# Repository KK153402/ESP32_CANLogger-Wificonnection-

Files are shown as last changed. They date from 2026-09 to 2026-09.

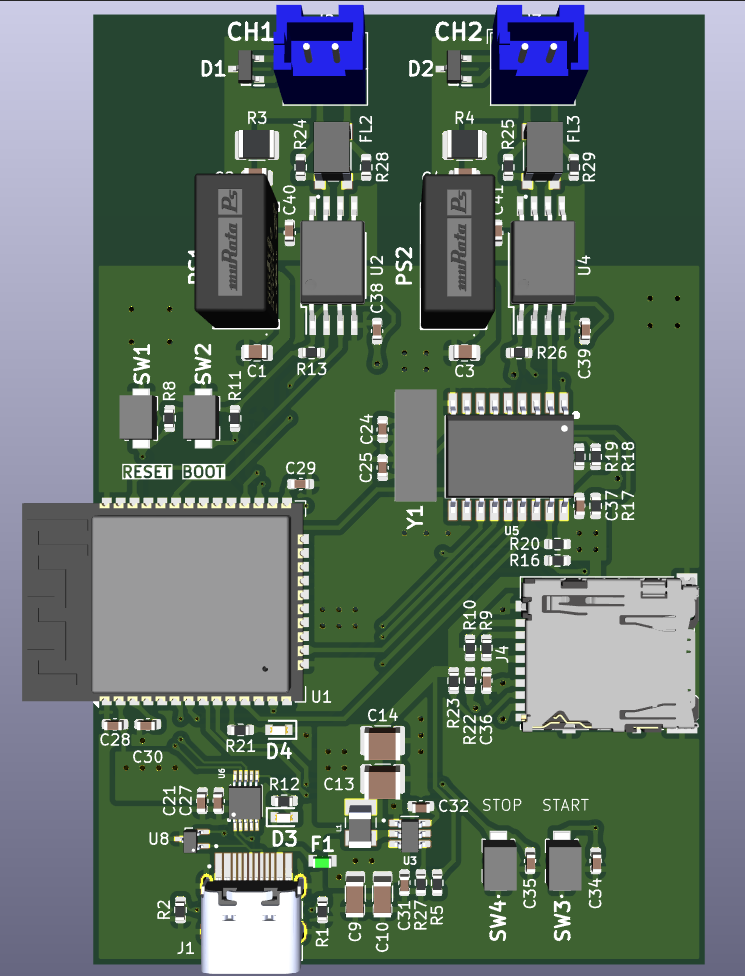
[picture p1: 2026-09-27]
images/3Dmodel_1.png

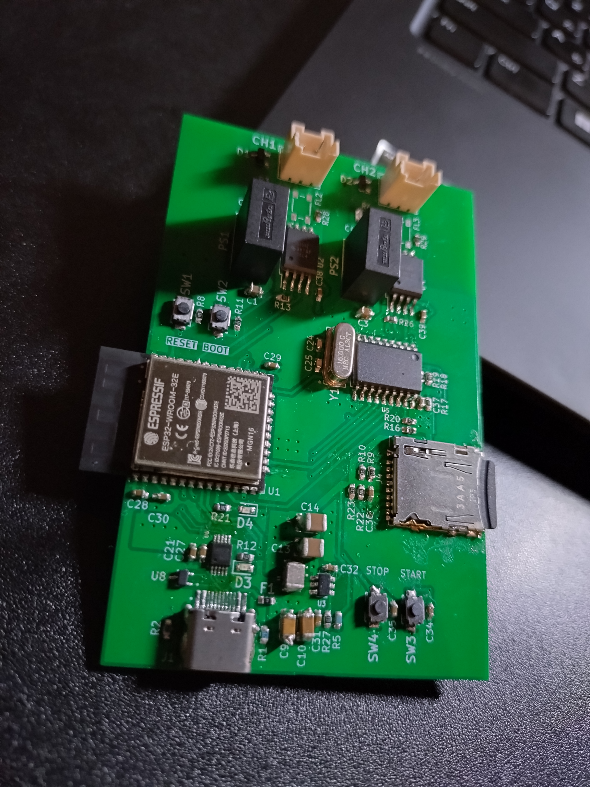
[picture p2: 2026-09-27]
images/現物.JPG

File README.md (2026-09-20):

# CanLogger

PCとCANインタフェースを持ち込めない現場で、単独でCANログを取得するための治具。
**CAN1(500kbps) / CAN2(250kbps) の2バスを同時に**SDカードへ記録し、
PC側でBLF形式へ変換してCANalyzerで解析する。

```
測定対象のCANバス ──▶ 治具（SDカードへ記録）──▶ PCでBLF変換 ──▶ CANalyzerで解析
                            │
                            └─▶ Wi-Fiで自動アップロード（v2.6〜）
```

ファームウェア **v2.7** / ハードウェア **Rev.5**

> **v2.6以降、記録したログをWi-Fi経由でサーバーへ自動送信できる。**
> 待機中にのみ動作し、記録中は完全に停止する。将来的にLTE（SIM7600JC-H）へ置き換える前提で、
> 通信方式に依存しない部分（分割・再送・進捗管理）を先に実装・検証したもの。

---

## ドキュメント

| 目的 | ファイル |
|---|---|
| **使い方**（現場での操作手順） | [`docs/USAGE.md`](docs/USAGE.md) |
| **技術解説**（プログラムの中身、初心者向け） | [`docs/TECHNICAL.md`](docs/TECHNICAL.md) |
| **設計仕様**（試算・ファイル形式・実測結果） | [`docs/DESIGN.md`](docs/DESIGN.md) |
| **ハードウェア仕様**（BOM・ピンアサイン・査読結果） | [`docs/HARDWARE.md`](docs/HARDWARE.md) |

アップロード機能について知りたい場合は、
[`docs/DESIGN.md`](docs/DESIGN.md) §7（仕様）と
[`docs/TECHNICAL.md`](docs/TECHNICAL.md) §15（設計判断の理由）を参照。

---

## 実績

実機での測定結果。

| 項目 | 結果 |
|---|---|
| CH1（500kbps） | 2,747フレーム / **取りこぼし0** |
| CH2（250kbps） | 54,263フレーム / **取りこぼし0** |
| 2ch同時記録 | 57,010フレーム / 59.16秒 |
| BLF変換 → CANalyzer再生 | **動作確認済み** |
| Wi-Fiアップロード | 1,368,272 byte を2パートで送信 / **再送・中断再開とも動作確認済み** |
| 送信速度（1MBチャンク） | 124〜166 kB/s |

---

## ハードウェア構成

```
                    ┌──── 機能絶縁境界（CH1）────┐
CN1 (CAN1 500k) ────┤ RESD1CANY → ISO1042DWV     ├─── ESP32 内蔵TWAI
                    │  NME1S0505SC + 100Ωダミー   │
                    └─────────────────────────────┘

                    ┌──── 機能絶縁境界（CH2）────┐
CN2 (CAN2 250k) ────┤ RESD1CANY → ISO1042DWV     ├─── MCP2515 (HSPI)
                    │  NME1S0505SC + 100Ωダミー   │
                    └─────────────────────────────┘

USB-C ─ TPD2E2U06 ─ MF-FSML100 ─ TPS562201 ─ 3.3V ─ ESP32-WROOM-32E-N16
                                                     ├── microSD (VSPI)
                                                     ├── MCP7940N (I2C) + CR2032
                                                     ├── 開始/停止SW、状態LED
                                                     └── CH340E (USB-UART)
```

| 主要部品 | 型番 |
|---|---|
| MCU | ESP32-WROOM-32E-N16 |
| CANトランシーバ | ISO1042DWV（絶縁）×2 |
| CANコントローラ（CH2） | MCP2515T-I/SO |
| 絶縁DC/DC | NME1S0505SC ×2 |
| RTC | MCP7940N-I/SN |
| 降圧コンバータ | TPS562201DDCR |
| USB-UART | CH340E |

詳細は [`docs/HARDWARE.md`](docs/HARDWARE.md)。

---

## ディレクトリ構成

```
CanLoggerJig/
├── platformio.ini          ビルド設定
├── src/
│   ├── main.cpp            状態機械、受信タスク、書き込みタスク、シリアルコマンド
│   ├── config.h            ピン配置・ビットレート・バッファサイズ
│   ├── ring_buffer.h       24byte固定長レコードとSPSCリングバッファ
│   ├── mcp2515.h           MCP2515ドライバ（Listen-Only、外部ライブラリ不要）
│   ├── mcp7940.h           MCP7940N RTCドライバ
│   ├── asc_format.h        ASC形式の生成（ASCモード時のみ）
│   ├── cfgfile.h           /CONFIG.TXT のパーサ
│   └── uploader.h          Wi-Fiアップロード（分割・再送・進捗管理）
├── tools/
│   ├── bin_to_blf.py       BIN → BLF 変換。ファイル形式の仕様書も兼ねる
│   ├── bin_to_blf.py.txt   同上（拡張子制限がある環境向け）
│   ├── merge_parts.py      分割パートを1つのBINへ連結
│   └── upload_server.py    検証用のHTTP PUT受信サーバ
└── docs/
    ├── USAGE.md            操作手順書
    ├── TECHNICAL.md        技術解説
    ├── DESIGN.md           設計仕様
    └── HARDWARE.md         ハードウェア仕様
```

外部ライブラリへの依存はない（`SD` / `SPI` / `Wire` / `WiFi` / `Preferences` はフレームワーク同梱）。

---

## ビルドと書き込み

### 必要なもの

- [PlatformIO Core](https://docs.platformio.org/en/latest/core/installation/)
  または VSCode + PlatformIO IDE拡張

### 手順

```bash
cd CanLoggerJig

pio run                  # ビルド
pio run -t upload        # 書き込み
pio device monitor       # シリアルモニタ（115200）
```

初回は arduino-esp32 2.0.17 のツールチェーンを自動取得するため数分かかる。

> **書き込みは手動操作が必要。** USB-UARTにCH340E（DTR#なし）を使っているため自動リセットができない。
>
> **BOOTボタンを押しながらENボタンを押して離す → BOOTを離す → `pio run -t upload`**

### ビルド環境（env）

| env | 用途 | コマンド |
|---|---|---|
| `esp32dev` | 通常構成（CH1 + CH2 + RTC）。既定 | `pio run` |
| `ch1_only` | CH1のみ。MCP2515未実装基板の検証用 | `pio run -e ch1_only -t upload` |
| `no_rtc` | RTC無し。MCP7940N未実装基板の検証用 | `pio run -e no_rtc -t upload` |
| `asc_format` | ASCテキスト保存 | `pio run -e asc_format -t upload` |

`config.h` の主要な設定値には `#ifndef` ガードがあるので、
ソースを書き換えずに `build_flags` の `-D` で上書きできる。

```ini
build_flags = -DCH2_ENABLE=0 -DCH1_BITRATE=250000UL
```

アップロード機能を外すビルドもできる。`WiFi.h` ごとリンクされなくなり、ヒープが約40KB戻る。

```ini
build_flags = -DUPLOAD_ENABLE=0
```

### バージョン固定について

`platformio.ini` で `espressif32@6.8.1`（= arduino-esp32 2.0.17）を固定している。
本ファームは `driver/twai.h` を直接使っており、arduino-esp32 3.x では
API・ヘッダ構成が変わるためビルドが通らない。

### Arduino IDE で使う場合

`src/main.cpp` は `.ino` ではないためArduino IDEでは開けない。
使う場合は `main.cpp` を `CanLoggerJig/CanLoggerJig.ino` にリネームし、ヘッダ5つを同じフォルダへ置く。
**全ての関数を呼び出し箇所より前に定義してある**ので、どちらの形式でもビルドできる。
関数を追加する際はこの順序を崩さないこと。

---

## シリアルコマンド

```bash
pio device monitor
```

| コマンド | 内容 |
|---|---|
| `SETTIME YYYY-MM-DD HH:MM:SS` | RTCに現地時刻を設定（記録中は不可） |
| `GETTIME` | 現在のRTC時刻を表示 |
| `TRIM [-127..127]` | 発振周波数の補正値を表示／設定 |
| `STATUS` | 状態・fault・ヒープ残量・RTC診断フラグ・アップロード状態 |
| `UPLOAD <LOGxxxx\|nnnn\|SCAN>` | 指定ファイルを送る／未送信を探し直す |
| `UPSTAT` | アップロードの状態を表示 |
| `WIFI` | Wi-Fiの接続状態 |
| `RELOAD` | `/CONFIG.TXT` を読み直す |
| `HELP` | コマンド一覧 |

製作時に一度 `SETTIME` すれば、CR2032が切れるまで保持される。

```
> STATUS
state=IDLE  rtc=2026-09-01 15:01:50  fault=none  freeheap=164152
rtc flags: OSCRUN=1 PWRFAIL=0 VBATEN=1 (RTCWKDAY=0x2B)  trim=+0 (+0.0 ppm)
upload  : phase=idle  boot#=4  ok=6  fail=0  sent=1715725 byte
          last: LOG0006 uploaded (2 parts)
wifi    : your-ssid  ip=192.168.10.106  rssi=-43 dBm
policy  : A (everything auto)
dest    : http://192.168.10.104:8080/canlog/JIG001/  chunk=1024 KB
```

---

## ログの自動アップロード

待機中にSDカードを走査し、未送信のログをHTTP PUTでサーバーへ送る。
**記録中は完全に停止する**ので、ログの取りこぼしには影響しない。

### 設定

SDカードのルートに `CONFIG.TXT` を置く。

```
WIFI_SSID     = your-ssid
WIFI_PASS     = your-password
UP_ENABLE     = 1
UP_AUTO       = 1          # 1=待機中に自動送信 / 0=UPLOADコマンドのみ
UP_STATS_ONLY = 0          # 1=統計TXTだけ送る
DEVICE_ID     = JIG001
UP_HOST       = 192.168.10.104
UP_PORT       = 8080
UP_PATH       = /canlog
UP_CHUNK_KB   = 1024
UP_RETRY_MAX  = 10
```

ファイルが無い場合は既定値で起動し、アップロードは無効のまま記録だけ動く。

> Wi-Fiのパスワードは平文でSDに載る。検証用の専用SSIDを使うこと。

### 受信側

検証用のサーバーを同梱している。SORACOM Harvest Files と同じ
「PUTしたパスにそのまま置く」挙動を模しているので、将来LTEへ切り替えても治具側は変わらない。

```bash
python3 tools/upload_server.py --dir ./received --port 8080
```

| オプション | 用途 |
|---|---|
| `--fail-rate 0.3` | 30%の確率で500を返す（再送処理の検証） |
| `--drop-rate 0.2` | 20%の確率で応答せず切断する |
| `--slow 50` | 1KBごとに50ms待つ（低速回線の模擬） |

### 届くファイル

```
received/canlog/JIG001/
    20260901_150227_LOG0006.txt        統計ファイル（先に送られる）
    20260901_150227_LOG0006_001.bin    ログ本体（1MBごとに分割）
    20260901_150227_LOG0006_002.bin
```

分割されたBINは連結してから `bin_to_blf.py` にかける。

```bash
python3 tools/merge_parts.py received/canlog/JIG001
```

### 設計上の要点

| 項目 | 内容 |
|---|---|
| **記録優先** | `ST_LOGGING` / `ST_DRAINING` では完全停止。開始ボタンで送信を即中断 |
| **統計ファイルを先に送る** | 数KBで「そのログが信用できるか」を遠隔判定できる |
| **1MBずつ分割** | 中断・切断時の再送単位を小さくする。固定費の実測から1MBが最適 |
| **冪等な再送** | 同一パスへの再送は上書き。何度リトライしても結果が同じ |
| **SDから消さない** | 送信済みでもカードに残す。SDが最後の砦 |
| **通信層は3関数に限定** | LTE化時は `upWifiUp` / `upWifiDown` / `upPutRange` の差し替えのみ |

詳細は [`docs/DESIGN.md`](docs/DESIGN.md) §7。

---

## PC側変換ツール

```bash
cd tools
pip install python-can

python bin_to_blf.py LOG0001.BIN -o LOG0001.blf
```

| オプション | 内容 |
|---|---|
| `-o` | 出力先。省略時は入力名 + `.blf` |
| `--start` | 計測開始の実時刻。省略時は「ヘッダの `unix_time` → それが0なら入力ファイルの更新時刻」の順 |
| `--tz-offset` | CANalyzer表示用の補正量[時間]。省略時はPCのタイムゾーン（日本なら+9） |
| `--utc` | 補正せずUTCのまま出力 |

> **タイムゾーン**: python-canはBLFヘッダへUTCを書くが、CANalyzerはそれを現地時刻として
> 表示するため、補正しないと9時間ずれる。既定で補正している（相対時刻は不変）。

BLF内のチャネル番号は 1 = CAN1 / 2 = CAN2 になり、CANalyzerの設定とそのまま一致する。

ASCモードで取得した場合は python-can 同梱のコンバータでも変換できる。

```bash
python -m can.logconvert LOG0001.ASC LOG0001.blf
```

---

## 設計上の要点

| 項目 | 内容 |
|---|---|
| **Listen-Only** | 両chともACKを返さず、バスに一切影響を与えない |
| **受信と書き込みの分離** | 受信タスクは打刻とリングへの積み込みのみ。SD書き込みは別コア |
| **リングバッファ** | SDカードの数百msの停止を吸収（実測では1024段中12段しか使用せず） |
| **バイナリ保存** | ASCテキストの約1/3のデータ量。SD速度の余裕を確保 |
| **縮退保存** | 異常時もそこまでのログと統計を必ず残す |
| **統計ファイル** | ログの信頼性を現地で判定できるようにする |
| **アップロードは待機中のみ** | 記録中はSDもCPUも奪わない。中断は1KBごとに判定 |
| **大物バッファはヒープ確保** | 通信スタックの静的領域圧迫を回避（v2.7） |

詳細な理由は [`docs/TECHNICAL.md`](docs/TECHNICAL.md)。

---

## 未了項目

**ファームウェア**

- [ ] RTCの校正（1号機は約+30ppm進む。`TRIM` で補正。[`docs/HARDWARE.md`](docs/HARDWARE.md) §11.6）
- [ ] RTC電池での時刻保持確認（電源断→復帰で `PWRFAIL=1` になること）
- [ ] ファイル自動分割（FAT32 4GB上限対策）
- [ ] **実バスでの干渉試験**（アップロード中に `ring dropped` が0のままか）
- [ ] 長時間連続試験（72時間以上。`freeheap` が単調減少しないこと）
- [ ] LTE（SIM7600JC-H）への置き換え
- [ ] 圧縮（gzip）の実装
- [ ] 遠隔コマンド（サーバー上のコマンドファイルをポーリング）
- [ ] 起動バナーと統計ファイルのバージョン文字列を `v2.7` へ更新

**ハードウェア（次版）**

- [ ] RTC水晶を **CL=6〜7pF品** へ変更（MCP7940Nは6〜9pFに最適化）
- [ ] 3.3Vバイパスコンデンサの配置割当確定（SDソケット直近を最優先）

**運用**

- [ ] 筐体設計
- [ ] 治具ラベル（「制御系CAN専用。高電圧バスに接続しないこと」）

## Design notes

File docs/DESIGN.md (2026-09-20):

# CANログ取得治具 設計仕様 v2.7（2ch同時記録 + RTC + Wi-Fiアップロード）

> ビルド手順・ディレクトリ構成はプロジェクトルートの [`../README.md`](../README.md) を参照。

PCとCANインタフェースを持ち込めない現場で、単独でCANログを取得するための治具。
CAN1(500kbps) / CAN2(250kbps) の**2バスを同時に**SDカードへ記録し、PC側スクリプトでBLFへ変換して解析側へ送る。

部品表・ピンアサイン・基板設計指針は [`HARDWARE.md`](HARDWARE.md)、
プログラムの中身の解説は [`TECHNICAL.md`](TECHNICAL.md)、
現地での操作手順は [`USAGE.md`](USAGE.md) を参照。

```
測定対象 CAN1(500k)                    測定対象 CAN2(250k)
   │                                    │
   ├ RESD1CANY → ISO1042DWV             ├ RESD1CANY → ISO1042DWV
   ├ ESP32内蔵TWAI                      ├ MCP2515 (HSPI)
   │  Listen-Only                       │  Listen-Only
   └──────┬─────────────────────────────┘
          │  rxTaskTwai / rxTaskMcp (core1) : 打刻してリングへ
          │  writerTask (core0) : 時刻順マージ → SDへ
          │
   ESP32-WROOM-32E-N16
          ├ microSD (VSPI) → LOG0001.BIN / LOG0001.TXT(統計)
          ├ MCP7940N (I2C) → 記録開始時刻
          ├ 開始/停止ボタン
          ├ 状態LED
          └ Wi-Fi → uploadTask (core0) : 待機中にHTTP PUTで送信
```

**変更履歴**

| 版 | 内容 |
|---|---|
| v1.0 | 1ch（DIPでボーレート切替）、ASCテキスト保存 |
| v2.0 | CH1+CH2同時記録（CH2にMCP2515追加）、24byte固定長バイナリ保存を既定化 |
| v2.1 | コードレビュー反映。異常時の復帰不能バグ修正と縮退保存、MCP2515サンプルポイント是正、PlatformIO化 |
| v2.2 | 基板確定に伴う対応。RTC（MCP7940N）から実時刻を取得、シリアルコマンド追加、MCP2515の/RESETをGPIO駆動 |
| v2.3 | 実機ログの解析でCH2の取りこぼしを修正（ISRのタスク切り替え要求漏れ）。§3.1参照 |
| v2.4 | v2.3で作り込んだCH2受信タスクのビジーループを修正。§3.3参照 |
| v2.5 | 査読反映。STATUSにRTC診断フラグ追加、空BIN削除、drain中fault反映、TRIMコマンド追加 |
| v2.6 | ログの自動アップロード（Wi-Fi）。分割送信・再送・進捗管理・設定ファイル。§7参照 |
| v2.7 | Wi-Fi有効時のDRAM不足を解消（リング等をヒープ確保へ）。実機検証で見つかった3件を修正。§7.9参照 |

---

## 1. 構成の考え方

### 1.1 なぜCH2をMCP2515にするか

ESP32(classic)の内蔵TWAIコントローラは**1chしかない**ため、2バス同時記録には外付けコントローラが必須。
負荷の高い500kbpsを内蔵TWAI、250kbpsをMCP2515に割り当てている。

| | CH1 = 内蔵TWAI | CH2 = MCP2515 |
|---|---|---|
| 受信バッファ | HW FIFO + ドライバキュー128段 | RXB0/RXB1の2段（BUKTロールオーバ有効） |
| ビットレート | 500 kbps | 250 kbps |
| 上限フレームレート | 約4,000 frame/s | 約2,250 frame/s |
| 連続フレームの到着間隔 | 約250 µs | 約444 µs |
| 許容サービス時間（2段） | — | 約888 µs |
| 実測見込みの読み出し時間 | — | 50〜100 µs（INT応答 + SPI 14byte @10MHz） |

CH2は余裕率およそ8倍あり、250kbpsであれば2段バッファでも成立する。
**将来CH2も500kbpsにする場合は許容時間が約500µsまで縮む**ので、その時は再評価が必要。

### 1.2 Listen-Onlyで動かす

両chともACKを返さない完全な受信専用モードで動作するため、バスに一切影響を与えない。
その代わり**ボーレートを間違えてもエラーを出さず「0件で終わる」**。
統計ファイルにCH1/CH2それぞれの受信0件警告を出すようにしている。

---

## 2. スループット試算

### 2.1 「取得したい信号数1000〜2000」の解釈

これはDBC上の**シグナル数**であり、治具の負荷とは直接関係しない。
治具はDBCを持たず生フレームを丸ごと記録するので、シグナルが何本あっても動作は変わらない。
効くのは**フレームレート [frame/s]** だけ。デコードはPC側の CANalyzer + DBC で行う。

### 2.2 物理上限（設計最悪値）

| チャネル | 条件 | 上限フレームレート |
|---|---|---|
| CH1 | 500 kbps / 8byte | 約3,800〜4,500 frame/s |
| CH2 | 250 kbps / 8byte | 約1,900〜2,250 frame/s |
| 合計 | — | **約6,250 frame/s** |

### 2.3 データ量とSD書き込み速度

| 保存形式 | 1フレーム | 6,250 frame/s | 10分 | 1時間 |
|---|---|---|---|---|
| **バイナリ（既定）** | 24 byte | 約150 kB/s | 約90 MB | 約540 MB |
| ASCテキスト | 約64 byte | 約400 kB/s | 約240 MB | 約1.4 GB |

Arduino-ESP32 標準 `SD`（SPI 20MHz）の実効書き込み速度は概ね300 kB/s〜1 MB/s。
2ch同時記録でASCテキストを選ぶと400 kB/sとなり成立しないカードが出てくるため、
**既定を24byte固定長バイナリにしている**。150 kB/s なら十分な余裕がある。

ASCモードは `pio run -e asc_format` で使える。現地でテキストとして中身を確認したいときのデバッグ用。

### 2.4 バッファ設計

| リング | 段数 | サイズ | 吸収できるSD停止時間 |
|---|---|---|---|
| CH1 | 2048 | 約49 KB | 約0.5秒（4,000 frame/s時） |
| CH2 | 1024 | 約25 KB | 約0.45秒（2,250 frame/s時） |

安価なSDカードは内部GCで数百ms書き込みが止まることがあるため、その吸収が目的。
記録終了時に `ring max used` を統計ファイルへ残すので、実機で余裕を確認したうえで
`config.h` の `RING_SIZE_CH1 / RING_SIZE_CH2` を調整できる。

ESP32-WROOM-32E-N16 のフラッシュは16MBだが**SRAMは520KB**（実使用可能なDRAMは約320KB）。
リングを増やす際はヒープ残量（起動時にシリアルへ出力する）を確認すること。

### 2.5 記録時間の上限

FAT32の1ファイル上限は4GB。バイナリ150 kB/s なら約7.4時間まで1ファイルで記録できる。
「10分程度」の要求に対しては十分だが、それ以上を常用するならファイル自動分割（今後の課題）を入れる。

---

## 3. 実機測定の結果（2026-08-10 / LOG0002）

測定対象のCH2（250kbps）に接続して6.16秒間記録した結果。

| 項目 | 値 |
|---|---|
| フレーム数 | 4,426（平均 719 frame/s） |
| ID種類数 | 40（標準ID 25 + 拡張ID 15） |
| 周期構成 | 10ms×6種、20ms×3種、100ms×多数、1000ms×多数 |
| `bus err alerts` | 0 |
| リング最大使用 | 12 / 1024 |
| SD書き込み最大 | 4,831 µs |

**実測フレームレート719 frame/s** は設計最悪値（CH2で2,250 frame/s）に対して3割程度。
リングバッファも1024段中12段しか使っておらず、**SD側・バッファ側は大幅に余裕がある**ことが確認できた。

### 3.1 v2.2で発生していた取りこぼしと修正

周期メッセージの欠落を数えたところ、**全体の1.21%（54フレーム）**が失われていた。
特にID 341（20ms周期）は17.3%が欠落。

原因は `mcpIsr()` で `portYIELD_FROM_ISR()` を行っていなかったこと。
`vTaskNotifyGiveFromISR()` の第2引数に `nullptr` を渡していたため、
ISRから抜けるときにタスク切り替えが要求されず、**CH2受信タスクの起床が
次のティック（最大1ms）まで遅れていた**。

測定データがこれを裏付けている。

| 観測 | 内容 |
|---|---|
| 1回の起床で読んだフレーム数 | 1件…1,672回 / **2件…1,311回** / 3件…44回 |
| 起床間隔の最小値 | **999 µs**（1000µs未満は3,026回中わずか9回） |

250kbpsでは8byteフレームが約444µs間隔で到着するため、1ms待つと
MCP2515のRXB0/RXB1がちょうど埋まり、3フレーム目で溢れる。

**v2.3での修正**

1. `mcpIsr()` で `portYIELD_FROM_ISR()` を実行する（起床遅延を1ms → 数十µsへ）
2. `/INT` がLowの間は通知を待たずに読み出しを継続する
   （MCP2515の `/INT` はレベル出力のため、ドレイン中に届いたフレームでは
   新しい立ち下がりエッジが出ず、エッジ検出を取りこぼす経路があった）

### 3.2 v2.3で作り込んだ不具合（v2.4で修正）

v2.3で `/INT` のレベルチェックを追加した際、**「記録中でない」判定をその後ろに置いてしまった**。

```cpp
if (digitalRead(MCP_INT_GPIO) == HIGH) {   // Lowだとここを通らない
  ulTaskNotifyTake(...);
}
if (g_state != ST_LOGGING || !g_mcpReady) continue;   // 待機中はここで戻る
```

**CH2をバスに接続した待機状態**では `/INT` がLowに張り付くため、
どこでもブロックせずにループが回り続ける。このタスクは優先度19でコア1に固定されており、
優先度1の `loopTask`（`setup()` と `loop()` が動く）を完全に飢餓状態にする。

症状は次のとおりで、CH2を接続していない環境では再現しない。

- `setup()` の最後の2行（`free heap after init` / `type HELP ...`）が出力されない
- シリアルコマンドが一切効かない
- 開始/停止ボタンが効かない
- LEDが更新されない（消灯のまま）

**v2.4での修正**: 状態判定を先頭へ移し、記録中でなければ必ず `vTaskDelay()` で眠るようにした。
あわせて、`/INT` がLowのままフレームが読めない異常時の保険として、
1件も読めなかった場合に `vTaskDelay(1)` を入れている。

### 3.3 タイムスタンプ精度について（解析側への申し送り）

ESP32のTWAIもMCP2515も**ハードウェア受信タイムスタンプを持たない**。
本ファームは受信タスクがフレームを取り出した時刻を打刻している。

| 項目 | CH1（内蔵TWAI） | CH2（MCP2515） | PC接続型インタフェース |
|---|---|---|---|
| タイムスタンプ源 | ソフトウェア（esp_timer, 1µs分解能） | 同左（INT応答分の遅れが加わる） | ハードウェア |
| 通常時の誤差 | ±数十µs | ±100µs程度 | ns〜µs |
| バースト時 | キュー滞留分だけ遅れる（最大数ms） | 同左 | 影響なし |
| ch内のフレーム順序 | 保証される | 保証される | 保証される |
| エラーフレーム | **記録不可**（統計カウントのみ） | **記録不可**（同左） | オブジェクトとして記録 |

**ch間の相対時刻は同じesp_timerで打刻しているので比較可能**だが、上記の誤差が乗る。

RTC（MCP7940N）が与えるのは「計測開始が実世界の何時何分か」というアンカーだけで、
フレーム間隔の精度には関与しない。

本治具のログは**シーケンスと中身の解析**用と位置づけ、バス負荷率・フレーム間ギャップ・
エラーフレーム解析が必要な案件はPC接続型のCANインタフェースで取得する、という線引きを
治具の配布前に関係者間で合意しておきたい。

---

## 4. LED表示と異常時の挙動

| 状態 | LED | 意味 |
|---|---|---|
| 待機 | 消灯 | 電源ON・SD認識済み・MCP2515疎通OK。開始ボタン待ち |
| **アップロード中** | **1秒周期で短点滅2回** | **待機中にログを送信している。SDを抜かないこと** |
| 記録中 | 200ms周期で点滅 | CANログ取得中。SDを抜かないこと |
| 停止 | 点灯（continuous） | ファイルクローズ完了。**SD取り外し可** |
| 異常 | 80ms周期で高速点滅 | 下表参照。開始ボタンで再試行 |

停止処理（残データの書き出しとファイルクローズ）が終わってから点灯に切り替わるので、
**LEDが点灯したことがSD取り外し可の合図**になる。

アップロード中は点滅が `ST_STOPPED` の点灯を上書きする。
結果として「点灯に戻るまで待てばSD抜去が安全」という動作になり、都合がよい。

記録中に異常が起きた場合も、いきなり高速点滅に移るのではなく
**そこまでのログの書き出し・ファイルクローズ・統計ファイル出力を済ませてから**高速点滅になる（縮退保存）。
そのため異常終了でも `LOG0001.BIN` と `LOG0001.TXT` は残り、統計ファイルの `fault` 行に要因が記録される。

| fault | 意味 |
|---|---|
| `SD card not found / mount failed` | SDカード未挿入または認識不良 |
| `cannot create log file on SD` | 書き込み保護／FAT破損／容量不足 |
| `SD write failed (card full or bad contact)` | 記録中の書き込み失敗。容量または接触を確認 |
| `CH1 TWAI driver init failed` | 内蔵TWAIの初期化失敗（通常は起こらない。要報告） |
| `CH2 MCP2515 not responding` | MCP2515のSPI疎通不良（基板不良・はんだ不良） |
| `CH1 bus off` | CH1がBus Off（Listen-Onlyでは通常起こらない。要報告） |

高速点滅からは**開始ボタンで復帰できる**（内部の後始末をやり直してから記録を開始する）。
復帰しない場合は電源を入れ直す。

なお**RTCの異常では停止しない**。時刻が読めない場合は `unix_time = 0` として記録を続行し、
統計ファイルに注記を残す。

---

## 5. 操作手順（概要）

1. 治具の電源を入れる（LED消灯＝待機。高速点滅ならSDカードを確認）
2. CH1コネクタを500kbps側、CH2コネクタを250kbps側の取得ポイントへ接続する
3. **開始ボタン**を押す → LEDが点滅を始める
4. 事象を再現させる
5. **停止ボタン**を押す → LEDが点灯に変わるまで待つ
6. LED点灯後にSDカードを抜く（点滅中に抜くとファイルが壊れる）
7. `LOG0001.TXT` を開き、以下を確認する
   - `exit` が `normal (stop button)` であること
   - `start time` が正しいこと（大きくずれていればRTCの電池切れ）
   - CH1 / CH2 それぞれの `frames logged` が0でないこと
   - `ring dropped` / `ctrl missed` / `ctrl ovf events` がすべて0であること
   - `*** WARNING` の行が無いこと（すべて問題なければ `result : OK` が出る）
8. `LOG0001.BIN` と `LOG0001.TXT` を解析側へ送付する

> **`ctrl ovf events` の読み方**
> この値はMCP2515のオーバフロービットを200ms周期でポーリングして検出した**回数**であり、
> 落ちたフレーム数ではない（1回のカウントに複数フレームの欠落が含まれ得る）。
> **0でなければ取りこぼしあり、数は不定**と判断する。
> CH1側の `ctrl missed` はドライバがフレーム数で数えているのでこちらは実数。

---

## 6. 出力ファイルとBLF変換

### 6.1 LOG0001.BIN（既定）

リトルエンディアン。ヘッダ32byte + 24byte固定長レコード × N。

**ヘッダ 32byte**

| offset | 型 | 内容 |
|---|---|---|
| +0 | char[8] | magic `"CANLOG02"` |
| +8 | uint16 | version = 2 |
| +10 | uint16 | record_size = 24 |
| +12 | uint32 | CH1 ビットレート [bps] |
| +16 | uint32 | CH2 ビットレート [bps]（0ならCH2無効） |
| +20 | uint32 | 計測開始のUNIX時刻（**UTC**）。0ならRTC無効/未設定 |
| +24 | uint64 | t0_us：計測開始時刻（治具のesp_timer基準） |

**レコード 24byte**

| offset | 型 | 内容 |
|---|---|---|
| +0 | uint64 | ts_us：受信時刻（esp_timer基準の絶対値） |
| +8 | uint32 | ID（11bit または 29bit） |
| +12 | uint8 | DLC（0..8） |
| +13 | uint8 | flags：bit0 = 29bit ID / bit1 = リモートフレーム |
| +14 | uint8 | channel：1 = CH1 / 2 = CH2 |
| +15 | uint8 | reserved（0固定） |
| +16 | uint8[8] | データ |

レコードは**チャネル内では時刻順**だが、チャネル間の順序は保証していない
（ファーム側で約5msのマージ窓を持たせているが、保険としてPC側で必ず時刻ソートする）。

### 6.2 BLFへの変換

```bash
pip install python-can
python tools/bin_to_blf.py LOG0001.BIN -o LOG0001.blf
```

RTCが動作していれば `unix_time` が入っているので、**開始時刻の手入力は不要**。
省略時は「ヘッダの `unix_time` → それが0なら入力ファイルの更新時刻」の2段フォールバックになる。
明示指定したい場合のみ `--start "2026-08-09 14:05:00"` を使う。

BLF内のチャネル番号は 1 = CAN1 / 2 = CAN2 になり、CANalyzerの設定とそのまま一致する。

#### タイムゾーンの扱い

治具は `unix_time` に**UTC**を格納する。一方 python-can は BLFヘッダの計測開始時刻
（SYSTEMTIME）へ**UTCをそのまま書き込む**が、**CANalyzer はこのフィールドを
現地時刻として表示する**。そのため補正しないと、CANalyzer 上で9時間前にずれる。

`bin_to_blf.py` は**既定で現地のUTCオフセットを全タイムスタンプに加算**し、
CANalyzer に現地時刻が表示されるようにしている。
全フレームを同じ量だけずらすので、**フレーム間の相対時刻は変わらない**（実データ4,426件で検証済み）。

| オプション | 動作 |
|---|---|
| （既定） | このPCのタイムゾーンで補正。日本なら +9時間 |
| `--tz-offset 9` | 補正量を時間単位で明示指定 |
| `--utc` | 補正せずUTCのまま出力（従来動作） |

治具の記録開始が 15:02:27（JST）の場合の表示。

| モード | CANalyzer の Start |
|---|---|
| 既定 | **2026-09-01 15:02:27** |
| `--utc` | 2026-09-01 06:02:27 |

**動作確認済み**: python-can 4.6.1 にて、C側の構造体（`ring_buffer.h` の `CanRec` / `BinHeader`）で
書き出したバイナリを `bin_to_blf.py` でBLF化し、`can.BLFReader` で読み戻して
標準ID / 29bit ID / リモートフレーム / DLC=0 / 2chの時刻順マージ / RTC時刻の反映
が欠落なく往復することを確認した。ASC経路（`asc_format.h` → `can.logconvert` → BLF）も確認済み。

### 6.3 LOG0001.TXT（統計）

CH1/CH2ごとのフレーム数・取りこぼし数・リング最大使用量、SD書き込み最大所要時間、
記録開始時刻、終了種別（`exit`）と異常要因（`fault`）を記録する。
**ログの信頼性判定はこのファイルで行う。** 読み方は §5 の手順7を参照。

---

## 7. ログの自動アップロード（v2.6 / v2.7）

記録したログをWi-Fi経由でサーバーへ自動送信する。
将来的にLTE（SIM7600JC-H）へ置き換えて遠隔回収する計画で、
**通信方式に依存しない部分を先に作って検証する**のがこの実装の位置づけ。

設計判断の背景は [`TECHNICAL.md`](TECHNICAL.md) §15 を参照。

### 7.1 目的と優先順位

| # | 目的 | 重み |
|---|---|---|
| 1 | 現地へ行かずに「録れたか」「そのログは信用できるか」を確認する | **最優先** |
| 2 | ログ本体を回収する | 二番目 |

統計ファイル（`LOGxxxx.TXT`、1〜2KB）には `exit` / `ring dropped` / `ctrl missed` が入っており、
**数KBの通信だけでログの信頼性を判定できる**。
このため統計ファイルをログ本体より**先に**送る。

### 7.2 大原則

> **LTE/Wi-Fiが動かなくても、記録機能は絶対に止めない。**
> **記録中はアップロードを一切動かさない。**

動作条件は1か所（`upCanRun()`）で判定する。

| 状態 | アップロード |
|---|---|
| `ST_LOGGING` / `ST_DRAINING` | **停止** |
| `FAULT_SD_INIT` / `FAULT_SD_WRITE` | **停止** |
| `ST_IDLE` / `ST_STOPPED` / `ST_ERROR`（SD以外の異常） | 動作 |

`ST_ERROR` でも動かすのは、そこまでのログを回収したいため。

### 7.3 中断のハンドシェイク

開始ボタンが押されたとき、`startLogging()` は次の順で手放させてから記録を始める。

```
uploaderRequestStop()    中断を要求
uploaderWaitIdle(3000)   SDハンドルを閉じるまで待つ
uploaderWifiOff()        Wi-Fiを落とす
  ↓
hardCleanup() / SD.end() / SD.begin()
```

**順序を逆にすると、アップロード側が握っている `File` が無効なまま参照される。**

中断判定は送信ループの1KBごとに入れており、実測で数十msで抜ける。

### 7.4 タスク構成

```
Core 1 : rxTaskTwai(20) / rxTaskMcp(19) / loop(1)
Core 0 : writerTask(5) / uploadTask(3)      ← 追加
```

優先度3は `writerTask` より低い。送信ループには1KBごとに `vTaskDelay(1)` を入れており、
`loop()` を飢餓状態にしない（v2.3のバグ2と同種の事故を避けるため）。

### 7.5 送信の単位とパス

| part | 中身 |
|---|---|
| 0 | 統計ファイル `LOGxxxx.TXT` |
| 1..N | ログ本体を `UP_CHUNK_KB` ごとに分割したもの |

```
<UP_PATH>/<DEVICE_ID>/<stamp>_LOG0006.txt
<UP_PATH>/<DEVICE_ID>/<stamp>_LOG0006_001.bin
<UP_PATH>/<DEVICE_ID>/<stamp>_LOG0006_002.bin
```

`stamp` はBINヘッダの `unix_time` から作った `YYYYMMDD_HHMMSS`。RTC未設定なら `nortc`。
**LOG番号を必ず含めるので、RTCが壊れていてもSDカード内で一意になる。**

PC側では `tools/merge_parts.py` で連結してから `bin_to_blf.py` にかける。

### 7.6 分割サイズの根拠（実測）

| チャンクサイズ | 実効速度 | 1パートあたりの固定費 |
|---|---|---|
| 16 KB | 89〜94 kB/s | **約80 ms** |
| **1024 KB（既定）** | **124〜166 kB/s** | 無視できる |

固定費はTCP接続とHTTP往復に由来する。
**LTEではATコマンドの往復（`AT+HTTPINIT` 〜 `AT+HTTPTERM`）が毎パート発生するため、この固定費はさらに大きくなる。**

| チャンク | 1MBログの送信時間（LTE概算） |
|---|---|
| 16 KB | 64パート × 約12秒 ≈ 13分 |
| 1024 KB | 1パート × 約12秒 ≈ 12秒 |

**既定の1024KBを維持すること。** SORACOM Harvest Files のセルラー経由上限（100 MiB）にも収まる。

### 7.7 壊れたファイルを残さない

HTTP PUTは `Content-Length` を先に宣言するため、途中で切れるとサーバー側が検出できる。

```
[23:48:41] SHORT  .../LOG0006_001.bin  7168/1048576 byte   ← 400で拒否
[23:49:02] PUT OK .../LOG0006_001.bin  1048576 byte        ← 再送で上書き
```

**同一パスへの再送は上書きになるため、リトライは冪等**。
SORACOM Harvest Files も同じ挙動なので、LTE化しても変わらない。

### 7.8 進捗の管理（/UPLOADED.TXT）

追記のみのテキスト。

```
0006,P,000,1024        part 0（統計TXT）完了。末尾はチャンクサイズ[KB]
0006,P,001,1024        part 1 完了
0006,D,002,1368272     全パート完了（総パート数, 総バイト数）
```

起動時に `D` の行を読んで完了ビットマップ（1250バイト）を作る。
再開時は該当LOG番号の最大 `P` を探し、その次のパートから送る。

**チャンクサイズを一緒に記録しているのが要点。**
パート番号はチャンクサイズを前提にした値なので、設定を変えると同じ番号でも指すオフセットが変わる。
照合して不一致なら進捗を無効とし、先頭から送り直す。

**送信できたファイルもSDからは削除しない。** SDカードが最後の砦であるため。

### 7.9 メモリ設計の変更（v2.7）

Wi-Fiスタックが約40KBの静的バッファを持ち込むため、リングバッファを静的確保したままでは
リンクが通らなくなった。

```
region `dram0_0_seg' overflowed by 2488 bytes
```

ESP32の静的データ（`.bss`）は固定サイズ領域に収める必要があり、ヒープはその外側のDRAMも使える。
そこで大物をヒープ確保へ移した。

| バッファ | サイズ | v2.6まで | v2.7 |
|---|---|---|---|
| `g_ring1` | 49,152 B | 静的 | **ヒープ** |
| `g_ring2` | 24,576 B | 静的 | **ヒープ** |
| `g_wbuf` | 4,176 B | 静的 | **ヒープ** |

確保は `setup()` でタスク生成より前に行い、失敗したら `FAULT_NO_MEMORY` で `ST_ERROR` へ落とす。

実測値は次のとおり。

| 時点 | `freeheap` |
|---|---|
| 起動直後 | 297,220 byte |
| **初期化完了後** | **164,152 byte** |

**リングサイズの制約は「静的領域に入るか」から「ヒープに余裕があるか」に変わった。**

### 7.10 設定ファイル（/CONFIG.TXT）

SSIDや送信先をソースに直書きすると、変更のたびに再ビルドと手動書き込み（BOOT+EN）が必要になる。
SDカードのルートに置いたテキストから読む。

```
WIFI_SSID     = your-ssid
WIFI_PASS     = your-password
UP_ENABLE     = 1
UP_AUTO       = 1
UP_STATS_ONLY = 0
DEVICE_ID     = JIG001
UP_HOST       = 192.168.10.104
UP_PORT       = 8080
UP_PATH       = /canlog
UP_CHUNK_KB   = 1024
UP_RETRY_MAX  = 10
```

| 項目 | 仕様 |
|---|---|
| パーサ | 自前実装。**外部ライブラリ非依存・動的メモリ確保なし** |
| 不在時 | 既定値で起動。`WIFI_SSID` が空ならアップロードは無効のまま動く |
| 不正時 | 該当行を無視して警告を出し、**起動は継続する** |
| 再読込 | シリアルコマンド `RELOAD` |

> **Wi-Fiのパスワードは平文でSDに載る。** 検証用の専用SSIDを使うこと。LTE化で解消される。

### 7.11 実機検証の結果

| # | 検証項目 | 結果 |
|---|---|---|
| 1 | 基本のアップロード | OK（6ファイル連続、`fail=0`） |
| 2 | 分割送信 | OK（1,368,272 byte → 2パート） |
| 3 | データ整合性 | OK（`merge_parts.py` で `frames=57010`。統計の CH1 2747 + CH2 54263 と一致） |
| 4 | チャンクサイズ変更時の進捗リセット | OK |
| 5 | **中断時に不完全ファイルを残さない** | OK（400拒否 → 再送で上書き） |
| 6 | **記録中のゲート** | OK（`phase=blocked`） |
| 7 | **中断された指定要求の再開** | OK（`resume from 1` で続きから完走） |
| 8 | 中断を失敗に数えない | OK（2回中断しても `fail=0`） |
| 9 | 記録終了後の自動継続 | OK |

**未検証: 「アップロードがCAN受信を妨げていないか」**は実バスが必要なため持ち越し。
設計上は記録中にアップロードタスクが完全停止するため問題ないはずだが、
`ring dropped = 0` を実測で押さえること。

### 7.12 検証で見つかった不具合（すべて修正済み）

| # | 不具合 | 原因 | 対策 |
|---|---|---|---|
| 1 | `UP_STATS_ONLY=1` のとき手動コマンドでもBINが送られない | 自動／手動を区別せず設定フラグを見ていた | 明示指定時は設定を無視する |
| 2 | チャンクサイズを変えると欠けたファイルができる | 進捗記録がチャンクサイズを持っていなかった | 進捗行に記録し、不一致なら無効化 |
| 3 | 中断された `UPLOAD` 指定が消える | 「指定」と「走査やり直し」を同じ変数に入れていた | 別変数に分離し、指定を優先 |

不具合3は**遠隔コマンドでログを取りに行く運用では致命的**だった。
記録が終わるたびに必ず走査要求が出るため、中断された指定要求は100%失われていた。
詳細は [`TECHNICAL.md`](TECHNICAL.md) §16 バグ6〜8。

### 7.13 LTE化への引き継ぎ

差し替えるのは3関数のみ。

| 関数 | Wi-Fi版 | LTE版 |
|---|---|---|
| `upWifiUp()` | `WiFi.begin()` | ロードスイッチON、`AT` 応答待ち、`AT+CNMP=38`、`AT+CGACT` |
| `upWifiDown()` | `WiFi.mode(WIFI_OFF)` | `AT+CPOF` → 無応答確認 → ロードスイッチOFF |
| `upPutRange()` | `WiFiClient` で直接PUT | `AT+HTTPINIT` → `AT+HTTPDATA` → `AT+HTTPACTION=1` |

**`upPutRange()` の引数と戻り値（remotePath, File&, offset, length → bool）を変えないこと。**

送信先をHarvest Filesにする場合は設定を変えるだけでよい。

```
UP_HOST = harvest-files.soracom.io
UP_PORT = 80
```

---

## 8. RTC（MCP7940N）の時刻設定

RTCには**現地時刻（日本時間）**を設定する。ファームウェアがUTCへ変換して保存するため、
PC側で正しい時刻が表示される。

```
pio device monitor
> SETTIME 2026-08-09 14:05:00
[OK] RTC set to 2026-08-09 14:05:00 (local)
```

| コマンド | 内容 |
|---|---|
| `SETTIME YYYY-MM-DD HH:MM:SS` | RTCに現地時刻を設定（記録中は不可） |
| `GETTIME` | 現在のRTC時刻を表示 |
| `TRIM [-127..127]` | 発振周波数の補正値を表示／設定（`HARDWARE.md` §11.6） |
| `STATUS` | 状態・fault・ヒープ残量・**RTC診断フラグ**・アップロード状態 |
| `UPLOAD <LOGxxxx\|nnnn\|SCAN>` | 指定ファイルを送る／未送信を探し直す |
| `UPSTAT` | アップロードの状態を表示 |
| `WIFI` | Wi-Fiの接続状態 |
| `RELOAD` | `/CONFIG.TXT` を読み直す |
| `HELP` | コマンド一覧 |

`STATUS` はRTCの診断フラグを出す。電源断→復帰テストで失敗したときの切り分けに使う。

```
rtc flags: OSCRUN=1 PWRFAIL=0 VBATEN=1 (RTCWKDAY=0x29)  trim=+0 (+0.0 ppm)
```

| フラグ | 意味 |
|---|---|
| `OSCRUN=0` | 発振していない（`SETTIME` 未実行か水晶の問題） |
| `VBATEN=0` | **バックアップ無効**。電源断で時刻が消える |
| `PWRFAIL=1` | 電源断からの復帰履歴あり（正常な表示） |

タイムゾーンは `config.h` の `RTC_UTC_OFFSET_SEC`（既定 JST = UTC+9）で変更できる。

**製作時に一度設定すれば、CR2032が切れるまで保持される。**
精度は外部水晶次第（温度補償なし）だが、必要なのは秒〜分オーダーなので実用上問題ない。

電池交換後や発振が止まっている場合は `unix_time = 0` として扱われ、記録は続行される。
起動時にシリアルへ警告が出るので、その場合は `SETTIME` で再設定する。

| 起動時メッセージ | 意味 |
|---|---|
| `MCP7940N: 2026-08-09 14:05:00 (local)` | 正常 |
| `oscillator not running. check crystal / load caps.` | **水晶が発振していない**（負荷容量の不整合・実装不良） |
| `time not set. use SETTIME command.` | 時刻未設定 |
| `MCP7940N not responding` | I2C疎通不良 |

---

## 9. ビルド環境

- **PlatformIO** / `espressif32@6.8.1`（= arduino-esp32 2.0.17）
- ボード: `esp32dev` / Flash Size 16MB
- 追加ライブラリ: **なし**（`SD` / `SPI` / `Wire` はフレームワーク同梱、
  MCP2515・MCP7940Nドライバは自作で同梱）

```bash
pio run                 # ビルド
pio run -t upload       # 書き込み（BOOT+ENを押してダウンロードモードにしてから）
pio device monitor      # シリアルモニタ（115200）
```

### バージョン固定の理由

本ファームは `driver/twai.h` を直接使っており、**arduino-esp32 3.x ではAPI・ヘッダ構成が変わるため
ビルドが通らない**。3.x系はEspressifがPlatformIO公式サポートを終了し pioarduino フォークへ
移行しているため、公式プラットフォームを使う限りこの制約は自然に満たされるが、
再現性のため `platformio.ini` で明示的に固定している。

### 書き込みは手動

CH340EはDTR#を持たないため自動リセットができない。
**BOOTボタンを押しながらENボタンを押して離す → BOOTを離す → 書き込み**。

### ファイル構成

| ファイル | 内容 |
|---|---|
| `platformio.ini` | ビルド設定（プラットフォーム/ボード/env） |
| `src/main.cpp` | 状態機械、CH1/CH2受信タスク、書き込みタスク、縮退保存、シリアルコマンド |
| `src/config.h` | ピン配置・ビットレート・バッファサイズ・保存形式・RTC設定 |
| `src/ring_buffer.h` | 24byte固定長レコード定義とSPSCリングバッファ |
| `src/mcp2515.h` | MCP2515 受信専用ドライバ（Listen-Only、外部ライブラリ不要） |
| `src/mcp7940.h` | MCP7940N 用ドライバ（時刻の読み書きのみ） |
| `src/asc_format.h` | ASC 1行の生成（float未使用。ASCモード時のみ使用） |
| `src/cfgfile.h` | `/CONFIG.TXT` のパーサ（外部ライブラリ非依存） |
| `src/uploader.h` | アップロード本体（Wi-Fi接続・HTTP PUT・分割・再送・進捗管理） |
| `tools/bin_to_blf.py` | PC側 BIN → BLF 変換。ファイル形式の仕様書も兼ねる |
| `tools/merge_parts.py` | 分割パートを1つのBINへ連結する |
| `tools/upload_server.py` | 検証用のHTTP PUT受信サーバ（故障注入オプション付き） |

構成違いは `platformio.ini` の env で切り替える。

| env | 用途 |
|---|---|
| `esp32dev` | 通常構成（既定） |
| `ch1_only` | CH1のみ（MCP2515未実装の試作基板） |
| `no_rtc` | RTC無し（MCP7940N未実装の試作基板） |
| `asc_format` | ASCテキスト保存 |

アップロード機能を外すビルドもできる。`WiFi.h` ごとリンクされなくなり、ヒープが約40KB戻る。

```ini
build_flags = -DUPLOAD_ENABLE=0
```

### Arduino IDE で使う場合

`src/main.cpp` は `.ino` ではないためArduino IDEのスケッチとしては開けない。
使う場合は `main.cpp` を `CanLoggerJig/CanLoggerJig.ino` にリネームし、ヘッダを同じフォルダへ置く。
`#include <Arduino.h>` は既に入れてあり、全関数を呼び出し箇所より前に定義してあるので
プロトタイプ宣言の追加も不要。

---

## 10. 未決事項

1. **実バスのフレームレート** — CANalyzerで CH1/CH2 それぞれの `Statistics`
   （バス負荷率・frame/s）を実測してもらえれば、リングサイズとSD速度要求を確定できる。
   現状は物理上限（合計6,250 frame/s）で設計している
2. **コネクタの誤挿入** — 相手側（測定対象側）が両chとも B02B-XASK-A のため、
   治具側で形状を分けられない。ケーブルの色分け／シルク印字に加え、
   **統計ファイルで両chとも `frames logged` が0でないことを確認する手順**で検出する。
   CAN_GND端子が無い点は残課題（`HARDWARE.md` §12.3）
3. **CH2も500kbpsになる可能性** — ある場合、MCP2515の2段バッファの余裕率が
   約8倍から約2倍に下がる。事前に分かれば設計を見直す
4. **USBメモリ対応** — ESP32(classic)はUSBホスト機能を持たないためSDカードのみ。
   USBメモリが要件なら ESP32-S3 + USB OTG への変更が必要

---

## 11. 今後の作業

- [ ] 回路図への R/C 定数入力（`HARDWARE.md` §4 の定数表）
- [ ] 3.3Vバイパスの配置割当を確定（`HARDWARE.md` §4.3。SDソケット用を最優先）
- [ ] PCBレイアウト（絶縁境界、TVS/ESD配置、SPI分離）
- [ ] 実機での取りこぼし検証（`LOG0001.TXT` の dropped / missed が0になるまで）
- [ ] MCP2515ドライバの実機動作確認（ビットタイミング、INT応答、BUKTロールオーバ）
- [ ] サンプルポイント設定の妥当性確認（CH2=87.5% / CH1=80%）
- [ ] 異常系の動作確認（記録中のSD抜去、開始ボタンでの復帰）
- [ ] RTCの時刻保持確認（電源断→復帰）
- [ ] ファイル自動分割（FAT32 4GB上限対策）
- [ ] **実バスでの干渉試験**（アップロード中に `ring dropped` が0のままか）
- [ ] 長時間連続試験（72時間以上。`freeheap` が単調減少しないこと）
- [ ] LTE（SIM7600JC-H）への置き換え
- [ ] 圧縮（gzip）の実装。転送時間と通信料の削減
- [ ] 遠隔コマンド（サーバー上のコマンドファイルをポーリング）
- [ ] 筐体設計

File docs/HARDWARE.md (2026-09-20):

# CANログ取得治具 ハードウェア仕様 Rev.5（基板設計着手版）

対象ファームウェア: `CanLoggerJig` v2.5
動作仕様・スループット試算は [`DESIGN.md`](DESIGN.md)、
プログラムの中身の解説は [`TECHNICAL.md`](TECHNICAL.md) を参照。

Rev.5 で反映した内容
- **RTC を MCP7940N-I/SN へ変更**（外部32.768kHz水晶が必要。§11）

Rev.4 で反映した内容
- ヒューズを **MF-FSML100/8-2** に確定（0603 / 耐圧8VDC）
- USB D+/D- に **TPD2E2U06DCKR**（ESD保護）を追加
- CMC バイパス用の **0Ω ジャンパを部品化**（DNP時の断線を防止）
- 絶縁2次側のネット名を `GND2_CH1` / `GND2_CH2` へ改名
- 未使用ピンにテストポイントを配置
- R / C の定数表（§4）を追加

> **ピン番号について** — ICは**信号名で記載**している。ピン番号は各ICのデータシートで照合すること。
> ESP32側のGPIO番号はファームウェアの `src/config.h` と一対一で対応しており、
> 変更する場合は `config.h` も合わせて修正する必要がある。

---

## 1. 部品確定の経緯

| 部品 | 検討過程 | 確定 |
|---|---|---|
| CANトランシーバ | ISO1050DWRは電源断後の再初期化遅延対策（VCC2ブリード抵抗）が必要。バス障害保護も±27/40Vと低い | **ISO1042DWV** |
| TVS（CAN） | PEC3824C2Aは最小発注3,000個。TSD12Cはスタンドオフ12VでISO1042のコモンモード±30Vに対し低すぎ | **RESD1CANY**（24V双方向・2ライン1パッケージ） |
| 絶縁DC/DC | MAU106は+5V/-5Vデュアルで用途違い。MAU102は絶縁1kVDCだが同じく非安定化 | **NME1S0505SC**（1kVDC機能絶縁・**要ダミー負荷**） |
| 降圧コンバータ | RT8250GSPはVin=5V・デューティ66%の両方が外部ブートストラップダイオード追加条件に該当 | **TPS562201DDCR**（内部補償・ダイオード不要） |
| インダクタ | データシートTable 7-2 より、3.3V出力時はMIN/TYPとも3.3µH（2.2µHは1.8V以下の値） | **DFE322520FD-3R3M=P2**（3.3µH / Isat 4.2A / DCR 65mΩ） |
| ヒューズ | 0.5A品＋直列ショットキーではVINが4.5Vを割る。1A品へ変更しショットキーを廃止 | **MF-FSML100/8-2**（0603 / 1A / 40mΩ / 耐圧8VDC） |
| USB-UART | FT231XSが入手難。CH340Gは12MHz水晶が必要 | **CH340E**（内蔵クロック・水晶不要。**DTR#なし→手動書き込み**） |
| ESD保護（USB） | 現地ではPC非接続だが、書き込み作業時の保護として追加 | **TPD2E2U06DCKR**（1.5pF / ±25kV接触） |
| RTC | DS1302は温度補償なし・独自3線式。DS3231MZは高価。DS1307は**VCC 4.5〜5.5Vの5V専用**で3.3V系では使用不可 | **MCP7940N-I/SN**（1.8〜5.5V・I2C 0x6F・SOIC-8・**外部水晶必要**） |
| CANコントローラ | — | **MCP2515T-I/SO**（SOIC-18） |
| CMC | Listen-Onlyでバスを駆動しないため放射ノイズ源にならない | **DNP**（0Ωジャンパで短絡。ジャンパは部品化済み） |

**絶縁の位置づけ**: 接続先は制御系CANで高電圧系ではないため、安全絶縁ではなく
**グランドループ遮断を目的とした機能絶縁**とする。NME1S0505SCはULから機能絶縁として
認定されており、入出力ともSELV限度（60VDC未満）内で使う前提の部品である。
**安全絶縁システムの要素として使ってはならない**ため、高電圧が乗り得るバスには接続しないことを
作業手順書と治具のラベルに明記する。

---

## 2. ブロック構成

```
                    ┌──── 機能絶縁境界（CH1）──────┐
CN1 (CAN1 500k) ────┤ RESD1CANY → [CMC:DNP / 0Ω]   │
  H / L            │        → ISO1042DWV          ├─── ESP32 内蔵TWAI (GPIO21/22)
                   │  NME1S0505SC + 100Ωダミー     │
                   │  VCC2_CH1 / GND2_CH1          │
                   └───────────────────────────────┘

                    ┌──── 機能絶縁境界（CH2）──────┐
CN2 (CAN2 250k) ────┤ RESD1CANY → [CMC:DNP / 0Ω]   │
  H / L            │        → ISO1042DWV          ├─── MCP2515 ── HSPI (13/14/35/4)
                   │  NME1S0505SC + 100Ωダミー     │    16MHz XTAL  INT(34) RESET(26)
                   │  VCC2_CH2 / GND2_CH2          │
                   └───────────────────────────────┘

USB-C ─ TPD2E2U06 ─ MF-FSML100 ─ 5V ─ TPS562201 ─ 3.3V ─ ESP32-WROOM-32E-N16
        (D+/D-)                                          ├── microSD (VSPI: 18/19/23/5)
                                                         ├── MCP7940N (I2C: 16/17) + 32.768kHz + CR2032
                                                         ├── 開始SW(32) / 停止SW(33)
                                                         ├── 状態LED(25)
                                                         ├── BOOTSW(IO0) / ENSW(EN)
                                                         └── CH340E ── UART0 (1/3)
```

**CH1とCH2の絶縁アイランドは完全に分離する。**
`VCC2_CH1` / `GND2_CH1` / `VCC2_CH2` / `GND2_CH2` の4ネットが独立していること。

> **ネット名について**: ISO1042のピン名では `GND1` がロジック側、`GND2` が絶縁側を指す。
> ネット名を `GND1` / `GND2` にすると「U2のGND2ピンがネットGND1に載る」という
> 取り違えを誘うため、**`GND2_CH1` / `GND2_CH2`** に改名している。

---

## 3. 部品表（BOM）

### 3.1 メイン

| Ref | 部品 | 型番 | 数量 | 備考 |
|---|---|---|---|---|
| U1 | MCUモジュール | ESP32-WROOM-32E-N16 | 1 | 16MB Flash / SRAM 520KB。PSRAMなし |
| U5 | CANコントローラ | MCP2515T-I/SO (SOIC-18) | 1 | CH2用。**3.3V単一電源** |
| Y1 | 水晶 | HUSG-16.000-20 相当（16MHz） | 1 | `mcp2515.h` の定数表が16MHz前提 |
| U7 | RTC | **MCP7940N-I/SN**（SOIC-8） | 1 | 1.8〜5.5V。I2Cアドレス**0x6F** |
| Y2 | RTC用水晶 | **32.768kHz / CL = 6〜7pF** | 1 | **CL指定に注意**（§10.2） |
| C27,C28 | 水晶負荷容量 | **水晶のCLに合わせる（6〜7pF目安）** | 2 | §10.2 |
| H1 | 電池ホルダ | CH28-2032LF | 1 | CR2032。RTCバックアップ |

### 3.2 CANインタフェース（1chあたり／全2ch分＝×2必要）

| Ref | 部品 | 型番 | 数量/ch | 備考 |
|---|---|---|---|---|
| U2,U4 | 絶縁CANトランシーバ | **ISO1042DWV** (SOIC-8) | 1 | VCC1=3.3V / VCC2=5V |
| PS1,PS2 | 絶縁DC/DC | **NME1S0505SC** | 1 | 5V→絶縁5V, 200mA, 1kVDC。**ch毎に個別** |
| R3,R4 | **ダミー負荷抵抗** | **100Ω 1/2W (1206)** | 1 | **必須。§6参照。省略するとISO1042が破損する** |
| D1,D2 | CANバス用TVS | **RESD1CANY** (SOT-23) | 1 | VRWM 24V / PPP 350W / 2ライン |
| FL2,FL3 | コモンモードチョーク | ACT45B-101-2P | 1 | **DNP**（§8参照） |
| RJ1〜RJ4 | **CMCバイパスジャンパ** | **0Ω (0603)** | 2 | **実装**。CMCの各巻線と並列（§8参照） |
| C2,C7 | VCC2バルク | 4.7µF (X7R, 16V) | 1 | VCC2直近 |
| C4,C8 | VCC2バイパス | 100nF (X7R) | 1 | VCC2直近 |
| R7,R13 | TXDプルアップ | 10kΩ | 1 | VCC1（3.3V）へ。§7参照 |
| — | VCC1バイパス | 100nF (X7R) | 1 | VCC1直近 |
| J2,J3 | CANコネクタ | B02B-XASK-A（2ピン） | 1 | 相手側都合により両ch同一。§9参照 |

> **出力容量の上限**: NME1S0505SCの推奨最大出力容量は**10µF**。
> 上記構成で約4.8µFなので範囲内だが、**これ以上増やさないこと**（起動時間が延びる）。

### 3.3 電源・USB

| Ref | 部品 | 型番 / 値 | 備考 |
|---|---|---|---|
| J1 | USBコネクタ | 5077CR-16SMC2-BK-TR（Type-C 16pin） | 電源兼書き込み |
| R1,R2 | CC抵抗 | **5.1kΩ ±5%** | CC1/CC2 → GND。**10kΩは規格外** |
| D5 | **USB ESD保護** | **TPD2E2U06DCKR** | 2ch / 1.5pF / ±25kV接触。**D+/D-、コネクタ直近** |
| F1 | ポリスイッチ | **MF-FSML100/8-2** | **0603** / 1A hold / 2A trip / 40mΩ / **耐圧8VDC** |
| U3 | 降圧コンバータ | **TPS562201DDCR** (SOT-23-6) | 5V→3.3V, 2A, 580kHz, D-CAP2 |
| L1 | インダクタ | **DFE322520FD-3R3M=P2** | 3.3µH / Isat 4.2A / Irms 2.3A / DCR 65mΩ |
| R5 | FB上側抵抗 | **33.2kΩ ±1% (E96)** | 3.3V設定。E24の33kΩで代用しないこと |
| R6 | FB下側抵抗 | **10.0kΩ ±1% (E96)** | |
| C12 | ブートストラップ | 100nF | **VBST–SW間。無いと動かない** |
| C1,C6 | 入力容量 | 10µF ×2（セラミック, 25V, X7R/X5R） | |
| C9 | 入力バイパス | 100nF | **VINピン直近に最優先で配置** |
| C13,C14 | 出力容量 | 22µF ×2（セラミック, **25V**, X7R/X5R） | 実効30µF。データシート指定20〜68µF |
| C10,C11 | 絶縁DC/DC入力容量 | 4.7µF（セラミック） | PS1/PS2の入力直近 |

**電圧降下の検証**（USB規格下限4.75V、負荷450mA時）

| 条件 | 降下 | VIN |
|---|---|---|
| 初期抵抗 40mΩ | 18 mV | 4.73 V |
| トリップ後（150mΩ想定） | 68 mV | 4.68 V |

IC最低入力4.5Vに対し十分な余裕がある。**直列ショットキーは廃止した**
（Vf 0.4Vを入れると4.5Vを割るため）。

> **耐圧8VDCはUSB 5V専用**という前提でのみ成立する。将来ACアダプタ（9V/12V）を
> 入れる変更をすると定格超過になるため、**回路図に「USB 5V専用」とコメントを残すこと**。
> TPS562201自体は17Vまで入るので、ヒューズが先に壊れる。

> **0603のトリップ時発熱**に注意。トリップ状態では約0.5Wを消費するため、
> 周囲に熱に弱い部品（電解・樹脂部品）を置かず、GNDベタで放熱できるレイアウトにする。

> **出力容量にアルミ電解を使わないこと。** リプル電流586mAp-pに対し、
> 一般的なSMDアルミ電解（ESR 1.5Ω）では**約880mVのリプル**が出る。
> セラミック（ESR 2.5mΩ）なら約6mV。容量値ではなくESRで決まる。

**消費電流の概算**（3.3V系）

| 負荷 | 電流 |
|---|---|
| ESP32（WiFi未使用、2コア稼働） | 約80〜120mA |
| MCP2515 + MCP7940N | 約10mA |
| microSD（書き込みピーク） | 約100mA |
| 絶縁DC/DC 2ch分の入力（ダミー負荷込み、効率72%） | 約230mA |
| **合計（ピーク）** | **約450mA** |

**給電方法**: 測定中はPCを接続しない運用のため、**USBモバイルバッテリーからの給電**を推奨。

### 3.4 ストレージ・操作系

| Ref | 部品 | 型番 / 値 | 備考 |
|---|---|---|---|
| J4 | microSDソケット | DM3AT-SF-PEJM5 | カード検出端子付き |
| R9,R10 | SD DAT1/DAT2 プルアップ | 10kΩ | 未使用DATラインをHighに固定 |
| R22 | SD CS プルアップ | 10kΩ | Rev.4で追加 |
| R23 | SD MISO プルアップ | 10kΩ | Rev.4で追加 |
| — | SDデカップリング | **10µF + 100nF** | **ソケット直近**。§5参照 |
| SW3,SW4 | 開始/停止ボタン | TVAF06-A020B-R | **パネル取付**。色/形を分ける |
| SW2 | BOOTボタン | TVAF06-A020B-R | 基板内でよい |
| SW1 | ENボタン | TVAF06-A020B-R | **手動書き込みに必須**（§10参照） |
| D4 | 状態LED | SML-E12P8WT86 | **パネルから視認できること** |
| D3 | 通信表示LED | SML-E12P8WT86 | CH340E TNOWピンで駆動 |
| R16 | MCP2515 /INT プルアップ | 10kΩ | **GPIO34は内部プルアップ無しのため必須** |
| R20 | MCP2515 /RESET プルアップ | 10kΩ | GPIO26からも駆動する |
| R17,R18,R19 | MCP2515 /TXnRTS プルアップ | 10kΩ | 送信は使わないが入力ピンなので固定 |
| R14,R15 | I2Cプルアップ | 4.7kΩ | SDA/SCL を3.3Vへ |

### 3.5 書き込み・デバッグ

| Ref | 部品 | 型番 | 備考 |
|---|---|---|---|
| U6 | USB-UART | **CH340E** (MSOP-10) | 内蔵クロック。**水晶不要** |
| C20 | V3コンデンサ | 100nF | **V3は3.3Vへ接続**（§10参照） |
| TP | テストポイント | — | 3.3V, 5V, GND, **VCC2_CH1/CH2**, 未使用GPIO |

---

## 4. R / C 定数表

回路図の value 欄にそのまま入力できる形にしている。

### 4.1 抵抗

| Ref | 接続 | 値 | 備考 |
|---|---|---|---|
| R1, R2 | USB-C CC2 / CC1 → GND | **5.1kΩ ±5%** | Rd。10kΩ不可 |
| R3, R4 | VCC2_CH1 / VCC2_CH2 ダミー負荷 | **100Ω 1/2W (1206)** | 必須。実測後68Ωへ変更の可能性 |
| R5 | 3.3V → VFB | **33.2kΩ ±1% E96** | |
| R6 | VFB → GND | **10.0kΩ ±1% E96** | |
| R7 | CH2_TXD プルアップ | 10kΩ | ISO1042(CH2) TXD |
| R8 | EN プルアップ | 10kΩ | C16と組でRC |
| R9, R10 | SD DAT2 / DAT1 プルアップ | 10kΩ | |
| R11 | IO0 (BOOT) プルアップ | 10kΩ | |
| R12 | CH340E TNOW → D3 | 1kΩ | 通信表示LED |
| R13 | CH1_TXD プルアップ | 10kΩ | ISO1042(CH1) TXD |
| R14, R15 | SCL / SDA プルアップ | 4.7kΩ | |
| R16 | MCP /INT プルアップ | 10kΩ | GPIO34は内部PU無し |
| R17, R18, R19 | MCP /TX0-2RTS プルアップ | 10kΩ | |
| R20 | MCP /RESET プルアップ | 10kΩ | GPIO26と併用 |
| R21 | IO25 → D4 | 1kΩ | 状態LED |
| R22 | SD_CS プルアップ | 10kΩ | |
| R23 | SD_MISO プルアップ | 10kΩ | |
| RJ1〜RJ4 | CMCバイパス | **0Ω (0603)** | 実装。CMC側はDNP |

### 4.2 コンデンサ

| Ref | 接続 | 値 | 備考 |
|---|---|---|---|
| C1, C6 | +5V 入力 | 10µF 25V X7R/X5R | TPS562201入力 |
| C9 | +5V | 100nF | **VINピン直近に最優先配置** |
| C10, C11 | +5V | 4.7µF | PS1/PS2 入力直近 |
| C2, C7 | VCC2 バルク (CH1/CH2) | 4.7µF X7R 16V | |
| C4, C8 | VCC2 バイパス (CH1/CH2) | 100nF | |
| C12 | VBST–SW | 100nF | **無いと降圧が動かない** |
| C13, C14 | 3.3V 出力 | 22µF 25V X7R/X5R | **アルミ電解不可** |
| C16 | EN | 1µF | R8と組でRC |
| C19 | BOOT | 100nF | |
| C20 | CH340E V3 | 100nF | V3は3.3Vへ接続済み |
| C22, C23 | 開始/停止ボタン | 100nF | |
| C24, C25 | 水晶負荷（MCP2515 16MHz） | 22pF C0G | 水晶のCL指定に合わせ最終調整 |
| C27, C28 | 水晶負荷（RTC 32.768kHz） | **6〜8pF C0G/NP0** | CL=6〜7pF水晶に対する値。**水晶のCLから逆算すること（§11.2）** |

### 4.3 3.3Vバイパスコンデンサの割当

**配置場所を確定させてから値を入れること。** 必要な員数は以下のとおり。

| 場所 | 必要な容量 | 優先度 |
|---|---|---|
| ESP32モジュール直近 | 10µF + 100nF | 高 |
| **microSDソケット直近** | **10µF + 100nF** | **高（§5参照）** |
| MCP2515 VDD | 100nF | 高 |
| MCP7940N VCC | 100nF | 中 |
| ISO1042 VCC1（CH1） | 100nF | 高 |
| ISO1042 VCC1（CH2） | 100nF | 高 |

**合計8個**（10µF×2 + 100nF×6）。
現行ネットリストの3.3Vバイパス群は7個のため、**1個不足の可能性**がある。
不足していれば**SDソケット用を最優先**で追加すること。

---

## 5. SDカードまわりの注意

### プルアップ

| 信号 | Ref | 目的 |
|---|---|---|
| DAT1 (pin8) | R9 | 未使用DATラインをHighに固定 |
| DAT2 (pin1) | R10 | 同上 |
| DAT3 / CS (pin2) | **R22** | GPIO5はストラッピングピン。カード未挿入時のフローティング防止 |
| DAT0 / MISO (pin7) | **R23** | カードがHi-Zの間のフローティング防止 |

### デカップリング

**ソケット直近に10µF + 100nF が必須。** SDカードは書き込み時に大きな電流スパイクを出し、
電圧が落ちるとカードがハングする。基板上で最も優先度の高いデカップリングのひとつ。

---

## 6. 絶縁電源とダミー負荷（最重要）

### 6.1 なぜダミー負荷が必要か

NME1S0505SCは**非安定化（unregulated）**タイプで、データシートに次の記載がある。

> データシート仕様を満たす最小負荷は定格負荷の10%。10%を下回ると出力電圧が上昇し、
> 負荷が5%未満に落ちると**典型的に規定出力電圧の2倍まで上昇し得る**。

この治具はListen-Onlyで**一切送信しない**ため、ISO1042のバス側電流は受信状態の
**約5〜10mA**しか流れない。200mA定格に対して**2.5〜5%負荷**であり、
出力が最も跳ね上がる領域に常時居続けることになる。

出力が10V付近まで上昇するとISO1042のVCC2絶対最大定格を超え、**トランシーバが破損する**。

### 6.2 抵抗値の選定

| 抵抗値 | 電流 | 負荷率 | 想定出力電圧 | ch当たり消費 | 判定 |
|---|---|---|---|---|---|
| なし | — | 2.5〜5% | 最大約10V | — | **破損** |
| 220Ω | 22.7mA | 約11% | 約5.5V | 0.12W | 上限ぎりぎり |
| **100Ω** | **50mA** | **約25%** | **約5.2V** | **0.27W** | **推奨** |
| 68Ω | 73.5mA | 約37% | 約5.1V | 0.40W | 上振れした場合の代替 |

**100Ω / 1/2W（1206）を各chのVCC2 - GND2間に実装する。**
トランシーバの約8mAと合わせて約29%負荷になり、ISO1042の推奨VCC2範囲（4.5〜5.5V）に収まる。

> **試作機で必ず実測すること。** 電源投入後、無通信状態で
> **VCC2_CH1 / VCC2_CH2 の電圧を測定**し、**4.5〜5.5Vに入っていることを確認**する。
> 上振れしていれば68Ωへ下げる。テストポイントを2ヶ所に出しておくこと。

### 6.3 絶縁境界の扱い

- NME1S0505SCの絶縁は**1kVDC（1秒）の機能絶縁**。安全絶縁ではない
- 入出力とも**SELV限度（60VDC未満）内**で使用する前提
- **`VCC2_CH1`/`GND2_CH1` と `VCC2_CH2`/`GND2_CH2` は絶対に接続しない**

---

## 7. ISO1042DWV の接続（各chに1個）

データシート照合済み（DWV: 1=VCC1, 2=TXD, 3=RXD, 4=GND1, 5=GND2, 6=CANL, 7=CANH, 8=VCC2）。

| ISO1042 信号 | 接続先 | 備考 |
|---|---|---|
| VCC1 | 3.3V（ロジック側） | 100nFを直近に |
| GND1 | ロジック側GND（ネット名 `GND`） | |
| TXD | CH1: ESP32 GPIO21 / CH2: MCP2515 TXCAN | **10kΩでVCC1へプルアップ** |
| RXD | CH1: ESP32 GPIO22 / CH2: MCP2515 RXCAN | |
| VCC2 | NME1S0505SC 出力（`VCC2_CH1` / `VCC2_CH2`） | 4.7µF + 100nF。**ダミー負荷100Ω併設** |
| GND2 | 絶縁側GND（`GND2_CH1` / `GND2_CH2`） | |
| CANH | CN 1番ピン | 経路上にTVS → CMC/ジャンパ |
| CANL | CN 2番ピン | 同上 |

**TXDプルアップが必要な理由**: ISO1042のTXDは内部で非常に弱くVCC1へプルアップされている
だけである。制御側がフロートするとバスに問題を起こす可能性があるため、外部プルアップで
レセッシブに固定する。**CH1はESP32起動前、CH2はMCP2515リセット中**にこの状態になる。

### 終端抵抗は実装しない

測定対象側で終端されているため、**治具側に120Ωを実装してはいけない**。

---

## 8. TVS と コモンモードチョーク

### 配置順

```
コネクタ → RESD1CANY → [CMC(DNP) ∥ 0Ωジャンパ] → ISO1042
```

**TVSは必ずコネクタ直後**に置く。TVSからGNDへの経路は最短・低インダクタンスにする。
TVSのGND端子は**そのchの絶縁側GND**（`GND2_CH1` / `GND2_CH2`）へ落とすこと。

### RESD1CANY

- VRWM 24V / PPP 350W / SOT-23 / 2ライン1パッケージ
- **1パッケージ2ラインなので個別TVS2個のときの容量ミスマッチが起きない**
- **発注前確認**: クランプ電圧VCが**ISO1042のバス障害保護±70V以内**に収まっていること

### CMC は DNP、0Ωジャンパで通す

Listen-Onlyでバスを駆動しないため放射ノイズ源にならず、通常は不要。
ただし**CMCを単に未実装にするとCANラインが断線する**ため、
各chに**0Ω抵抗2本（RJ1〜RJ4, 0603）をCMCの各巻線と並列に配置し、これを実装する**。
CMC（FL2/FL3）側はDNP指定。

将来CMCが必要になった場合は、0Ωジャンパを外してCMCを実装する。

> **ACT45Bの巻線ペアを必ず照合すること。** ネットリストは 4↔1 / 3↔2 が
> ストレートに導通する前提で配線している。KiCadシンボルの内部結線が 1↔2 / 3↔4 だと
> **CANH/CANLがクロスまたは短絡する**。0Ωジャンパも同じペアで置くこと。

---

## 9. CANコネクタと誤挿入対策

**相手側（測定対象側）のコネクタが両chとも B02B-XASK-A のため、治具側だけ変更できない。**
以下の運用対策で誤挿入を検出する。

| 対策 | 内容 |
|---|---|
| ケーブル識別 | ケーブルに色分け＋タグ（「CH1 500k」「CH2 250k」）を付ける |
| 基板シルク | CN1/CN2 の脇に `CH1 500kbps` / `CH2 250kbps` を印字 |
| **検出手順** | 統計ファイルで**両chとも `frames logged` が0でないこと**を確認する |

Listen-Onlyのためビットレートを間違えても**エラーが出ず0件で終わる**。
片方だけ0件なら挿し間違いか未接続と判断できるので、**この確認手順を省略しないこと**。

**CAN_GND端子が無い点**は残課題。GND2が完全に浮くためコモンモード電位の基準が
定まらないが、絶縁トランシーバなので差動としては動作する。
実機で通信が不安定な場合は、GND2に高抵抗（1MΩ程度）で基準を与えることを検討する。

**ハーネス製作時の照合**: J2/J3 の **1番ピン=CANH / 2番ピン=CANL** を前提に
TVS・CMC・トランシーバが配線されている。測定対象側ハーネスのピン割当と一致するか確認すること。

---

## 10. USB-UART（CH340E）と書き込み方法

### 手動書き込みになる

CH340Eは6番ピンがTNOWで、**DTR#を持たない**。ESP32の自動リセットにはDTR#とRTS#の
両方が必要なため、**手動書き込みとなる**。

この治具はファーム書き込み頻度が極めて低いため、自動リセット回路を省く判断は妥当。

**手順**: BOOTボタンを押しながらENボタンを押して離す → BOOTを離す → 書き込み

**基板シルクに手順を印字しておくこと。**

### 電源接続

| ピン | 接続 |
|---|---|
| VCC | **3.3V** |
| **V3** | **3.3V（VCCと同じネット）** ＋ 100nF |

CH340は3.3V駆動時にV3をVCCへ接続する。5V駆動にするとTXDが5Vで出てESP32が壊れる。
内蔵クロック生成器を持つため**外部水晶は不要**。

### ESD保護（TPD2E2U06DCKR）

D+/D- に2チャネルのESD保護を入れる。ライン容量1.5pFはUSB 2.0 Full Speed（12Mbps）に対し
十分に低く、信号品質への影響はない。

**配置が重要**: **USBコネクタのピンから5mm以内**、D+/D-上の他の部品より手前に置く。
離れた位置に置くと、サージがESD素子に到達する前に他の回路へ回り込むため効果が落ちる。

---

## 11. RTC（MCP7940N-I/SN）

### 11.1 役割

**記録開始時の実時刻を、BINヘッダの `unix_time` フィールド（+20、UTC）に書き込む。**

| できること | できないこと |
|---|---|
| 測定対象のイベントログとの時刻照合 | CANalyzerでの再生（相対タイムスタンプで動作するため無関係） |
| 目撃報告（「14時ごろ止まった」）との突合 | フレーム個々のタイムスタンプ精度の改善 |
| 複数ログ（LOG0001/0002…）の順序と間隔の把握 | フレーム間隔の測定精度（esp_timerが担当） |

必要精度は秒〜分オーダー。RTCは「t=0が実世界の何時何分か」というアンカーを与えるだけなので、
温度補償なし（外部水晶）のMCP7940Nで十分。

### 11.2 水晶と負荷容量（最も外しやすい点）

MCP7940Nのデータシート冒頭に、オシレータの仕様として次の記載がある。

> Oscillator for 32.768 kHz Crystals: **Optimized for 6-9 pF crystals**

**CL = 6〜9pF の水晶を使うこと。** MCP7940系のオシレータは低消費設計でドライブ能力が
小さく、高CL品では発振余裕が減る。推奨水晶リストには10pF/12pF品も載っているが、
上記のヘッドライン仕様を優先する。

負荷容量はデータシートの式から逆算する。

```
CL = (CX1 × CX2)/(CX1 + CX2) + Cstray
     ※ CX1 = 外付け容量 + COSC(3pF)、CX1 = CX2 とする
     CX1 = CX2 なら CL = CX/2 + Cstray
```

**外付け容量から実効CLを逆引きした表**（COSC = 3pF）

| 外付け | Cstray=2pF | Cstray=3pF | Cstray=5pF |
|---|---|---|---|
| **6pF** | 6.5 | **7.5** | 9.5 |
| **7pF** | 7.0 | **8.0** | 10.0 |
| **8pF** | 7.5 | **8.5** | 10.5 |
| 15pF | 11.0 | 12.0 | 14.0 |
| 18pF | 12.5 | 13.5 | 15.5 |

**CL = 6〜7pF の水晶に対して外付け 6〜8pF** が正しい組み合わせ。
C0G/NP0を使うこと（X7Rでは温度で容量が変わり周波数がずれる）。

#### 試作1号機（FC-135 / CL=12.5pF + 外付け7pF）の評価

**発振は正常にしている**（`SETTIME` → `OSCRUN=1` を実機で確認済み）。
実効CLは約8pFで、これはMCP7940Nの最適範囲6〜9pFに収まっているため、
発振余裕の面では問題ない。

問題は**周波数精度**。水晶の仕様CL(12.5pF)より実効CL(8pF)が小さいため、
発振周波数が高くなり**時計が進む**。

| C1 | C0 | 誤差 | 秒/日 | 分/年 |
|---|---|---|---|---|
| 1.6 fF | 1.35 pF | +27.8 ppm | +2.4 s | +14.6 分 |
| 1.8 fF | 1.35 pF | +31.3 ppm | +2.7 s | +16.4 分 |
| 2.2 fF | 1.35 pF | +38.2 ppm | +3.3 s | +20.1 分 |

**負荷容量を15〜18pFへ増やしてはいけない。** 実効CLを12.5pFに合わせられるが、
発振余裕を削る方向であり、MCP7940Nの最適範囲(6〜9pF)からも外れる。

**対処は2つ。**

| 方法 | 内容 |
|---|---|
| **A. デジタルトリミングで補正**（1号機向け） | ハード改修不要。§11.6参照。±129ppmの補正範囲があり、+30ppm程度は余裕で吸収できる |
| **B. 次版でCL=6〜7pF品へ変更**（推奨） | 外付けは6〜8pFのまま。精度と発振余裕の両方が正しくなる |

#### 発振しない場合の切り分け順序

MCP7940Nは**工場出荷時 ST=0 で発振していない**のが正常。
`SETTIME` を打つまでは `OSCRUN=0` のままなので、これを故障と誤認しないこと。

1. `SETTIME` を実行する
2. `[OK]` が返れば発振している（完了）
3. `oscillator did not start within 5 s.` が出た場合のみ、以下を疑う
   - 水晶のCL指定と負荷容量の不整合
   - **水晶周辺のフラックス残渣**（32kHz水晶は残渣だけで発振が止まる）
   - 水晶の実装不良

データシートにレイアウト推奨図（Figure 5-3）があるので、それに従うこと。

- 水晶は**IC直近**、配線最短
- 周囲をガードGNDで囲む
- TPS562201のインダクタやCANラインから離す

発振が立ち上がらない場合、ファームウェアが起動時に
`[WARN] MCP7940N: oscillator not running. check crystal / load caps.` を出す。

### 11.3 接続

| MCP7940N 信号 | 接続先 | 備考 |
|---|---|---|
| VCC | 3.3V | 100nFを直近に |
| VSS | GND | |
| SDA / SCL | ESP32 GPIO16 / GPIO17 | 4.7kΩでプルアップ（R14/R15） |
| X1 / X2 | 32.768kHz水晶 + 負荷容量×2 | §11.2 |
| VBAT | CR2032（+） | 直列ダイオード・抵抗を入れないこと |
| MFP | 未接続 | 使う場合はオープンドレインなので10kΩプルアップが必要 |

I2Cアドレスは **0x6F**（DS3231の0x68とは別）。

### 11.4 ファームウェア側で必須の初期化

MCP7940Nは**電源を入れただけでは時計が動かない**。以下は `src/mcp7940.h` で実装済み。

| 項目 | レジスタ | 内容 |
|---|---|---|
| 発振器の起動 | RTCSEC bit7 = **ST** | 1を書かないと発振しない |
| バックアップ有効化 | RTCWKDAY bit3 = **VBATEN** | **デフォルト無効**。忘れると電源断で時刻が消える |
| 発振確認 | RTCWKDAY bit5 = OSCRUN | 実際に回っているかの確認に使う |
| 電源断履歴 | RTCWKDAY bit4 = PWRFAIL | 起動時ログに表示する |

### 11.5 時刻の設定

RTCには**現地時刻（日本時間）**を設定する。ファームウェアがUTCへ変換して
`unix_time` に格納するため、PC側で正しい時刻が表示される。

```
pio device monitor
> SETTIME 2026-08-09 14:05:00
[OK] RTC set to 2026-08-09 14:05:00 (local)
```

**製作時に一度設定すれば、CR2032が切れるまで保持される。**
RTCが無い／時刻未設定の場合は `unix_time = 0` となり、記録自体は続行される。

### 11.6 デジタルトリミング（周波数誤差の補正）

MCP7940Nは水晶の周波数誤差をソフトで補正できる。

| 項目 | 値 |
|---|---|
| 補正範囲 | **±129 ppm** |
| 分解能 | **1.017 ppm / step**（TRIMVAL 1あたり） |
| 動作 | CRSTRIM=0 のとき1分ごとに 2×TRIMVAL クロックを加減算 |
| バックアップ動作中 | **補正が効く** |

レジスタは OSCTRIM（0x08）。bit7 = SIGN、bit6:0 = TRIMVAL。

#### 校正手順

1. `SETTIME` で正確な時刻に合わせる（電波時計やPCの時刻を基準にする）
2. **1日以上放置**する（長いほど精度が上がる）
3. `GETTIME` で基準時刻とのずれを測る
4. ppm を計算する： `ppm = 進んだ秒数 ÷ 経過秒数 × 1e6`
5. `TRIM` コマンドで補正値を書く： `step = -ppm ÷ 1.017`
   **時計が進んでいるなら負の値**

```
> TRIM -34          ← 1日3秒進む場合（34.7ppm）
[OK] trim = -34 (-34.6 ppm)
> STATUS
rtc flags: OSCRUN=1 PWRFAIL=0 VBATEN=1 (RTCWKDAY=0x29)  trim=-34 (-34.6 ppm)
```

引数なしで `TRIM` を打つと現在値と使い方が表示される。

> **符号の向きは実測で必ず確認すること。** 補正後にもう一度1日放置して、
> ずれが減っているかを確認する。逆方向に増えていたら符号を反転させる。

補正値はVBAT保持されるので、製作時に一度校正すれば以後は不要。
**個体ごとに水晶の誤差が異なるため、量産時は1台ずつ校正する必要がある。**

---

## 12. MCP2515 の接続

データシート照合済み（SOIC-18: TXCAN=1, RXCAN=2, OSC2=7, OSC1=8, VSS=9, /INT=12,
SCK=13, SI=14, SO=15, /CS=16, /RESET=17, VDD=18）。

| MCP2515 信号 | 接続先 | 備考 |
|---|---|---|
| VDD | **3.3V** | 100nFを直近。5Vではない |
| OSC1 / OSC2 | 16MHz水晶 + 22pF×2 | **IC直近**。配線最短 |
| SCK / SI / SO | ESP32 GPIO14 / 13 / **35** | SOをGPIO12にしてはいけない |
| /CS | ESP32 GPIO4 | |
| /INT | ESP32 GPIO34 | 10kΩで3.3Vへ |
| /RESET | ESP32 GPIO26 ＋ 10kΩで3.3Vへ | FWからハードウェアリセットを行う |
| TXCAN / RXCAN | CH2 ISO1042 TXD / RXD | |
| /TX0RTS, /TX1RTS, /TX2RTS | 10kΩで3.3Vへ | 送信は使わないが入力ピンなので固定 |
| /RX0BF, /RX1BF, CLKOUT/SOF | 未接続 | |

### ビットタイミング（サンプルポイント）

3レート共通で **16TQ・サンプルポイント87.5%**（CiA推奨）に揃えている。

| ビットレート | CNF1 | CNF2 | CNF3 | 構成 | SP |
|---|---|---|---|---|---|
| 500 kbps | 0x00 | 0xB5 | 0x81 | Sync1 + Prop6 + PS1 7 + PS2 2 = 16TQ | 87.5% |
| 250 kbps | 0x01 | 0xB5 | 0x81 | 同上（TQ=250ns） | 87.5% |
| 125 kbps | 0x03 | 0xB5 | 0x81 | 同上（TQ=500ns） | 87.5% |

autowp系ライブラリの一般的な定数表（500k = 0x00/0xF0/0x86 など）は
サンプルポイントが 9/16 = **56.25%** と低く、バスの立ち上がりリンギングに弱い。

250kbpsは SJW を 2TQ ではなく **1TQ**（CNF1 = 0x01）にしている。
PS2 = 2TQ に対して SJW = 2TQ だと `PhaseSeg2 > SJW` を満たさないため。

---

## 13. ESP32 ピンアサイン

`src/config.h` と一対一で対応（Fable査読で全ピン一致を確認済み）。

### 12.1 使用ピン

| GPIO | 方向 | 接続先 | config.h のマクロ |
|---|---|---|---|
| 21 | 出力 | CH1 ISO1042 TXD | `CAN1_TX_GPIO` |
| 22 | 入力 | CH1 ISO1042 RXD | `CAN1_RX_GPIO` |
| 14 | 出力 | MCP2515 SCK | `MCP_SCK_GPIO` |
| 13 | 出力 | MCP2515 SI | `MCP_MOSI_GPIO` |
| 35 | 入力 | MCP2515 SO | `MCP_MISO_GPIO` |
| 4 | 出力 | MCP2515 /CS | `MCP_CS_GPIO` |
| 34 | 入力 | MCP2515 /INT | `MCP_INT_GPIO` |
| 26 | 出力 | MCP2515 /RESET | `MCP_RESET_GPIO` |
| 18 | 出力 | microSD CLK | `SD_SCK_GPIO` |
| 19 | 入力 | microSD DAT0 | `SD_MISO_GPIO` |
| 23 | 出力 | microSD CMD | `SD_MOSI_GPIO` |
| 5 | 出力 | microSD DAT3 (CS) | `SD_CS_GPIO` |
| 16 | 双方向 | MCP7940N SDA | `RTC_SDA_GPIO` |
| 17 | 出力 | MCP7940N SCL | `RTC_SCL_GPIO` |
| 32 | 入力 | 開始ボタン → GND | `BTN_START_GPIO` |
| 33 | 入力 | 停止ボタン → GND | `BTN_STOP_GPIO` |
| 25 | 出力 | 状態LED（+1kΩ） | `LED_GPIO` |
| 1 / 3 | — | CH340E RXI / TXO | — |
| 0 | 入力 | BOOTボタン → GND | — |
| EN | 入力 | ENボタン + 10kΩ + 1µF | — |

### 12.2 未使用ピン（テストポイントのみ配置）

ESP32モジュールは端子に直付けできるため、モジュール側にはテストポイントを設けない。
基板上の他ICの未使用ピンには、ジャンパ線で引き出せるようテストポイントを置く。

| ピン | 状態 | 将来の用途 |
|---|---|---|
| ESP32 IO27 | 未接続 | MCP7940N MFP（アラーム/クロック出力） |
| ESP32 IO39 | 未接続 | microSD カード検出 |
| ESP32 IO2 / 12 / 15 | **未接続のまま** | 起動ストラップピン。使用しない |
| MCP7940N MFP | 未接続 | 使う場合はオープンドレインなので10kΩプルアップが必要 |
| MCP2515 /RX0BF, /RX1BF, CLKOUT | 未接続 | |
| CH340E RTS#, CTS# | 未接続 | |

**GPIO6〜11は内蔵フラッシュ接続。絶対に使用不可。**
**GPIO12は起動時にHighだと1.8Vフラッシュと誤認して起動しない**ため、
MCP2515のSOはGPIO35に割り当てている。

---

## 14. 査読履歴

### 13.1 第1回（2026-08-09 / Opus 5）

| # | 指摘 | 状況 |
|---|---|---|
| 重大1 | CH1/CH2の絶縁2次側が短絡 | **対応済**（`+5V_CH2` を追加） |
| 重大2 | CH340E の V3 が未接続 | **対応済**（3.3Vへ接続） |
| 重要3 | J2/J3 が同一コネクタ | **対応せず**（相手側都合により変更不可。§9の運用対策で補う） |
| 重要4 | ヒューズ品番の不一致 | **対応済**（MF-FSML100/8-2 で確定） |
| 重要5 | SD の CS/MISO プルアップ | **対応済**（R22/R23 追加） |
| 注意6 | R/C の定数未設定 | **対応済**（§4に定数表を追加） |

### 13.2 第2回（2026-08-09 / Fable）

| # | 指摘 | 状況 |
|---|---|---|
| 2.1 | ヒューズが文書とネットリストで不一致 | **対応済**（MF-FSML100/8-2 に統一。0603・耐圧8Vへ文書修正） |
| 2.2 | CMC DNP時にCANラインが断線 | **対応済**（0Ωジャンパ RJ1〜RJ4 を部品化） |
| 2.3 | ACT45B の巻線ペア要照合 | **確認済**（発注前チェックリストに残置） |
| 2.4 | NME1S0505SC のパッド番号要照合 | **確認済**（同上） |
| 2.5 | ネット名 GND1/GND2 の改名推奨 | **対応済**（`GND2_CH1` / `GND2_CH2`） |
| 2.6 | 3.3Vバイパスの員数不足の可能性 | **要確認**（§4.3の割当表で確定させる） |
| 2.7-1 | C10/C11 がBOM未記載 | **対応済**（絶縁DC/DC入力 4.7µF として記載） |
| 2.7-2 | フィードフォワード用フットプリント不在 | **方針変更**（設けない。BOMから削除） |
| 2.7-3 | J2/J3 の1番ピン=CANH の照合 | ハーネス製作時に確認（§9） |
| 2.7-4 | USB D+/D- のESD保護 | **対応済**（TPD2E2U06DCKR 追加） |
| 2.7-5 | RTC 割込みピンの予備配線 | **テストポイントで対応** |

**ピン配置はデータシート照合済み**: ISO1042DWV / MCP2515T-I/SO /
CH340E / TPS562201DDCR / ESP32-WROOM-32E（`config.h` と全ピン一致）/ RESD1CANY。
RTCはRev.5でMCP7940N-I/SNへ変更したため、フットプリントの再照合が必要（§11）。

---

## 15. 発注前チェックリスト

**致命的（これを外すと動かない／壊れる）**

- [ ] 絶縁2次側4ネット（`VCC2_CH1`/`GND2_CH1`/`VCC2_CH2`/`GND2_CH2`）が完全に独立
- [ ] 各chのVCC2 - GND2間に**100Ωダミー負荷**がある（無いとISO1042が破損）
- [ ] CH340E の V3 が 3.3V に接続されている
- [ ] **CMCバイパスの0Ωジャンパ（RJ1〜RJ4）が実装指定になっている**（DNPだと断線）
- [ ] 120Ω終端抵抗が実装されていない
- [ ] MCP2515のVDDが3.3V、SOがGPIO35（GPIO12ではない）
- [ ] GPIO34の/INTに外部10kΩプルアップがある
- [ ] GPIO2 / 12 / 15 に何も接続されていない
- [ ] **MCP7940N-I/SN（SOIC-8）のフットプリント**。DS3231MZとはピン配置が異なる
- [ ] **RTC用水晶のCL指定と負荷容量が整合**している（§10.2）
- [ ] C12（ブートストラップ 100nF）が VBST–SW 間にある

**シンボル照合（誤ると信号クロス／電源極性反転）**

- [ ] **ACT45B の巻線ペア**をデータシート図と照合済み（0Ωジャンパも同じペア）
- [ ] **NME1S0505SC のパッド番号**をデータシート実装図と照合済み

**重要**

- [ ] 絶縁境界の下を銅箔が横断していない（全層確認）
- [ ] NME1S0505SCがch毎に2個ある。VCC2の出力容量が10µF以下
- [ ] ISO1042のTXDにVCC1へのプルアップがある
- [ ] RESD1CANYがコネクタとトランシーバの間にあり、GNDが各chの絶縁側GNDに落ちている
- [ ] RESD1CANYのクランプ電圧が±70V以内であることをデータシートで確認済み
- [ ] **TPD2E2U06がUSBコネクタのピンから5mm以内**にある
- [ ] ヒューズが MF-FSML100/8-2（0603）で、回路図に「USB 5V専用（耐圧8VDC）」のコメントがある
- [ ] ヒューズ周囲に熱に弱い部品が無い（トリップ時 約0.5W）
- [ ] 直列ショットキーを入れていない
- [ ] USB-C の CC抵抗が 5.1kΩ
- [ ] FB分圧が 33.2kΩ / 10.0kΩ（E96 1%）
- [ ] 出力コンデンサがセラミック 22µF×2 / 25V（アルミ電解ではない）
- [ ] **3.3Vバイパスの割当表（§4.3）を作り、SDソケット直近の10µF+100nFが確保されている**
- [ ] 水晶が16MHz。I2Cに4.7kΩプルアップ
- [ ] SD の CS / MISO に10kΩプルアップがある
- [ ] ENボタンがある（手動書き込みに必須）

**シルク・文書**

- [ ] CN1/CN2 の脇に `CH1 500kbps` / `CH2 250kbps`
- [ ] 書き込み手順（BOOT押しながらEN）
- [ ] 「制御系CAN専用。高電圧バスに接続しないこと」
- [ ] ハーネス製作図で J2/J3 の 1番=CANH / 2番=CANL が測定対象側と一致

---

## 16. 基板レイアウトの注意

### 15.1 絶縁境界

- ISO1042とNME1S0505SCの下を**銅箔・ベタGNDが横断しないこと**。内層を含め全層で切る
- **CH1とCH2の絶縁側は独立した2つの島**にする
- 機能絶縁なので安全規格上の沿面距離要求は無いが、
  **パッケージのピン間距離より狭いパターンは引かない**

### 15.2 その他

- **TVSはコネクタ直後**。GNDへの経路を最短に
- **TPD2E2U06はUSBコネクタから5mm以内**。D+/D-上の他の部品より手前
- **水晶はMCP2515の直近**。ガードパターンで囲み、TPS562201のインダクタから離す
- **RTC用32.768kHz水晶もMCP7940Nの直近**。同様にガードGNDで囲む（§11.2）
- **SDソケット直近に10µF + 100nF**
- **MCP2515のHSPIとSDのVSPIは物理的に分離**した配線にする
- **VCC2のバイパスコンデンサはトップ層**に置き、ビアを使わずVCC2/GND2ピンへ接続する
- TPS562201のスイッチングノード（SW）は面積を最小に
- **ヒューズ（0603）周囲は放熱を考慮**。トリップ時に約0.5W消費する
- ESP32-WROOM-32Eのアンテナ部は基板端に出しベタを抜く
- **状態LEDと2つの操作ボタンは筐体外から操作/視認できる位置**に配置

---

## 17. 試作機での確認項目

| # | 項目 | 判定基準 |
|---|---|---|
| 1 | **VCC2_CH1 / VCC2_CH2 の実測**（無通信時） | **4.5〜5.5V**。外れていればダミー負荷を68Ωへ |
| 2 | **VINの実測**（SD書き込み時の落ち込み含む） | **4.5V以上** |
| 3 | 3.3V電圧とリプル | 3.2〜3.4V / リプル33mV以下 |
| 4 | **絶縁確認** | `GND2_CH1` と `GND2_CH2` が導通していない |
| 5 | ESP32が起動する | シリアルに起動メッセージが出る |
| 6 | 手動書き込みができる | BOOT+ENでダウンロードモードに入る |
| 7 | MCP2515疎通 | 起動時に `MCP2515 (CH2): detected` |
| 8 | SD認識 | 起動時に容量が表示される |
| 9 | **RTC発振** | 起動時に `oscillator not running` の警告が出ない |
| 10 | RTC時刻保持 | `SETTIME` → 電源断 → `GETTIME` で時刻が続いている |
| 11 | CANラインの導通 | コネクタ〜トランシーバ間（0Ωジャンパ経由）が導通 |
| 12 | 実バスでの受信 | CH1/CH2とも `frames logged` が0でない |
| 13 | 取りこぼし | `ring dropped` / `ctrl missed` / `ctrl ovf events` が0 |
| 14 | サンプルポイントの妥当性 | エラーカウンタが増えない（CH2=87.5% / CH1=80%） |
| 15 | 異常系 | 記録中のSD抜去→統計ファイルが残る。開始ボタンで復帰できる |

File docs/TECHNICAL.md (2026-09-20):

# CANログ取得治具 技術解説

このファームウェアが「なぜこう作られているか」を、前提知識なしで読めるように解説する。
コードを読む前に一度目を通しておくと、各ファイルの役割と設計判断の理由が分かる。

**目次**

1. [そもそも何をする装置か](#1-そもそも何をする装置か)
2. [CANバスの基礎](#2-canバスの基礎)
3. [全体アーキテクチャ](#3-全体アーキテクチャ)
4. [ESP32の2つのCPUコアとタスク](#4-esp32の2つのcpuコアとタスク)
5. [リングバッファ](#5-リングバッファ)
6. [レコード形式とファイル形式](#6-レコード形式とファイル形式)
7. [タイムスタンプ](#7-タイムスタンプ)
8. [2チャネルのマージ](#8-2チャネルのマージ)
9. [状態機械](#9-状態機械)
10. [割込みとISR](#10-割込みとisr)
11. [MCP2515ドライバ](#11-mcp2515ドライバ)
12. [RTCドライバ](#12-rtcドライバ)
13. [SDカードへの書き込み](#13-sdカードへの書き込み)
14. [PC側の変換ツール](#14-pc側の変換ツール)
15. [ログの自動アップロード](#15-ログの自動アップロード)
16. [開発中に踏んだバグと教訓](#16-開発中に踏んだバグと教訓)
17. [用語集](#17-用語集)

---

## 1. そもそも何をする装置か

### 解決したい問題

CANログを取るには通常、PCとCANインタフェース（Vector社のVNシリーズなど）が要る。
だが現場では、PCを持ち込めない・機材の台数やライセンスが足りない・
測定対象のそばにPCを置けない、といった制約がある。

そこで**PCなしで単独動作し、SDカードへ記録するだけの装置**を作る。

### この治具がやること

```
測定対象のCANバス  →  治具がSDカードへ記録  →  PCでBLF形式に変換  →  CANalyzerで解析
```

治具は**通信内容をそのまま丸ごと記録するだけ**で、中身の意味は解釈しない。
意味の解釈（「このビットは何のフラグか」など）はCANalyzerとDBCファイルが行う。

だから治具はDBCを持たないし、信号が何本あろうと動作は変わらない。

### なぜ「BLF」に変換するのか

BLF（Binary Logging Format）はVector社のログ形式で、CANalyzerがそのまま読み込んで
**再生（リプレイ）**できる。既存の解析環境をそのまま使えるようにするための選択。

---

## 2. CANバスの基礎

### CANとは

自動車や産業機器で使われる通信規格。**2本の線（CAN-H / CAN-L）**の電圧差で
0と1を表現する（差動信号）。ノイズに強いのが特徴。

### フレーム（1回の通信の単位）

CANでは1回の通信を**フレーム**と呼ぶ。中身はこうなっている。

| 要素 | 内容 | この治具での扱い |
|---|---|---|
| **ID** | 送信内容の識別番号。11bitか29bit | `CanRec.id` に保存 |
| **DLC** | データの長さ（0〜8バイト） | `CanRec.dlc` に保存 |
| **データ** | 最大8バイトの中身 | `CanRec.data[8]` に保存 |
| RTR | リモートフレーム（データ要求）かどうか | `CanRec.flags` のbit1 |
| CRC | 誤り検出符号 | コントローラが検証。記録しない |
| ACK | 受信確認 | **この治具は返さない**（後述） |

**IDには宛先の概念がない。** 全ノードが全フレームを受信し、IDを見て
「自分に関係あるか」を判断する。だから治具のような傍受装置が成立する。

### ビットレート

1秒間に何ビット送れるか。この治具では2種類を扱う。

| チャネル | ビットレート | 1フレームの所要時間（8バイト時） |
|---|---|---|
| CH1 | 500 kbps | 約 222〜260 µs |
| CH2 | 250 kbps | 約 444〜520 µs |

**ビットレートが合っていないと、1フレームも読めない。** 波形の切り出し位置がずれるため、
全部が「壊れたフレーム」として捨てられる。開発中、CH2（250k）に500k設定で繋いで
0件になった事例がこれ。

### Listen-Only（傍受専用）モード

通常のCANノードは、フレームを正しく受信すると**ACKビットを返す**（電気的にバスを引っ張る）。
つまり「聞くだけ」のつもりでも、実はバスに手を出している。

**Listen-OnlyモードではこのACKも返さない。** バスに対して完全に受動的になる。

| | 通常モード | Listen-Only |
|---|---|---|
| 受信 | できる | できる |
| ACK送信 | **する** | **しない** |
| バスへの影響 | あり | **なし** |
| ビットレート誤設定時 | エラーフレームを出して**バスを妨害する** | 静かに0件で終わる |

稼働中の機器に繋ぐ治具なので、**バスに一切影響を与えない**ことが絶対条件。
CH1（ESP32内蔵TWAI）は `TWAI_MODE_LISTEN_ONLY`、CH2（MCP2515）は
`CANCTRL` レジスタに `0x60` を書いてListen-Onlyにしている。

その代償として、**設定を間違えても警告が出ない**。だから統計ファイルで
「受信0件」を検出する仕組みを入れている。

### 終端抵抗

CANバスは両端に120Ωの抵抗を付けるのが決まり。信号の反射を防ぐため。
**既に終端されているバスに3個目を足すと波形が崩れる**ので、この治具には実装しない。

---

## 3. 全体アーキテクチャ

### ハードウェアの流れ

```
測定対象 CAN1(500k) ─ TVS ─ 絶縁トランシーバ ─ ESP32内蔵TWAI ┐
                                                          ├→ ESP32 ─ SDカード
測定対象 CAN2(250k) ─ TVS ─ 絶縁トランシーバ ─ MCP2515(SPI) ─┘
```

**なぜCH2だけ外付けICなのか。** ESP32(classic)の内蔵CANコントローラ（TWAI）は
**1チャネルしかない**。2バス同時記録には外付けが必須で、MCP2515を追加した。

負荷の高い500kbpsを内蔵TWAI、250kbpsをMCP2515に割り当てている。
MCP2515は受信バッファが2段しかなく、高速なバスでは取りこぼしやすいため。

### ソフトウェアの流れ

```
[CAN CH1] → rxTaskTwai ─┐
                        ├→ リングバッファ ─→ writerTask ─→ SDカード
[CAN CH2] → rxTaskMcp  ─┘   (RAM上)          (別コア)
```

**3つの独立した処理**が並行して動く。これが設計の中核。

| タスク | 動作コア | 優先度 | 仕事 |
|---|---|---|---|
| `rxTaskTwai` | Core 1 | 20 | CH1の受信と打刻だけ |
| `rxTaskMcp` | Core 1 | 19 | CH2の受信と打刻だけ |
| `writerTask` | Core 0 | 5 | ファイル形式への変換とSD書き込み |
| `loop()` | Core 1 | 1 | ボタン、LED、シリアルコマンド |

### なぜ受信と書き込みを分けるのか

**SDカードは、書き込みが突然数百ミリ秒止まることがある。**
内部でウェアレベリング（書き込み位置の平準化）やガベージコレクションが走るため。

もし「受信したら即SDへ書く」という作りにすると、その数百ミリ秒の間に届いた
フレームが全部失われる。CH1が最大4,000フレーム/秒なので、300ms止まれば1,200件の欠落。

そこで、

1. 受信タスクは**RAM上のリングバッファに置くだけ**（数マイクロ秒で終わる）
2. 書き込みタスクが**別のコアで**バッファから取り出してSDへ書く

という分業にしている。SDが止まっている間もバッファに溜まり続けるので、
**バッファが溢れない限り1件も落ちない**。

実測では、リングバッファ1024段のうち最大12段しか使っていない（余裕率85倍）。

---

## 4. ESP32の2つのCPUコアとタスク

### マルチタスクとは

普通のArduinoプログラムは `setup()` と `loop()` しかなく、処理は1つずつ順番に実行される。
これだと「SDに書いている間はCANを受信できない」という問題が起きる。

ESP32は**FreeRTOS**というリアルタイムOSが動いていて、
**複数の処理を並行して走らせられる**。この単位を**タスク**と呼ぶ。

### タスクの作り方

```cpp
xTaskCreatePinnedToCore(
    rxTaskTwai,        // 実行する関数
    "rxTwai",          // 名前（デバッグ用）
    4096,              // スタックサイズ（バイト）
    nullptr,           // 引数
    20,                // 優先度（大きいほど優先）
    nullptr,           // タスクハンドル
    1                  // 動かすCPUコア番号
);
```

### 優先度とコアの割り当ての意味

ESP32には**Core 0** と **Core 1** の2つのCPUがある。

```
Core 1（受信担当）              Core 0（書き込み担当）
├ rxTaskTwai  優先度20          └ writerTask  優先度5
├ rxTaskMcp   優先度19
└ loop()      優先度1
```

**受信と書き込みを別コアに分けている**ので、SD書き込みが重くても受信は止まらない。

同じコア内では**優先度が高いタスクが優先される**。CH1（500kbps、より高速）を
CH2より高い優先度にしているのは、取りこぼしにくくするため。

### 「必ず眠る」ことの重要性

優先度の高いタスクがCPUを離さないと、**低い優先度のタスクが一切動けなくなる**。
これを**飢餓（starvation）**と呼ぶ。

タスクは以下のいずれかで「眠って」CPUを他に譲る必要がある。

| 関数 | 意味 |
|---|---|
| `vTaskDelay(n)` | n ティック（1ティック=1ms）眠る |
| `twai_receive(&msg, timeout)` | フレームが来るか、タイムアウトするまで眠る |
| `ulTaskNotifyTake(clear, timeout)` | 通知が来るか、タイムアウトするまで眠る |

**開発中、この「必ず眠る」を1箇所外してしまい、装置全体が無反応になるバグを出した**
（§16参照）。ループの中に必ずブロックする呼び出しがあるかは、毎回確認すべき点。

---

## 5. リングバッファ

### 何のためにあるか

受信タスクと書き込みタスクの間でデータを受け渡す**待ち行列**。
「受信の速さ」と「書き込みの速さ」の差を吸収する。

### 仕組み

固定長の配列を輪っかのように使う。

```
配列: [ ][ ][A][B][C][ ][ ][ ]
             ↑        ↑
            tail     head
          (読む位置)  (書く位置)
```

- **head**（書き込み位置）を進める＝データを入れる
- **tail**（読み出し位置）を進める＝データを取り出す
- 末尾まで行ったら先頭に戻る（＝リング）
- `head == tail` なら空、`head+1 == tail` なら満杯

配列サイズを2のべき乗にしておくと、位置の更新が
`(h + 1) & (N - 1)` という高速な演算だけで済む（割り算が不要）。

### SPSC（単一生産者・単一消費者）

このリングバッファには重要な制約がある。

- **head を書き換えるのは生産者（受信タスク）だけ**
- **tail を書き換えるのは消費者（書き込みタスク）だけ**

この約束を守ると、**ロック（排他制御）が不要**になる。
お互いが別の変数しか触らないので、衝突しようがないため。

ロックを使うと、ロック待ちで受信タスクが止まる可能性が出る。それを避けている。

だからCH1とCH2で**別々のリングバッファ**を持っている（生産者が1つずつになるように）。

### メモリバリア

ESP32は2つのコアがあるため、片方のコアで書いた内容がもう片方から
**すぐには見えない**ことがある（CPUが最適化のために書き込み順序を入れ替える）。

```cpp
buf_[h] = rec;          // ①データを書く
__sync_synchronize();   // ②メモリバリア
head_ = next;           // ③headを進める
```

もし①と③の順序が逆になると、消費者が「データが入った」と判断したのに
中身がまだ古い、という事故が起きる。`__sync_synchronize()` は
**「ここより前の書き込みを、ここより後の書き込みより先に完了させろ」**という指示。

### 満杯になったら

```cpp
if (next == tail_) {
    dropped_++;      // 捨てた数を数える
    return false;
}
```

**古いデータを上書きせず、新しいデータを捨てる。** そして捨てた件数を数えておき、
統計ファイルに出す。これで「ログが信用できるか」が後から判定できる。

### サイズの決め方

| リング | 段数 | サイズ | 何秒分か |
|---|---|---|---|
| CH1 | 2048段 | 約49 KB | 4,000 frame/s で約0.5秒 |
| CH2 | 1024段 | 約25 KB | 2,250 frame/s で約0.45秒 |

安価なSDカードの一時停止（数百ms）を吸収できる長さにしている。

v2.7から、このリングは**静的確保ではなくヒープ確保**になっている。
Wi-Fi/LTEの通信スタックが静的領域を圧迫してビルドが通らなくなったためで、
経緯は §15 の「リングバッファをヒープへ移した話」を参照。

記録終了時に `ring max used` を統計ファイルへ残すので、実機で余裕を確認したうえで
`config.h` の `RING_SIZE_CH1` / `RING_SIZE_CH2` を調整できる
（`#ifndef` ガードがあるので `build_flags` からも上書きできる）。

---

## 6. レコード形式とファイル形式

### 24バイト固定長レコード

1フレームを24バイトで表現する。

```cpp
struct CanRec {
  uint64_t ts_us;    // +0  受信時刻(µs)   8バイト
  uint32_t id;       // +8  CAN ID         4バイト
  uint8_t  dlc;      // +12 データ長       1バイト
  uint8_t  flags;    // +13 拡張ID/RTR     1バイト
  uint8_t  channel;  // +14 1 or 2         1バイト
  uint8_t  reserved; // +15 予備           1バイト
  uint8_t  data[8];  // +16 データ         8バイト
};                   //     合計          24バイト
```

**固定長にする理由**は、n番目のレコードが「32 + 24×n」バイト目にあると
計算だけで分かるから。可変長だと先頭から順に読む必要がある。

`static_assert(sizeof(CanRec) == 24)` を書いてあるのは、コンパイラが
勝手に隙間（パディング）を入れていないかをビルド時に検査するため。
ここがずれるとPC側の変換ツールが全く読めなくなる。

### なぜテキストではなくバイナリなのか

当初はASCテキスト形式で保存する予定だった。比較するとこうなる。

| 形式 | 1フレーム | 6,250 frame/s | 10分 |
|---|---|---|---|
| ASCテキスト | 約64バイト | 約400 kB/s | 約240 MB |
| **バイナリ** | **24バイト** | **約150 kB/s** | **約90 MB** |

標準の `SD` ライブラリの実効速度は300 kB/s〜1 MB/s程度なので、
**ASCだと安価なカードでは間に合わない**。

加えて、テキスト化には数値を文字列に変換する処理（`snprintf`）が必要で、
これが1件あたり数十マイクロ秒かかる。6,250件/秒だとCPU時間の無視できない割合を食う。

**「PC側でどうせ変換するのだから、MCUは生データを吐くだけにする」**という判断。

### ファイル全体の構造

```
┌──────────────────────────┐
│ ヘッダ 32バイト            │  magic, version, ビットレート, 開始時刻
├──────────────────────────┤
│ レコード 24バイト × N      │  フレームの本体
└──────────────────────────┘
```

ヘッダに `"CANLOG02"` という**マジックナンバー**を入れてある。
PC側は最初にこれを確認して、正しいファイルかを判定する。

---

## 7. タイムスタンプ

### 2種類の「時刻」

この治具は**性質の違う2つの時刻**を扱う。混同しやすいので分けて理解する。

| | 相対時刻 | 絶対時刻 |
|---|---|---|
| 何を表すか | 記録開始からの経過時間 | 実世界の何時何分 |
| 供給源 | `esp_timer_get_time()` | RTC（MCP7940N） |
| 分解能 | **1マイクロ秒** | 1秒 |
| 用途 | **フレーム間隔の解析、再生** | 他の記録との突合 |
| 無いとどうなるか | 解析不能 | 「いつのログか」が不明になるだけ |

### 相対時刻：esp_timer_get_time()

ESP32起動からの経過マイクロ秒を返す。64bitなので約58万年オーバーフローしない。

```cpp
rec.ts_us = esp_timer_get_time();   // 受信した瞬間に打刻
```

**この打刻を受信タスクの先頭で行う**のが重要。
SDに書くときに打刻すると、書き込み待ちの時間が誤差として乗ってしまう。

### 精度の限界（正直な話）

ESP32のTWAIもMCP2515も**ハードウェアで受信時刻を記録する機能がない**。
だから「ソフトがフレームを取り出した時刻」で代用している。

| | この治具 | PC接続型インタフェース |
|---|---|---|
| 打刻方法 | ソフトウェア | ハードウェア |
| 通常時の誤差 | ±数十µs〜±100µs | ns〜µs |
| バースト時 | 数ms遅れることがある | 影響なし |
| フレームの順序 | 保証される | 保証される |

つまりこの治具は**「何が起きたか」の解析には十分だが、「何マイクロ秒後に起きたか」の
精密測定には向かない**。バス負荷率の測定やエラーフレームの解析が必要なら
従来どおりPC接続型インタフェースを使う、という線引きにしている。

### 絶対時刻：RTCとUTC

RTCには**現地時刻（日本時間）**を設定する。現地作業者が見て分かるようにするため。
ファームウェアが内部でUTCに変換して `unix_time` に格納する。

```
RTCの値（JST）  ─ 9時間 →  unix_time（UTC）  ─ PC側で+9時間 →  表示（JST）
```

**なぜわざわざUTCで保存するのか。** 世界中どこで記録しても一意に定まる基準だから。
タイムゾーンをまたぐと現地時刻は曖昧になる。

---

## 8. 2チャネルのマージ

### 問題

CH1とCH2で別々のリングバッファを持っているので、
そのまま書き出すとファイル内で時刻がバラバラになる。

### マージの考え方

両方のバッファの**先頭を覗いて、時刻が古い方を取り出す**。

```cpp
if (両方にデータがある) {
    return (t1 <= t2) ? CH1から取り出す : CH2から取り出す;
}
```

### 片方が空のときの難しさ

CH1にだけデータがあるとき、すぐ書き出してよいだろうか。
**まだCH2に、もっと古いフレームが後から積まれるかもしれない。**

そこで**5ミリ秒の猶予**を設けている。

```cpp
if (now - t1 < MERGE_LAG_US) return false;   // まだ待つ
```

「5ms前より古いフレームなら、もう他方に追い抜かれる心配はない」という判断。

### それでも完璧ではない

この方式は「ほぼ順番どおり」にはなるが、保証はしない。
そこで**PC側の変換ツールで必ず時刻ソートする**という二段構えにしている。

```python
records.sort(key=lambda r: r[0])   # 保険
```

MCUで完璧を目指すより、**PC側で確実に直す方が安全で簡単**という判断。
59,010件のソートはPCなら一瞬で終わる。

---

## 9. 状態機械

### 5つの状態

```
        [電源ON]
           ↓
      ┌─ ST_IDLE ─────┐  LED消灯
      │      ↓開始ボタン │
      │  ST_LOGGING    │  LED点滅
      │      ↓停止ボタン │
      │  ST_DRAINING   │  LED点滅（残りを書き出し中）
      │      ↓         │
      │  ST_STOPPED ───┘  LED点灯
      │
      └─ ST_ERROR         LED高速点滅
```

| 状態 | 意味 |
|---|---|
| `ST_IDLE` | 待機中。開始ボタン待ち |
| `ST_LOGGING` | 記録中 |
| `ST_DRAINING` | 停止処理中。受信は止めたが、バッファに残ったデータを書き出している |
| `ST_STOPPED` | 完全に停止。**SDカードを抜いてよい** |
| `ST_ERROR` | 異常 |

**アップロード機能を足しても状態は増やしていない。**
「記録していないとき」の裏で動く処理として実装し、状態機械そのものは触っていない。

既存の縮退保存や異常復帰のロジックは、この状態機械を前提に組んである。
状態を1つ増やすと、遷移表の全マス目を見直すことになる。
機能を足すときは、**まず「既存の状態の内側で表現できないか」を考えたほうが安全**。

### ST_DRAINING がある理由

停止ボタンを押した瞬間、リングバッファにはまだ数百件のフレームが残っている。
すぐにファイルを閉じると、それが失われる。

そこで「受信は止めるが書き出しは続ける」という中間状態を置いている。

### 停止処理の順序

順序を間違えると資源が漏れたりクラッシュしたりする。

```
1. ST_DRAINING にする         ← 受信タスクが積むのをやめる
2. 50ms待つ                   ← 受信タスクが受信待ちから抜けるのを待つ
3. CANドライバを停止・解放     ← ここより前に抜けていないとクラッシュする
4. リングが空になるまで待つ
5. 書き込みバッファを吐き出す
6. ファイルを閉じる
7. 統計ファイルを書く
8. ST_STOPPED にする（LED点灯） ← 全部終わってから点灯させる
```

**8を最後にしている**のが肝。LED点灯＝「SDを抜いてよい」の合図なので、
ファイルを閉じる前に点灯させてはいけない。

### 縮退保存（異常時もログを残す）

記録中にSDの書き込みが失敗したとき、単にエラー状態にすると
**それまでのログも統計も残らない**。現地で「何が起きたか」が全く分からなくなる。

そこで、異常時も**正常停止と同じ手順を通す**設計にした。

```cpp
finalizeLogging(true);   // 引数は「異常終了かどうか」だけ
```

異常でも、そこまでのデータを書き出し、ファイルを閉じ、統計ファイルに
`exit: ABNORMAL` と `fault: SD write failed` を残してから高速点滅に入る。

### なぜエラー処理を loop() に集約するか

異常を検出するのは書き込みタスクや監視処理だが、
**後始末は必ず `loop()` から行う**というルールにしている。

理由は、書き込みタスクの中から「書き込みタスクの完了を待つ」処理を
呼ぶことができないから（自分自身を待つことになり固まる）。

```cpp
// 異常を検出した側は、要因を記録するだけ
g_fault = FAULT_SD_WRITE;

// loop() が拾って後始末する
if (g_state == ST_LOGGING && g_fault != FAULT_NONE) {
    finalizeLogging(true);
}
```

---

## 10. 割込みとISR

### 割込みとは

「何かが起きたら、今やっている処理を中断して、専用の関数を実行する」仕組み。
ポーリング（定期的に確認しに行く）より応答が速く、CPUも無駄にしない。

MCP2515は、フレームを受信すると `/INT` ピンをLowにする。
これをESP32が検出して、受信タスクを起こす。

### ISR（割込みハンドラ）の書き方

```cpp
static void IRAM_ATTR mcpIsr() {
  BaseType_t higherPriorityTaskWoken = pdFALSE;
  vTaskNotifyGiveFromISR(g_mcpTaskHandle, &higherPriorityTaskWoken);
  if (higherPriorityTaskWoken == pdTRUE) portYIELD_FROM_ISR();
}
```

**ISRには厳しい制約がある。**

| ルール | 理由 |
|---|---|
| `IRAM_ATTR` を付ける | 割込み中はフラッシュメモリを読めないことがある。RAM上に置く指定 |
| **可能な限り短くする** | ISR実行中は他の処理が全部止まる |
| `Serial.print` や `delay` を使わない | 長すぎる、内部でロックを取るため |
| SPI通信をしない | 同上。**通知だけしてタスクにやらせる** |

だからこのISRは「タスクを起こす」だけで、SPIでの読み出しは
`rxTaskMcp` に任せている。

### portYIELD_FROM_ISR() の意味（重要）

これを忘れると**性能が桁違いに落ちる**。実際に踏んだ。

`vTaskNotifyGiveFromISR()` は「このタスクを起こす」とFreeRTOSに伝えるだけ。
**すぐにそのタスクへ切り替わるとは限らない。**

```
portYIELD_FROM_ISR() なし:
  割込み発生 → ISR → 元の処理に戻る → …… → 次のティック(最大1ms後) → やっとタスクが動く

portYIELD_FROM_ISR() あり:
  割込み発生 → ISR → すぐにタスクへ切り替わる（数十µs）
```

250kbpsでは約444µsごとにフレームが来る。MCP2515の受信バッファは2段しかないので、
**1ms待つとちょうど埋まって3件目から溢れる**。

これが実際に起きて、周期メッセージの1.21%を取りこぼしていた（§16）。

### レベル割込みとエッジ割込み

MCP2515の `/INT` は**レベル出力**（未読フレームがある間ずっとLow）。
一方ESP32側は**立ち下がりエッジ**（HighからLowに変わった瞬間）で検出している。

ここに穴がある。

```
フレームA到着 → INT Low → エッジ検出 → タスク起床
タスクがAを読む間にフレームB到着 → INTはLowのまま（エッジが発生しない！）
タスクが「もう無い」と判断して眠る → Bが読まれないまま残る
```

対策として、**眠る前にピンの状態を直接確認**している。

```cpp
if (digitalRead(MCP_INT_GPIO) == HIGH) {   // Highなら未読なし
    ulTaskNotifyTake(pdTRUE, pdMS_TO_TICKS(5));   // 通知を待つ
}
// Lowならそのまま読みに行く
```

さらに保険として5msのタイムアウトも入れてある。

---

## 11. MCP2515ドライバ

外部ライブラリを使わず自作している（`src/mcp2515.h`）。
Listen-Only設定やビットタイミングを完全に制御したかったため。

### SPI通信の基本

MCP2515とは**SPI**という4本線のインタフェースで話す。

| 線 | 向き | 役割 |
|---|---|---|
| SCK | ESP32→MCP | クロック |
| SI (MOSI) | ESP32→MCP | データ送信 |
| SO (MISO) | MCP→ESP32 | データ受信 |
| /CS | ESP32→MCP | この石と話す間だけLowにする |

```cpp
spi_->beginTransaction(SPISettings(spiHz_, MSBFIRST, SPI_MODE0));
digitalWrite(cs_, LOW);     // 通信開始
spi_->transfer(CMD_READ);   // コマンド送信
spi_->transfer(addr);       // アドレス送信
v = spi_->transfer(0x00);   // 読み出し（ダミーを送ると返ってくる）
digitalWrite(cs_, HIGH);    // 通信終了
spi_->endTransaction();
```

SPIは**送信と受信が同時に起きる**。読むときも何か送る必要があるので `0x00` を送っている。

### SDカードと別のSPIバスにしている理由

ESP32にはSPIコントローラが2つある（VSPIとHSPI）。

- **SDカード → VSPI**
- **MCP2515 → HSPI**

同じバスを共有すると、SDの書き込み中はMCP2515を読めない。
SDは数百ms止まることがあるので、その間にCH2が溢れる。**物理的に分けるのが確実。**

### 初期化の手順

```cpp
1. ハードウェアリセット（/RESETピンをLow→High）
2. ソフトウェアリセット（SPI命令 0xC0）
3. コンフィグモードになっているか確認
4. ビットタイミング設定（CNF1/CNF2/CNF3）
5. 全フレーム受信に設定（フィルタ無効）+ ロールオーバ有効
6. 受信割込みを有効化
7. Listen-Onlyモードへ移行
8. 本当にListen-Onlyになったか確認
```

**設定した後に必ず読み返して確認している**のがポイント。
SPIの配線不良やはんだ不良は、書き込みだけでは検出できない。

### ビットタイミング（サンプルポイント）

CANは1ビットの中の**どこで電圧を読むか**を設定できる。これをサンプルポイントと呼ぶ。

```
1ビットの時間を16分割（TQ = Time Quantum）

|Sync|  PropSeg  | PhaseSeg1 |PS2|
| 1  |     6     |     7     | 2 |
                              ↑
                         ここで読む = 14/16 = 87.5%
```

**遅めに読むほうがノイズに強い。** 信号の立ち上がりが落ち着いてから読めるため。
CiA（CAN in Automation）は87.5%を推奨している。

ネット上によくあるMCP2515のサンプルコードは、この値が**56.25%**になっている
定数表を使っていることが多い。動作はするが、バスの立ち上がりリンギングに弱い。
本ドライバでは3レート共通で87.5%になるよう独自に算出している。

| ビットレート | CNF1 | CNF2 | CNF3 |
|---|---|---|---|
| 500 kbps | 0x00 | 0xB5 | 0x81 |
| 250 kbps | 0x01 | 0xB5 | 0x81 |
| 125 kbps | 0x03 | 0xB5 | 0x81 |

### 受信バッファとロールオーバ

MCP2515には受信バッファが**RXB0とRXB1の2つだけ**しかない。

`BUKT` ビットを立てると、RXB0が埋まったとき自動的にRXB1へ回してくれる
（ロールオーバ）。これで実質2段のバッファとして使える。

3件目が来る前に読み出せないと**溢れて失われる**。
だから割込みの応答速度が決定的に重要だった（§10）。

### IDの組み立て

MCP2515は受信したIDを4つのレジスタに分けて持っている。
これを元の数値に組み立て直す必要がある。

```cpp
if (拡張ID) {
  id = (b[0] << 21)              // SIDH: ID[28:21]
     | ((b[1] >> 5) << 18)       // SIDL上位3bit: ID[20:18]
     | ((b[1] & 0x03) << 16)     // SIDL下位2bit: ID[17:16]
     | (b[2] << 8)               // EID8: ID[15:8]
     | b[3];                     // EID0: ID[7:0]
} else {
  id = (b[0] << 3) | (b[1] >> 5);  // 標準IDは11bit
}
```

このビット割りはデータシートで定義されている。1箇所間違えるとIDが化ける。

---

## 12. RTCドライバ

`src/mcp7940.h`。I2C通信で時刻を読み書きする。

### I2Cの基本

SPIより線が少ない（2本）。**SDA**（データ）と**SCL**（クロック）だけ。
複数のICを同じ2本にぶら下げられ、**アドレス**で区別する。

MCP7940Nのアドレスは `0x6F`。

両方の線を抵抗（4.7kΩ）で電源に引き上げておく必要がある（プルアップ）。
ICは線を「Lowに引っ張る」ことしかできない仕組みのため。

### BCD形式

RTCは時刻を**BCD（Binary Coded Decimal）**で持っている。
これは「10進数の各桁を4ビットずつで表す」形式。

```
10進の 45  →  BCDでは 0x45（上位4bit=4, 下位4bit=5）
```

人間が読みやすい代わりに、計算には使えないので変換が必要。

```cpp
static uint8_t bcd2bin(uint8_t v) { return (v >> 4) * 10 + (v & 0x0F); }
static uint8_t bin2bcd(uint8_t v) { return ((v / 10) << 4) | (v % 10); }
```

### MCP7940Nで忘れると動かない3つのこと

| 項目 | レジスタ | 内容 |
|---|---|---|
| **発振器の起動** | RTCSEC bit7 = ST | **1を書かないと時計が動かない**（工場出荷時は0） |
| **バックアップ有効化** | RTCWKDAY bit3 = VBATEN | **デフォルト無効**。忘れると電源断で時刻が消える |
| 発振の確認 | RTCWKDAY bit5 = OSCRUN | 実際に回っているかの確認 |

**「電源を入れれば時計が動く」わけではない**のがポイント。
起動時に `oscillator stopped` と出るのは、`SETTIME` していなければ正常な状態。

### 32.768kHz水晶の起動は遅い

音叉型の32.768kHz水晶は**発振開始まで数百ms〜数秒**かかる。
16MHzの水晶が数msで起動するのとは桁が違う。

開発中、発振待ちを200msで打ち切る実装にしていたため
「水晶が壊れている」と誤判定していた。5秒に延ばして解決した（§16）。

### 日付の計算

「1970年1月1日から何秒経ったか」（UNIX時刻）への変換に、
**Howard Hinnantのdays_from_civilアルゴリズム**を使っている。

うるう年の判定（4で割れる年はうるう年、ただし100で割れる年は除く、
ただし400で割れる年はうるう年）を含めて、分岐なしで計算できる有名な実装。

標準ライブラリの `mktime()` を使わないのは、タイムゾーン設定に依存せず
確実に動かすため。実装は標準ライブラリと照合して検証済み（2099年まで、うるう年含む）。

### デジタルトリミング

水晶の誤差をソフトで補正できる。

| 項目 | 値 |
|---|---|
| 補正範囲 | ±129 ppm |
| 分解能 | 1.017 ppm / step |
| 動作 | 1分ごとにクロックパルスを加減算 |

ppm（parts per million）は100万分の1。30 ppmずれていると
1日あたり `30 ÷ 1,000,000 × 86,400秒 = 2.6秒` ずれる計算。

---

## 13. SDカードへの書き込み

### まとめて書く

1フレームごとに書くのではなく、**4KB溜めてから一気に書く**。

```cpp
while (g_wlen < WRITE_CHUNK_BYTES && popMerged(rec, draining)) {
    memcpy(&g_wbuf[g_wlen], &rec, sizeof(CanRec));
    g_wlen += sizeof(CanRec);
}
if (g_wlen >= WRITE_CHUNK_BYTES) flushWriteBuffer();
```

SDカードは内部的に512バイト単位（セクタ）で管理されているので、
細かく書くと**同じセクタを何度も読み書きする**ことになり極端に遅くなる。

### flush（フラッシュ）の意味

`write()` しただけでは、データはまだメモリ上のバッファにいることがある。
`flush()` を呼ぶと確実にカードへ書き込まれ、ファイルシステムの管理情報も更新される。

2秒ごとにflushしている。**記録中に電源が切れても、直前2秒分しか失われない。**

毎回flushすると遅くなり、全くしないと電源断で全部失う。その折衷。

### ファイル名の採番

```cpp
for (uint16_t i = 1; i <= 9999; i++) {
    snprintf(g_logPath, ..., "/LOG%04u.BIN", i);
    snprintf(g_txtPath, ..., "/LOG%04u.TXT", i);
    if (!SD.exists(g_logPath) && !SD.exists(g_txtPath)) return true;
}
```

`.BIN` と `.TXT` の**両方**を確認している。
片方だけ残っているケース（前回の記録を途中で消したなど）で上書きしないため。

SDカードのルートには `CONFIG.TXT`（設定）と `UPLOADED.TXT`（アップロード進捗）も置かれるが、
採番は `LOG%04u` 形式しか見ないので**衝突しない**。

### 統計ファイル

ログ本体とは別に `LOG0001.TXT` を出す。これが**ログの信頼性の証明書**になる。

```
exit            : normal (stop button)
frames logged   : 2747
ring dropped    : 0
ctrl missed     : 0
result          : OK
```

現地の作業者はCANの中身は分からなくても、
**このファイルを見れば「ちゃんと録れたか」が判断できる**。

---

## 14. PC側の変換ツール

`tools/bin_to_blf.py`。Pythonで書かれた変換スクリプト。

### やっていること

```python
1. ヘッダ32バイトを読んで magic を確認
2. 24バイトずつレコードを読む
3. 時刻順にソート（2chマージの保険）
4. python-can の BLFWriter でBLFへ書き出す
```

### 構造体の読み方

C言語の構造体と同じレイアウトで読む必要がある。

```python
REC = struct.Struct("<QIBBBB8s")
#                    │└─ 8s: data[8]
#                    │  BBBB: dlc, flags, channel, reserved
#                    │ I: id (uint32)
#                    └ Q: ts_us (uint64)
#                   < = リトルエンディアン（下位バイトが先）
```

**`<`（リトルエンディアン）の指定を忘れると全部化ける。**
ESP32もPCも通常リトルエンディアンだが、明示しておくのが安全。

### タイムゾーンの落とし穴

治具はUTCで保存する。python-canはBLFヘッダに**UTCをそのまま書く**。
ところが**CANalyzerはそのフィールドを現地時刻として表示する**。

つまり何もしないと**9時間ずれる**。

対策として、全タイムスタンプに現地のUTCオフセットを加算している。

```python
msg.timestamp = start_epoch + rel + tz_shift
```

**全フレームを同じ量だけずらすので、フレーム間の相対時刻は変わらない。**
BLF内の各フレームは「開始時刻からの差分」で記録されるため。

---

## 15. ログの自動アップロード

v2.6から、記録したログをWi-Fi経由でサーバーへ自動送信する機能が入った。
ここでは「なぜこう作ったか」を中心に説明する。

将来的にはWi-FiをLTE（SIM7600）へ置き換えて、現地へ行かずにログを回収できるようにする計画で、
**通信方式に依存しない部分を先に作って検証する**のがこの実装の目的でもある。

### 何のために要るか

治具を設置したあと、現地へ行かないと次のことが分からない。

- ちゃんと録れているのか
- 録れたログは信用できるのか（取りこぼしは無いか）
- SDカードの残りはあるか

**「行ってみたら録れていなかった」を無くす**のが第一の目的で、ログ本体の回収は二番目。
そのため統計ファイル（`LOGxxxx.TXT`、数KB）を**ログ本体より先に**送る作りにしている。

### 大原則：記録中は絶対に動かさない

この治具は「取りこぼしゼロ」を売りにしている。
アップロードがCPUやSDカードを奪えば、その前提が崩れる。

そこで、動いてよい状態を1か所で判定する。

```cpp
static bool upCanRun() {
  if (g_state == ST_LOGGING || g_state == ST_DRAINING) return false;
  if (g_fault == FAULT_SD_INIT || g_fault == FAULT_SD_WRITE) return false;
  return true;
}
```

記録中と停止処理中は問答無用で止まる。SDが壊れているときも触らない。
逆に `ST_ERROR` でも（SD以外の異常なら）動かすのは、**そこまでのログを回収したいから**。

### 中断のハンドシェイク（順序が命）

開始ボタンが押されたとき、アップロード側はSDのファイルハンドルを握っている可能性がある。
`startLogging()` は次の順番で手放させてから記録を始める。

```cpp
uploaderRequestStop();      // 1. 中断を要求する
uploaderWaitIdle(3000);     // 2. ファイルを閉じるまで待つ
uploaderWifiOff();          // 3. Wi-Fiを落とす
  ↓
hardCleanup();              // 4. ここで初めて SD.end() / SD.begin()
```

**この順序を逆にすると壊れる。** 先に `SD.end()` を呼ぶと、アップロード側が持っている
`File` オブジェクトが無効になり、次のアクセスで未定義動作になる。

中断の判定は送信ループの**1KBごと**に入れている。応答待ちで長く止まらないので、
実測では数十msで抜ける。

```cpp
while (remain > 0) {
  if (upShouldAbort()) { cli.stop(); return false; }   // ここ
  ...
  vTaskDelay(1);   // loop()を飢餓にしないため（§4参照）
}
```

### HTTP PUT で送る

送信は**HTTPのPUTメソッド**を使う。
「このURLに、このファイルを置け」という意味の、いちばん素直な方法。

```
PUT /canlog/JIG001/20260901_150227_LOG0006_001.bin HTTP/1.1
Host: 192.168.10.104:8080
Content-Type: application/octet-stream
Content-Length: 1048576
Connection: close

（ここから1,048,576バイトのデータ）
```

外部ライブラリを使わず `WiFiClient` で直接この文字列を組み立てている。
HTTPライブラリを入れるとメモリを食うし、中断制御が自分でできなくなるため。

`Content-Length` を先に宣言するので、**途中で切れたらサーバー側が気づける**。
これが後述の「壊れたファイルを残さない」仕組みになる。

### なぜ分割して送るのか

1MBずつに区切って送る。理由は3つ。

| 理由 | 内容 |
|---|---|
| 中断されても損失が小さい | 記録開始で中断されたとき、失うのは送りかけの1パートだけ |
| 回線が切れても再開できる | 圏外・瞬断の復帰後、失敗したパートから続けられる |
| サーバー側の上限 | SORACOM Harvest Files はセルラー経由で1ファイル100MiBまで |

パートは別々のファイルとして置かれ、PC側で `merge_parts.py` を使って連結する。

```
20260901_150227_LOG0006_001.bin   1,048,576 byte
20260901_150227_LOG0006_002.bin     319,696 byte
        ↓ 連結
20260901_150227_LOG0006.bin       1,368,272 byte
```

### 分割サイズは大きいほうがよい

実測すると、1パートあたり**約80msの固定費**（TCP接続とHTTPの往復）がかかっていた。

| チャンクサイズ | 実効速度 |
|---|---|
| 16 KB | 89〜94 kB/s |
| 1024 KB | 124〜166 kB/s |

16KBだと1パート約180msのうち、100msがデータ転送で**80msが待ち時間**になる。
LTEに置き換えるとATコマンドの往復が毎パート発生するので、この固定費はさらに大きくなる。
**既定の1024KBを維持すること。**

### 壊れたファイルを残さない

送信の途中で中断すると、サーバー側には「宣言したサイズより少ないデータ」が届く。

```
[23:48:41] SHORT  .../LOG0006_001.bin  7168/1048576 byte
```

サーバーはこれを検出してファイルを書かず、400を返す。
治具側は失敗として扱い、待機に戻ってから**同じパスへ送り直す**。

**同じパスに送れば上書きされる**ので、何度リトライしても結果は同じになる。
この性質を「冪等（べきとう）」といい、通信が不安定な環境では設計の要になる。

### 進捗をどう覚えるか

`/UPLOADED.TXT` に追記していくだけの単純なテキスト。

```
0006,P,000,1024        part 0（統計TXT）完了。末尾はチャンクサイズ[KB]
0006,P,001,1024        part 1 完了
0006,D,002,1368272     全パート完了（総パート数, 総バイト数）
```

起動時に `D` の行だけを読んで、完了済みのLOG番号を**ビットマップ**（1250バイト）に展開する。
9999ファイル分を1250バイトで持てるので、ファイル一覧を持つより圧倒的に軽い。

```cpp
static uint8_t g_upDone[(9999 / 8) + 1];   // 1250 byte

static inline bool upDoneGet(uint16_t idx) {
  return (g_upDone[idx >> 3] >> (idx & 7)) & 1;
}
```

`idx >> 3` がバイト位置、`idx & 7` がそのバイトの中のビット位置。
8で割った商と余りを求める計算を、ビット演算で書いたもの。

### チャンクサイズを一緒に記録する理由

**パート番号は、チャンクサイズを前提にした値**である。

part 1 が指すのは「先頭から1チャンク分」だが、その「1チャンク」が1024KBなのか16KBなのかで
実際のオフセットがまったく変わる。設定を変えたあとに古い進捗を信じると、

```
記録上の進捗 = part 1 完了  →  part 2 から再開
実際のオフセット = (2-1) × 16KB = 16KB
                   ↑ 本来はここまでに1024KB送っているはずだった
```

となり、**先頭の大部分を飛ばした欠けたファイルができる**。

そこで進捗行にチャンクサイズを書いておき、読むときに照合する。
一致しない記録は無視するので、設定を変えれば自動的に先頭から送り直しになる。

```
[UP] LOG0006 : progress reset (chunk size changed). resend from part 0
```

### Wi-Fiは必要なときだけONにする

待機中ずっとWi-Fiを繋いでおくと、消費電流が増えるうえ、
**記録開始時にOFFにする処理が余計に必要**になる。

そこで「送るものが見つかったら接続、無くなったら切断」という動きにしている。

```
待機 → SDを走査 → 未送信あり → Wi-Fi ON → 送信 → 全部終わった → Wi-Fi OFF
```

### リングバッファをヒープへ移した話

Wi-Fiを有効にしたら、**ビルドが通らなくなった**。

```
region `dram0_0_seg' overflowed by 2488 bytes
```

ESP32のDRAMは「静的データ（`.bss`）を置ける領域」に**固定の上限**があり、
ヒープはその外側のDRAMも使える、という構造になっている。

Wi-Fiスタックが約40KBの静的バッファを持ち込んだ結果、
リングバッファ（約74KB）を静的確保したままでは入りきらなくなった。

対策は、**大きいものをヒープへ移す**こと。

```cpp
// v2.6まで
static SpscRing<RING_SIZE_CH1> g_ring1;        // .bss に 49KB

// v2.7
static SpscRing<RING_SIZE_CH1>* g_ring1 = nullptr;
// setup() で
g_ring1 = new (std::nothrow) SpscRing<RING_SIZE_CH1>();
```

`std::nothrow` を付けているのは、確保に失敗したときに例外ではなく `nullptr` を返させるため。
失敗したらタスクを起動せず `ST_ERROR` に落とす。

**この変更で、リングサイズの制約は「静的領域に入るか」から「ヒープに余裕があるか」に変わった。**
実測で初期化後のヒープ残量は約164KBあり、まだ増やす余地がある。

### 設定ファイル（CONFIG.TXT）

SSIDや送信先をソースに直書きすると、変えるたびに再ビルドと
CH340E特有の手動書き込み操作（BOOT+EN）が必要になる。

そこでSDカードの `/CONFIG.TXT` から読むようにした。

```
WIFI_SSID   = your-ssid
WIFI_PASS   = your-password
UP_HOST     = 192.168.10.104
UP_CHUNK_KB = 1024
```

パーサは60行程度の自前実装で、**外部ライブラリを使わず、動的メモリも確保しない**。
不正な行は読み飛ばして既定値で動き、**起動は絶対に止めない**（既存の設計方針と同じ）。

### LTE化への備え

通信方式に依存するのは**3つの関数だけ**にしてある。

| 関数 | Wi-Fi版 | LTE版でやること |
|---|---|---|
| `upWifiUp()` | `WiFi.begin()` | ロードスイッチON、`AT` 応答待ち、`AT+CNMP=38`、`AT+CGACT` |
| `upWifiDown()` | `WiFi.mode(WIFI_OFF)` | `AT+CPOF` → 無応答確認 → ロードスイッチOFF |
| `upPutRange()` | `WiFiClient` で直接PUT | `AT+HTTPINIT` → `AT+HTTPDATA` → `AT+HTTPACTION=1` |

分割・再送・進捗管理・中断処理はそのまま使える。
**`upPutRange()` の引数と戻り値（remotePath, File&, offset, length → bool）を変えないこと**が、
差し替えを楽にするための約束になっている。

---

## 16. 開発中に踏んだバグと教訓

実際に発生した不具合と、その原因・対策。同種の設計をするときの参考に。

### バグ1: ISRでタスク切り替えを要求していなかった

| 項目 | 内容 |
|---|---|
| **症状** | CH2で周期メッセージの1.21%が欠落（ID 341は17.3%） |
| **原因** | `vTaskNotifyGiveFromISR()` の第2引数に `nullptr` を渡していた |
| **結果** | 受信タスクの起床が**次のティック（最大1ms）まで遅延** |
| **なぜ問題か** | 250kbpsではフレーム間隔が444µs。1ms待つと2段のバッファが埋まる |
| **対策** | `portYIELD_FROM_ISR()` を追加。起床遅延が1ms→数十µsに |

**どう気づいたか。** 実機ログを解析したところ、

- 1回の起床で読んだフレーム数が「1件…1,672回 / **2件…1,311回**」
- **起床間隔の最小値が999µs**（1000µs未満は3,026回中9回だけ）

という分布が出た。1msに量子化されているのはティック境界で起きている証拠だった。

**教訓**: 統計を残しておくと、後から定量的に原因を特定できる。
「なんとなく遅い」ではなく「1msに量子化されている」まで分かると原因が絞れる。

### バグ2: 修正した際に飢餓バグを作り込んだ

| 項目 | 内容 |
|---|---|
| **症状** | シリアルもボタンもLEDも全部無反応。起動ログも途中で止まる |
| **原因** | `/INT` のレベルチェックを追加した際、「記録中でない」判定を**その後ろ**に置いた |
| **結果** | CH2をバスに接続した待機状態で、**どこでもブロックせずに回り続けた** |
| **なぜ問題か** | 優先度19・コア1固定のため、優先度1の `loop()` が飢餓状態に |
| **対策** | 状態判定を先頭へ移動。記録中でなければ必ず `vTaskDelay()` |

**どう気づいたか。** 起動ログの最後の2行（`free heap after init` と
`type HELP for serial commands.`）**だけが出ていなかった**。
これは `setup()` が完走していない＝タスク生成の直後で止まっている、という意味だった。

**教訓**: 起動ログを段階的に出しておくと、どこで止まったかが一目で分かる。
また、**CH2を接続していない環境では絶対に再現しなかった**。
条件付きでしか出ないバグがあることを前提に、実環境に近い条件で試験する必要がある。

### バグ3: 異常時に復帰できなくなる

| 項目 | 内容 |
|---|---|
| **症状** | 一度エラーになると、開始ボタンを押しても復帰しない |
| **原因** | エラー時にCANドライバとファイルを解放していなかった |
| **結果** | 再開始しようとしても「既に初期化済み」で失敗し続ける |
| **対策** | `hardCleanup()` を追加し、記録開始の冒頭で必ず全解放 |

**教訓**: 「失敗したときに元の状態に戻す」処理は、正常系より書き忘れやすい。
**すべての失敗経路で資源が解放されるか**を意識的に確認する必要がある。

### バグ4: 水晶の起動待ちが短すぎた

| 項目 | 内容 |
|---|---|
| **症状** | `RTC write failed` が出て時刻設定できない |
| **原因** | 発振の立ち上がりを200msしか待っていなかった |
| **実際** | 32.768kHz水晶の起動には数百ms〜数秒かかる |
| **対策** | 5秒に延長。さらに「書き込みの成否」と「発振待ち」を分離 |

**教訓**: エラーメッセージが原因を誤って示すと、切り分けが大きく遠回りになる。
`RTC write failed`（I2Cの問題に見える）と表示していたため、
実際は発振待ちの問題なのに、はんだ不良を疑ってしまった。

**1つの戻り値に複数の意味を持たせない**。

### バグ5: コールド起動時にSD初期化が失敗する

| 項目 | 内容 |
|---|---|
| **症状** | 電源投入時は必ずLEDが高速点滅。リセットすると直る |
| **原因** | ESP32は約300msで初期化に入るが、SDカードは規格上最大1秒応答しなくてよい |
| **対策** | 起動時に300ms待機 + SD初期化を5回リトライ |

**教訓**: 「リセットすれば直る」で済ませない。現地作業者にとっては故障に見える。

### バグ6: 「統計のみ」設定が手動コマンドにも効いてしまった

`UP_STATS_ONLY = 1` は「自動では統計ファイルだけ送る」という設定のつもりだったが、
判定を送信関数の中に置いたため、**`UPLOAD LOG0007` と明示的に指定してもBINが送られなかった**。

| | |
|---|---|
| **症状** | 統計のみモードで、手動コマンドを打ってもログ本体が回収できない |
| **原因** | `upSendOneFile()` が自動／手動を区別せずに設定フラグを見ていた |
| **対策** | `forced` 引数を追加し、明示指定時は設定を無視する |

**教訓**: 「既定の振る舞い」と「明示的な指示」は別物として扱う。
設定は前者にだけ効かせる。

### バグ7: チャンクサイズを変えると欠けたファイルができた

分割サイズを1024KBから16KBに変えて再送したところ、先頭部分が抜けたファイルができた。

| | |
|---|---|
| **症状** | 設定変更後の再送で、先頭のパートが飛ばされる |
| **原因** | 進捗記録が「part 1 完了」としか持っておらず、**その1パートが何バイトだったかを記録していなかった** |
| **対策** | 進捗行にチャンクサイズを書き、読むときに照合する。不一致なら進捗を無効化する |

**教訓**: 番号やインデックスを保存するときは、**それを解釈するための前提も一緒に保存する**。
「part 1」は単体では意味を持たない。

### バグ8: 中断された指示が黙って消えていた

`UPLOAD 6` を実行中に記録を開始し、記録終了後に再開するはずが、
**まったく別のファイル（新しく録れたログ）が送られていた**。

原因は2段階あった。

| 段階 | 内容 |
|---|---|
| 1 | 中断されたとき、指定要求を積み直していなかった |
| 2 | 積み直すようにしたら、今度は `finalizeLogging()` が出す「走査やり直し要求」が**同じ変数を上書き**していた |

```cpp
// 修正前：同じ変数に2種類の要求を入れていた
static volatile uint16_t g_upReq = 0;   // 0=なし / 1..9999=指定 / 0xFFFF=走査

uploaderRequestScan() { g_upReq = UP_REQ_SCAN; }   // ← 積み直した「6」を潰す
```

**記録が終わるたびに必ず走査要求が出る**ので、中断された指定要求は100%失われていた。

```cpp
// 修正後：別々に持ち、指定を優先する
static volatile uint16_t g_upReq     = 0;      // 指定ファイル
static volatile bool     g_upScanReq = false;  // 走査のやり直し
```

**教訓**: 意味の違うものを1つの変数に詰め込むと、片方が片方を壊す。
「値が0以外なら指定、特別な値なら別の意味」という設計は、後から必ず破綻する。

この不具合は、**遠隔からコマンドでログを取りに行く運用では致命的**だった。
「LOG0007を送れ」という指示が、記録が1回入っただけで消えてしまう。

### 設計判断として効いたこと

| 判断 | 効果 |
|---|---|
| 統計ファイルを出す | 実機ログから定量的に原因を特定できた |
| 起動ログを段階的に出す | どこで止まったかが一目で分かった |
| リングバッファに `max used` を記録 | 「バッファは余裕」と分かり、原因を別の場所に絞れた |
| PC側でも時刻ソート | MCU側のマージが不完全でも実害が出ない |
| `static_assert` でサイズ検査 | 構造体レイアウトのずれをビルド時に検出 |
| 通信層を3関数に閉じ込めた | Wi-Fiで全機能を検証してからLTEへ差し替えられる |
| 中断を「失敗」と区別した | `fail=` が回線品質の指標として使える |

---

## 17. 用語集

| 用語 | 意味 |
|---|---|
| **CAN** | Controller Area Network。2本の線で通信する車載向け規格 |
| **フレーム** | CANの通信単位。ID・データ長・データを含む |
| **ID** | フレームの識別番号。宛先ではなく「内容の種類」を表す |
| **DLC** | Data Length Code。データの長さ（0〜8バイト） |
| **ビットレート** | 1秒に送れるビット数。500kbps = 毎秒50万ビット |
| **Listen-Only** | ACKも返さない完全な傍受モード |
| **終端抵抗** | バス両端に付ける120Ω。信号の反射を防ぐ |
| **TWAI** | ESP32内蔵のCANコントローラの名称 |
| **MCP2515** | Microchip社の外付けCANコントローラIC |
| **SPI** | 4本線の高速通信。SDカードやMCP2515で使用 |
| **I2C** | 2本線の通信。RTCで使用 |
| **FreeRTOS** | ESP32上で動くリアルタイムOS |
| **タスク** | FreeRTOSで並行実行される処理の単位 |
| **優先度** | どのタスクを優先するかの数値。大きいほど優先 |
| **飢餓（starvation）** | 優先度の低いタスクが動けなくなる状態 |
| **ISR** | Interrupt Service Routine。割込み発生時に呼ばれる関数 |
| **ティック** | FreeRTOSの時間の刻み。ESP32では1ms |
| **リングバッファ** | 配列を輪状に使う待ち行列 |
| **SPSC** | Single Producer Single Consumer。生産者・消費者が1つずつ |
| **メモリバリア** | CPUの書き込み順序入れ替えを抑制する指示 |
| **RTC** | Real Time Clock。電池で時刻を保持するIC |
| **BCD** | 10進の各桁を4ビットで表す形式 |
| **ppm** | parts per million。100万分の1 |
| **UTC** | 協定世界時。日本時間はUTC+9 |
| **BLF** | Vector社のログ形式。CANalyzerで再生可能 |
| **DBC** | CANの信号定義ファイル。IDとビット位置から意味を復元する |
| **エンディアン** | 多バイト数値のバイト並び順。リトル＝下位が先 |
| **フラッシュ** | バッファの内容を確実に書き出すこと |
| **HTTP PUT** | 指定したURLへファイルを置くHTTPのメソッド |
| **冪等（べきとう）** | 何度実行しても結果が同じになる性質。再送の設計で重要 |
| **チャンク** | 分割送信の1単位。本機では既定1MB |
| **ビットマップ** | 1ビットを1要素の真偽値として使う配列。省メモリ |
| **.bss** | 初期値0の静的変数が置かれる領域。ESP32では容量上限がある |
| **ヒープ** | 実行時に動的確保されるメモリ領域 |

---

## 参考：ソースファイルの読む順番

初めて読むなら、この順がおすすめ。

| # | ファイル | 何が分かるか |
|---|---|---|
| 1 | `src/config.h` | ピン配置と設定値。全体像の入口 |
| 2 | `src/ring_buffer.h` | データの持ち方。一番小さくて読みやすい |
| 3 | `src/main.cpp` の `setup()` | 起動時に何を初期化するか |
| 4 | `src/main.cpp` の各タスク | 実際の処理の流れ |
| 5 | `src/main.cpp` の `startLogging()` / `finalizeLogging()` | 状態遷移 |
| 6 | `src/mcp2515.h` | SPIでICを制御する例 |
| 7 | `src/mcp7940.h` | I2CでICを制御する例 |
| 8 | `src/cfgfile.h` | 設定ファイルのパーサ。短くて読みやすい |
| 9 | `src/uploader.h` | 分割・再送・進捗管理。通信を伴う処理の組み立て方 |
| 10 | `tools/bin_to_blf.py` | ファイル形式の仕様そのもの |

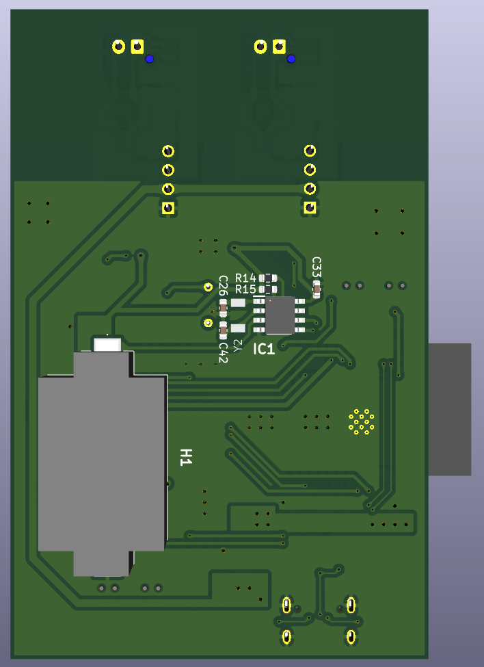
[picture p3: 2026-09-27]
images/3Dmodel_2.png

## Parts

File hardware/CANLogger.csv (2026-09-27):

Reference | Qty | Value | DNP | Exclude from BOM | Exclude from Board | Exclude from Simulation | Exclude from Position Files | Footprint | Datasheet
C1,C2,C3,C4 | 4 | GRM21BB31H475KE51 |  |  |  |  | ${EXCLUDE_FROM_POS_FILES} | Capacitor_SMD:C_0805_2012Metric
C9,C10 | 2 | GRM31CB31H106KA12 |  |  |  |  | ${EXCLUDE_FROM_POS_FILES} | Capacitor_SMD:C_1206_3216Metric
C13,C14 | 2 | GRM32EB31E226KE15 |  |  |  |  | ${EXCLUDE_FROM_POS_FILES} | Capacitor_SMD:C_1210_3225Metric
C21,C27,C28,C29,C30,C31,C32,C33,C34,C35,C36,C37,C38,C39,C40,C41 | 16 | GRM188F11H104ZA01 |  |  |  |  | ${EXCLUDE_FROM_POS_FILES} | Capacitor_SMD:C_0603_1608Metric
C24,C25 | 2 | GRM1882C1H220JA01 |  |  |  |  | ${EXCLUDE_FROM_POS_FILES} | Capacitor_SMD:C_0603_1608Metric
C26,C42 | 2 | CL10C070CB8NNNC |  |  |  |  | ${EXCLUDE_FROM_POS_FILES} | Capacitor_SMD:C_0603_1608Metric
D1,D2 | 2 | RESD1CANYT116 |  |  |  |  | ${EXCLUDE_FROM_POS_FILES} | 0_Library:RESD1CANYT116 | https://fscdn.rohm.com/en/products/databook/datasheet/discrete/diode/zener/resd1canyt116-e.pdf
D3,D4 | 2 | SML-E12P8WT86 |  |  |  |  | ${EXCLUDE_FROM_POS_FILES} | 0_Library:SML-E12P8WT86
F1 | 1 | MF-FSML100_8-2_2 |  |  |  |  | ${EXCLUDE_FROM_POS_FILES} | 0_Library:MF-FSML100_8-2
FL2,FL3 | 2 | ACT45B-101-2P-TL003_2 |  |  |  |  | ${EXCLUDE_FROM_POS_FILES} | 0_Library:ACT45B-101-2P-TL003
H1 | 1 | CH28-2032LF |  |  |  |  | ${EXCLUDE_FROM_POS_FILES} | 0_Library:CH28-2032LF | https://www.tme.eu/Document/5d60107298668397910bba4fb19fe6d5/CoinCell.pdf
IC1 | 1 | MCP7940N-I_SN |  |  |  |  | ${EXCLUDE_FROM_POS_FILES} | 0_Library:MCP7940N-ISN | https://datasheet.datasheetarchive.com/originals/distributors/Datasheets-DGA3/278324.pdf
J1 | 1 | 5077CR-16SMC2-BK-TR |  |  |  |  | ${EXCLUDE_FROM_POS_FILES} | 0_Library:5077CR-16SMC2-BK-TR
J2,J3 | 2 | B02B-XASK-A |  |  |  |  | ${EXCLUDE_FROM_POS_FILES} | 0_Library:B02B-XASK-1-A
J4 | 1 | DM3AT-SF-PEJM5 |  |  |  |  | ${EXCLUDE_FROM_POS_FILES} | 0_Library:microSD_HC_Hirose_DM3AT-SF-PEJM5 | https://www.we-online.com/components/products/datasheet/693072010801.pdf
L1 | 1 | DFE322520FD-3R3M=P2 |  |  |  |  | ${EXCLUDE_FROM_POS_FILES} | 0_Library:DFE322520FD-3R3M_P2
PS1,PS2 | 2 | NME1S0505SC |  |  |  |  | ${EXCLUDE_FROM_POS_FILES} | 0_Library:NME1S0505SC | https://www.murata.com/products/productdata/8822286319646/KDC-NME1.pdf?1689910216000
R1,R2 | 2 | RK73H1JTTD5101F |  |  |  |  | ${EXCLUDE_FROM_POS_FILES} | Resistor_SMD:R_0603_1608Metric
R3,R4 | 2 | RK73B2ETTD101J |  |  |  |  | ${EXCLUDE_FROM_POS_FILES} | Resistor_SMD:R_1210_3225Metric
R5 | 1 | RK73H1JTTD3322F |  |  |  |  | ${EXCLUDE_FROM_POS_FILES} | Resistor_SMD:R_0603_1608Metric
R8,R9,R10,R11,R13,R16,R17,R18,R19,R20,R22,R23,R26,R27 | 14 | RK73B1JTTD103J |  |  |  |  | ${EXCLUDE_FROM_POS_FILES} | Resistor_SMD:R_0603_1608Metric
R12,R21 | 2 | RK73B1JTTD102J |  |  |  |  | ${EXCLUDE_FROM_POS_FILES} | Resistor_SMD:R_0603_1608Metric
R14,R15 | 2 | RK73B1JTTD472J |  |  |  |  | ${EXCLUDE_FROM_POS_FILES} | Resistor_SMD:R_0603_1608Metric
R24,R25,R28,R29 | 4 | RK73Z1JTTD |  |  |  |  | ${EXCLUDE_FROM_POS_FILES} | Resistor_SMD:R_0603_1608Metric
SW1,SW2,SW3,SW4 | 4 | TVAF06-A020B-R |  |  |  |  | ${EXCLUDE_FROM_POS_FILES} | 0_Library:TVAF06A020BR
U1 | 1 | ESP32-WROOM-32E |  |  |  |  | ${EXCLUDE_FROM_POS_FILES} | RF_Module:ESP32-WROOM-32E
U2,U4 | 2 | ISO1042DWV |  |  |  |  | ${EXCLUDE_FROM_POS_FILES} | 0_Library:ISO1042DWV
U3 | 1 | TPS562201DDCR |  |  |  |  | ${EXCLUDE_FROM_POS_FILES} | 0_Library:TPS562201DDCR
U5 | 1 | MCP2515T-I/SO |  |  |  |  | ${EXCLUDE_FROM_POS_FILES} | 0_Library:MCP2515T-ISO
U6 | 1 | CH340E |  |  |  |  | ${EXCLUDE_FROM_POS_FILES} | 0_Library:CH340E
U8 | 1 | TPD2E2U06DCKR |  |  |  |  | ${EXCLUDE_FROM_POS_FILES} | 0_Library:TPD2E2U06DCKR
Y1 | 1 | HUSG-16.000-20_2 |  |  |  |  | ${EXCLUDE_FROM_POS_FILES} | 0_Library:HUSG-16.000-20
Y2 | 1 | 32.768K12.5PI/4115E |  |  |  |  | ${EXCLUDE_FROM_POS_FILES} | 0_Library:32.768K12.5PI4115E

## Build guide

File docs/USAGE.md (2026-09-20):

# CANログ取得治具 操作手順書

現場でCANログを取得し、解析側へ送るまでの手順。

---

## 1. 治具の構成

```
┌─────────────────────────────────┐
│  [LED]        [開始]  [停止]     │
│                                 │
│  [CH1]  [CH2]        [USB-C]    │
│  500k   250k          [SD]      │
└─────────────────────────────────┘
```

| 部位 | 用途 |
|---|---|
| CH1コネクタ | 測定対象の**500kbps**バスへ接続 |
| CH2コネクタ | 測定対象の**250kbps**バスへ接続 |
| 開始ボタン | 記録開始 |
| 停止ボタン | 記録停止 |
| LED | 状態表示（§3） |
| USB-C | 電源。**モバイルバッテリー**から給電 |
| microSD | ログの保存先 |

> **Wi-Fiアップロード機能**が使える構成もあります。§10を参照してください。
> 設定していない場合は、従来どおりSDカードを持ち帰る運用のままで問題ありません。

> **CH1とCH2のコネクタは同じ形状です。** ケーブルのタグと基板の刻印を必ず確認してください。
> 挿し間違えてもエラーは出ず、**そのチャネルだけ0件で終わります**（§6で確認できます）。

---

## 2. 準備

### 事前に用意するもの

- microSDカード（FAT32でフォーマット済み、8GB程度で十分）
- USBモバイルバッテリー
- CAN接続ケーブル（CH1用・CH2用）

### 接続

1. microSDカードを挿す
2. USBモバイルバッテリーを繋ぐ
3. LEDが**消灯**していることを確認する（＝準備完了）

> **LEDが高速点滅する場合**は異常です。§5を確認してください。

---

## 3. LEDの見方

| LED | 状態 | 意味 |
|---|---|---|
| **消灯** | 待機 | 準備完了。開始ボタンを押せる |
| **ゆっくり点滅**（1秒に2〜3回） | 記録中 | **SDカードを抜かないこと** |
| **短く2回ずつ点滅**（1秒周期） | 送信中 | ログをアップロード中。**SDカードを抜かないこと** |
| **点灯したまま** | 停止完了 | **SDカードを抜いてよい** |
| **高速点滅**（1秒に6回） | 異常 | §5を参照 |

**覚えることは1つだけです。**

> **点滅している間はSDカードを抜かない。点灯に変わってから抜く。**

送信中の点滅も同じルールで扱ってください。送信が終われば点灯に戻ります。

---

## 4. 記録の手順

### 手順

| # | 操作 | 確認すること |
|---|---|---|
| 1 | 電源を入れる | LEDが**消灯** |
| 2 | CH1・CH2のケーブルを接続する | タグと刻印が合っているか |
| 3 | **開始ボタン**を押す | LEDが**点滅を始める** |
| 4 | 事象を再現させる | — |
| 5 | **停止ボタン**を押す | LEDが**点灯に変わるまで待つ** |
| 6 | SDカードを抜く | LEDが点灯していること |

### 注意

- **停止ボタンを押してから、LEDが点灯に変わるまで数秒かかります。** 焦らず待ってください
- 点滅中にSDカードを抜くと**ファイルが壊れます**
- 記録中に電源が切れた場合も、そこまでのデータは残っていることが多いです。SDカードを抜いて解析側へ送ってください
- 記録は自動では止まりません。**必ず停止ボタンを押してください**
- 停止後にLEDが**短く2回ずつ点滅**し始めたら、アップロード中です。点灯に変わるまで待ってください

### 記録時間の目安

| 記録時間 | ファイルサイズの目安 |
|---|---|
| 1分 | 約2 MB |
| 10分 | 約20 MB |
| 1時間 | 約120 MB |

8GBのSDカードなら数十時間分記録できます。**長めに録っても問題ありません。**

---

## 5. 異常時の対応

LEDが**高速点滅**したときの対処です。

| 状況 | 確認すること |
|---|---|
| 電源投入直後から高速点滅 | SDカードが挿さっているか。別のカードで試す |
| 開始ボタンを押したら高速点滅 | SDカードの空き容量。書き込み禁止になっていないか |
| 記録中に高速点滅に変わった | SDカードの接触不良か容量不足。**そこまでのログは保存されています** |

### 復帰のしかた

1. **開始ボタンを押す**と再試行します
2. 直らない場合は電源を入れ直す
3. それでも直らない場合は、SDカードを抜いて管理者へ連絡してください

**高速点滅になっても、それまでに記録したログとエラー内容はSDカードに残っています。**
カードを抜いて解析側へ送れば、原因が分かります。

---

## 6. 記録後の確認（重要）

SDカードには2つのファイルができます。

| ファイル | 内容 |
|---|---|
| `LOG0001.BIN` | CANログ本体 |
| `LOG0001.TXT` | **記録結果のレポート** |

**`LOG0001.TXT` をメモ帳で開いて、以下を確認してください。**

```
exit            : normal (stop button)      ← ここが normal であること

-- CH1 (internal TWAI) --
frames logged   : 2747                      ← 0 でないこと
ring dropped    : 0   (frames)              ← 0 であること
ctrl missed     : 0   (frames)              ← 0 であること

-- CH2 (MCP2515) --
frames logged   : 54263                     ← 0 でないこと
ring dropped    : 0   (frames)              ← 0 であること
ctrl ovf events : 0   (events, not frames)  ← 0 であること

result          : OK                        ← これが出れば全部問題なし
```

### 判定

| 表示 | 意味 | 対応 |
|---|---|---|
| `result : OK` | **問題なし** | そのまま送付 |
| `CH1 received nothing` | CH1が0件 | **ケーブルの挿し間違い**の可能性。接続を確認して録り直す |
| `CH2 received nothing` | CH2が0件 | 同上 |
| `frame loss detected` | 取りこぼしあり | 送付してよいが、解析側へ一報 |
| `exit : ABNORMAL` | 異常終了 | `fault` 行の内容とあわせて管理者へ連絡 |

> **片方だけ0件の場合は、ほぼ挿し間違いです。** CH1とCH2のケーブルを入れ替えて録り直してください。

---

## 7. 解析側への送付

以下をセットで送ってください。

- `LOG0001.BIN`（ログ本体）
- `LOG0001.TXT`（レポート）
- **記録した日時**（治具のRTCが未設定の場合に必要）
- 現地の状況（何をしたときに、どんな事象が起きたか）

ファイルは記録するたびに `LOG0002`, `LOG0003`... と番号が増えます。
**複数回記録した場合は、どれがどの事象か分かるようにメモを添えてください。**

---

## 8. やってはいけないこと

| 禁止事項 | 理由 |
|---|---|
| **点滅中にSDカードを抜く** | ファイルが壊れる |
| **測定中にPCを接続する** | グランドループができて治具や測定対象を壊す恐れがある |
| **高電圧のバスに接続する** | この治具は**制御系CAN専用**です |
| コネクタを無理に挿す | CH1とCH2は形状が同じです。タグを確認してください |

---

## 9. 困ったときは

| 症状 | 対応 |
|---|---|
| LEDが全く点かない | モバイルバッテリーの残量。USBケーブルを替えてみる |
| 開始ボタンを押しても点滅しない | LEDが高速点滅していないか確認（§5） |
| SDカードが認識されない | FAT32でフォーマットし直す |
| ファイルが作られない | SDカードの空き容量と書き込み禁止スイッチ |

上記で解決しない場合は、**SDカードを抜いて管理者へ連絡**してください。

---

## 10. Wi-Fiアップロード（設定してある場合のみ）

SDカードを持ち帰らずに、ログをサーバーへ自動送信する機能です。
**設定していない治具では何も起きません。** 従来どおりの操作で使えます。

### 10.1 何が起きるか

```
記録を停止する
  ↓
LEDが「短く2回ずつ点滅」に変わる   ← 送信中
  ↓
サーバーにログが届く
  ↓
LEDが点灯に戻る                     ← SDカードを抜いてよい
```

**送信中もSDカードからログは消えません。** 送信が失敗しても、カードを持ち帰れば回収できます。

### 10.2 記録中は送信されません

**記録中（ゆっくり点滅）はアップロードが完全に停止します。**
送信中に開始ボタンを押した場合も、送信が中断されて記録が優先されます。

中断された送信は、記録が終わってから自動的に続きから再開されます。

### 10.3 事前設定

SDカードのルートに `CONFIG.TXT` を置きます。

```
WIFI_SSID = 接続先のSSID
WIFI_PASS = パスワード
UP_HOST   = 送信先のIPアドレス
UP_PORT   = 8080
DEVICE_ID = JIG001
```

| 項目 | 内容 |
|---|---|
| `DEVICE_ID` | 治具の識別名。**治具ごとに変えてください**。送信先のフォルダ名になります |
| `UP_ENABLE` | `0` にするとアップロードを止められます |

> **ファイルが無くても起動します。** その場合はアップロードしないだけで、記録は通常どおり動きます。

### 10.4 動いているか確認したいとき

治具のUSB-CをPCに繋ぎ、シリアルモニタ（115200bps）で `UPSTAT` と打ちます。

```
> UPSTAT
upload  : phase=idle  boot#=4  ok=6  fail=0  sent=1715725 byte
          last: LOG0006 uploaded (2 parts)
wifi    : your-ssid  ip=192.168.10.106  rssi=-43 dBm
policy  : A (everything auto)
dest    : http://192.168.10.104:8080/canlog/JIG001/  chunk=1024 KB
```

| 表示 | 意味 |
|---|---|
| `phase=idle` | 送るものが無い（=全部送信済み） |
| `phase=sending` | 送信中 |
| `phase=blocked` | 記録中なので停止している |
| `phase=retry` | 失敗して再試行待ち |
| `fail=0` | 通信エラーなし。**0でなければ電波かサーバーを疑う** |

> **測定中にPCを接続しないでください。** グランドループができて治具や測定対象を壊す恐れがあります（§8）。
> `UPSTAT` の確認は、測定対象から切り離した状態で行ってください。

### 10.5 うまくいかないとき

| 症状 | 確認すること |
|---|---|
| LEDが点滅に変わらない | `CONFIG.TXT` の `WIFI_SSID` / `UP_HOST` が空でないか |
| `connect failed` が出る | サーバーが起動しているか。PCのファイアウォールで通信が止められていないか |
| `wifi connect timeout` | SSIDとパスワード。治具が電波の届く場所にあるか |
| 急に繋がらなくなった | サーバーPCのIPアドレスが変わっていないか |

**どの場合でも、SDカードにログは残っています。** カードを持ち帰れば回収できます。

### 10.6 送信されたファイル

サーバー側にはこのように置かれます。

```
canlog/JIG001/
    20260901_150227_LOG0006.txt        レポート
    20260901_150227_LOG0006_001.bin    ログ本体（分割）
    20260901_150227_LOG0006_002.bin
```

**ログ本体は1MBごとに分割されています。** 解析側で連結してから使います。

```bash
python tools/merge_parts.py canlog/JIG001
```

---

## 付録：現場チェックリスト（印刷用）

```
□ microSDカードを挿した
□ 電源を入れた（LED消灯を確認）
□ CH1ケーブル … 500kbps側へ接続
□ CH2ケーブル … 250kbps側へ接続
□ 開始ボタンを押した（LED点滅を確認）
□ 事象を再現させた
□ 停止ボタンを押した
□ LEDが点灯に変わるのを待った（送信中の点滅が終わるまで待つ）
□ SDカードを抜いた
□ LOG____.TXT を開いて result : OK を確認した
□ 記録日時をメモした（         年   月   日   時   分）
□ 事象の内容をメモした
```

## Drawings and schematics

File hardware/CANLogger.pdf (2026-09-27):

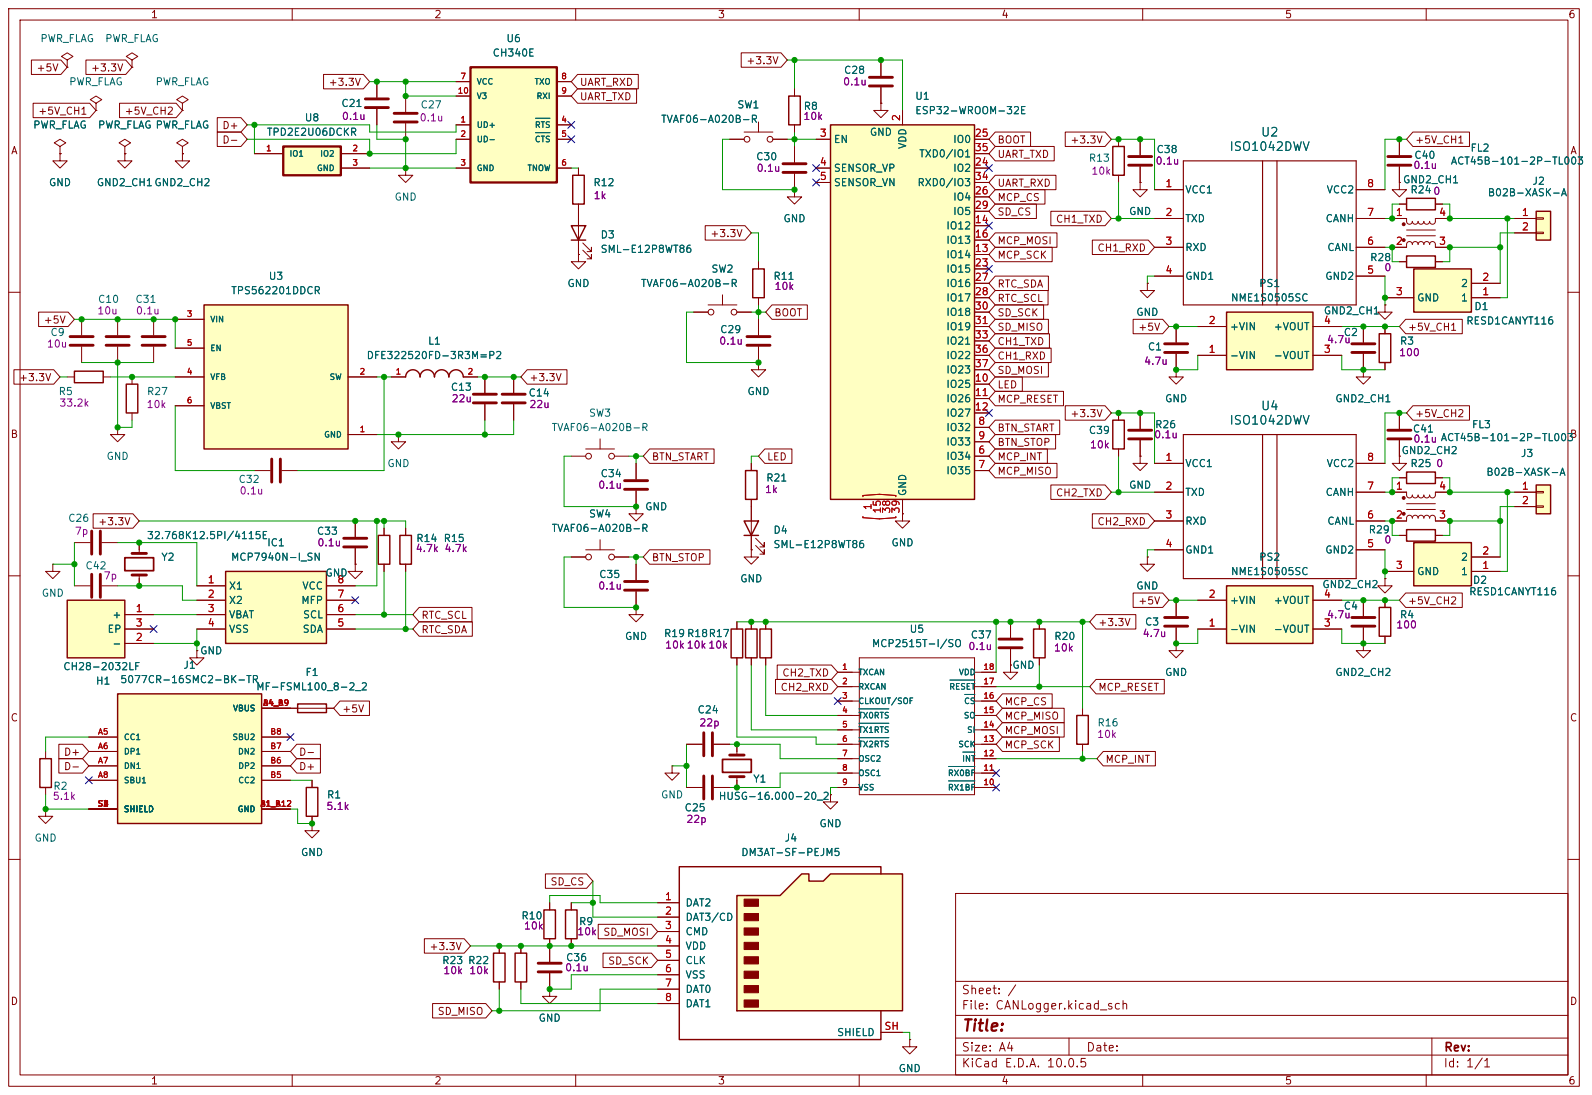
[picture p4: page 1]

TXCAN 1 RXCAN 2 CLKOUT/SOF 3

Size: A4 | Rev:
KiCad E.D.A. 10.0.5 | Id: 1/1

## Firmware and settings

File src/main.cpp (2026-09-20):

/*
 * main.cpp — CANログ取得治具 ファームウェア v2.5（2ch同時記録 + RTC）
 *
 * ビルド : PlatformIO / espressif32@6.8.1 (arduino-esp32 2.0.17)
 *            pio run            … ビルド
 *            pio run -t upload  … 書き込み
 *            pio device monitor … シリアルモニタ (115200)
 *
 * 用途 : 現場で単独でCANログを取得するための治具。
 *        PCを接続せずにSDカードへ保存し、PC側でBLFへ変換する。
 *
 * 構成 : ESP32-WROOM-32E-N16
 *          CH1 = 内蔵TWAI (Listen-Only) + ISO1042DWV     … 500 kbps
 *          CH2 = MCP2515-I/SO (HSPI, Listen-Only) + ISO1042DWV … 250 kbps
 *          SD  = VSPI / RTC = MCP7940N (I2C)
 *
 * 設計方針
 *   - 受信タスクは「タイムスタンプ付与とリングへの積み込み」だけを行う
 *   - 保存形式の生成とSD書き込みは書き込みタスク（別コア）に分離する
 *   - CH1/CH2で独立したリングを持ち、書き込み時にタイムスタンプ順にマージする
 *   - 両chともListen-Only（ACKも返さない）でバスに一切影響を与えない
 *   - 異常が起きても「そこまでのログと統計ファイルを必ず残す」（縮退保存）
 *
 * 版歴
 *   v2.0  CH1+CH2同時記録、24byte固定長バイナリ保存を既定化
 *   v2.1  コードレビュー反映
 *           - 異常時にドライバとファイルが開放されず開始ボタンで復帰できない問題を修正
 *           - 異常時も残データ書き出し・クローズ・統計出力を行う縮退保存を追加
 *           - 停止シーケンスの待ち時間を RX_TIMEOUT_MS と連動（config.h）
 *           - PlatformIO化（can_logger_jig.ino → src/main.cpp）
 *   v2.2  基板確定に伴う対応
 *           - RTC(MCP7940N) から実時刻を読み BinHeader.unix_time へ格納
 *           - シリアルコマンド（SETTIME / GETTIME / STATUS）を追加
 *           - MCP2515 の /RESET をGPIOから駆動（ハードウェアリセット）
 *           - ASCヘッダの日時をRTCの実時刻から生成
 *   v2.3  実機ログ（LOG0002）の解析で判明した取りこぼしを修正
 *           - mcpIsr() で portYIELD_FROM_ISR() を行っておらず、CH2受信タスクの
 *             起床が次のティック（最大1ms）まで遅れていた。250kbpsでは
 *             RXB0/RXB1が埋まりきる時間で、周期メッセージの1.2%が欠落していた
 *           - /INT がLowの間は通知を待たずに読み出しを継続するようにした
 *             （MCP2515の/INTはレベル出力のためエッジを取りこぼす経路があった）
 *           - RTCの発振待ちを 200ms → 5s に延長し、時刻書き込みの成否と分離した
 *             （32.768kHz水晶は起動に数百ms〜数秒かかるため誤判定していた）
 *           - 電源投入直後にSD初期化が失敗しST_ERRORになる問題を修正
 *             （周辺デバイスの立ち上がり待ち300ms + SD 5回 / MCP2515 3回のリトライ）
 *   v2.4  v2.3で作り込んだ致命的なバグを修正
 *           - rxTaskMcp() で「記録中でない」判定が /INT のチェックより後ろにあり、
 *             CH2をバスに接続した待機状態では /INT がLowに張り付いて
 *             どこでもブロックせずに回り続けていた。優先度19・コア1固定のため
 *             優先度1の loopTask が飢餓状態になり、setup()の完走・シリアル受信・
 *             ボタン・LEDがすべて停止していた
 *           - フレームを1件も読めなかった場合の保険として vTaskDelay(1) を追加
 *   v2.7  DRAM不足(dram0_0_seg overflow)の対策
 *           - リングバッファと書き込みバッファを静的確保からヒープ確保へ変更した
 *             Wi-Fi/LTEスタックの静的バッファ(約40KB)が加わると、リング(約74KB)を
 *             .bssに置いたままではリンクが通らないため
 *           - 確保失敗時は FAULT_NO_MEMORY で ST_ERROR へ落とす
 *   v2.6  ログの自動アップロード（改良仕様書 v3.3 §17.2 の P6）
 *           - Wi-Fi経由でHTTP PUTする uploader.h を追加。待機中のみ動作する
 *           - SDカードの /CONFIG.TXT から設定を読む cfgfile.h を追加
 *           - 記録開始時にアップロードを中断させ、SDとWi-Fiを手放してから始める
 *           - 起動回数カウンタ（NVS）を追加
 *           - シリアルコマンド UPLOAD / UPSTAT / WIFI / RELOAD を追加
 *         ※ 通信層以外は本番と同じ構造にしてある。P7でWi-Fi部分を
 *            SIM7600のATコマンドへ差し替える。
 *   v2.5  査読（Fable）指摘の反映
 *           - STATUS に RTC の診断フラグ（OSCRUN/PWRFAIL/VBATEN/trim）を追加
 *           - VBATEN の書き込み結果を読み戻して検証するようにした
 *           - 記録開始に失敗したときヘッダだけの空BINが残らないようにした
 *           - ドレイン中にSD書き込みが失敗した場合も統計の exit を ABNORMAL にする
 *           - TRIM コマンドを追加（水晶の周波数誤差をデジタルトリミングで補正）
 *
 * 注) 本ファイルは .ino ではないため、Arduino IDEのプロトタイプ自動生成は働かない。
 *     全ての関数は呼び出し箇所より前に定義してあるので前方宣言は不要だが、
 *     関数を追加する際は定義順に注意すること。
 *
 * 詳細は docs/DESIGN.md および docs/HARDWARE.md を参照。
 */

#include <Arduino.h>
#include <new>
#include <SPI.h>
#include <SD.h>
#include <Wire.h>
#include "driver/twai.h"
#include "esp_timer.h"

#include "config.h"
#include "ring_buffer.h"
#include "asc_format.h"
#if CH2_ENABLE
#include "mcp2515.h"
#endif
#if RTC_ENABLE
#include "mcp7940.h"
#endif
#if UPLOAD_ENABLE
#include "cfgfile.h"
#include "uploader.h"
#endif

// ============================================================
// バイナリファイルヘッダ（32byte・リトルエンディアン）
// ============================================================
struct BinHeader {
  char     magic[8];     // +0  "CANLOG02"
  uint16_t version;      // +8  2
  uint16_t record_size;  // +10 24
  uint32_t ch1_bitrate;  // +12
  uint32_t ch2_bitrate;  // +16 0 = CH2無効
  uint32_t unix_time;    // +20 計測開始のUNIX時刻(UTC)。0 = RTC無効/未設定
  uint64_t t0_us;        // +24 計測開始時刻(esp_timer基準)
};
static_assert(sizeof(BinHeader) == 32, "BinHeader must be 32 bytes");

// ============================================================
// 状態
// ============================================================
enum LoggerState : uint8_t {
  ST_IDLE,      // 待機（LED消灯）
  ST_LOGGING,   // 記録中（LED点滅）
  ST_DRAINING,  // 停止処理中（受信停止・残りを書き出し中）
  ST_STOPPED,   // 正常停止・SD取り外し可（LED点灯）
  ST_ERROR,     // 異常（LED高速点滅）
};
static volatile LoggerState g_state = ST_IDLE;

// ============================================================
// 異常要因
// ============================================================
// 記録中に異常を検出したタスクは g_fault を立てるだけにして、
// 後始末（縮退保存）は必ず loop() 側で行う。
enum FaultCode : uint8_t {
  FAULT_NONE = 0,
  FAULT_SD_INIT,
  FAULT_SD_OPEN,
  FAULT_SD_WRITE,
  FAULT_TWAI_INIT,
  FAULT_MCP_INIT,
  FAULT_BUS_OFF,
  FAULT_NO_FILENAME,
  FAULT_NO_MEMORY,
};
static volatile uint8_t g_fault = FAULT_NONE;

static const char* faultText(uint8_t f) {
  switch (f) {
    case FAULT_NONE:        return "none";
    case FAULT_SD_INIT:     return "SD card not found / mount failed";
    case FAULT_SD_OPEN:     return "cannot create log file on SD";
    case FAULT_SD_WRITE:    return "SD write failed (card full or bad contact)";
    case FAULT_TWAI_INIT:   return "CH1 TWAI driver init failed";
    case FAULT_MCP_INIT:    return "CH2 MCP2515 not responding";
    case FAULT_BUS_OFF:     return "CH1 bus off";
    case FAULT_NO_FILENAME: return "no free file name (LOG0001..LOG9999 all used)";
    case FAULT_NO_MEMORY:   return "cannot allocate ring buffers (reduce RING_SIZE_*)";
    default:                return "unknown";
  }
}

// ============================================================
// グローバル
// ============================================================
/*
 * リングバッファと書き込みバッファはヒープに置く。
 *
 * ESP32の静的データ(.bss)は dram0_0_seg という固定サイズの領域に収める必要があり、
 * ヒープとは別枠の上限がある。Wi-Fi/LTEを有効にすると通信スタックの静的バッファが
 * 約40KB積まれるため、リング(約74KB)を静的確保したままではリンクが通らない
 *   → "region `dram0_0_seg' overflowed"
 * ヒープは dram0_0_seg の外のDRAMも使えるので、大物をヒープへ移すと制約を回避できる。
 *
 * setup() でタスク生成より前に確保する。確保に失敗したらタスクを起動しない。
 */
static SpscRing<RING_SIZE_CH1>* g_ring1 = nullptr;  // CH1 (TWAI)    約49KB
#if CH2_ENABLE
static SpscRing<RING_SIZE_CH2>* g_ring2 = nullptr;  // CH2 (MCP2515)  約25KB
static SPIClass      g_hspi(HSPI);
static Mcp2515       g_mcp;
static TaskHandle_t  g_mcpTaskHandle = nullptr;
static volatile bool g_mcpReady = false;
static volatile bool g_mcpIsrOn = false;
#endif

#if RTC_ENABLE
static Mcp7940 g_rtc;
static bool   g_rtcOk = false;
#endif

#if UPLOAD_ENABLE
static AppCfg g_cfg;
#endif

static File              g_file;
static SemaphoreHandle_t g_fileMtx  = nullptr;
static volatile bool     g_flushReq = false;
static volatile bool     g_twaiOn   = false;

static volatile uint64_t g_t0_us     = 0;
static uint32_t          g_startUnix = 0;  // 記録開始時のUNIX時刻(UTC)。0 = 不明
static char g_logPath[16];
static char g_txtPath[16];

struct ChStats {
  uint32_t frames;   // リングに積めたフレーム数
  uint32_t dropped;  // リング満杯で捨てた数
  uint32_t missed;   // コントローラ段の溢れ（CH1=フレーム数 / CH2=検出イベント回数）
};
struct Stats {
  ChStats  ch1;
  ChStats  ch2;
  uint32_t bus_error_alerts;
  uint32_t sd_write_max_us;
  uint32_t sd_write_count;
  uint64_t bytes_written;
  uint32_t duration_ms;
};
static Stats g_stats;

// ============================================================
// 時刻ユーティリティ
// ============================================================
// UNIX時刻(UTC) → 現地時刻の文字列 "YYYY-MM-DD HH:MM:SS"
static void formatLocalTime(uint32_t utc, char* out, size_t len) {
  if (utc == 0) {
    snprintf(out, len, "unknown (RTC not set)");
    return;
  }
  int64_t t = static_cast<int64_t>(utc) + RTC_UTC_OFFSET_SEC;
  const int64_t days = t / 86400;
  int64_t secs = t % 86400;
  // 民用日付へ戻す（days_from_civil の逆変換）
  int64_t z = days + 719468;
  const int64_t era = (z >= 0 ? z : z - 146096) / 146097;
  const unsigned doe = static_cast<unsigned>(z - era * 146097);
  const unsigned yoe = (doe - doe / 1460 + doe / 36524 - doe / 146096) / 365;
  const int64_t  y   = static_cast<int64_t>(yoe) + era * 400;
  const unsigned doy = doe - (365 * yoe + yoe / 4 - yoe / 100);
  const unsigned mp  = (5 * doy + 2) / 153;
  const unsigned d   = doy - (153 * mp + 2) / 5 + 1;
  const unsigned m   = mp + (mp < 10 ? 3 : -9);
  snprintf(out, len, "%04lld-%02u-%02u %02lld:%02lld:%02lld",
           static_cast<long long>(y + (m <= 2)), m, d,
           static_cast<long long>(secs / 3600),
           static_cast<long long>((secs % 3600) / 60),
           static_cast<long long>(secs % 60));
}

#if LOG_FORMAT == LOG_FORMAT_ASC
// ASCヘッダ用 "Thu Aug 9 14:05:00.000 2026" 形式
static void formatAscDate(uint32_t utc, char* out, size_t len) {
  static const char* kWday[] = {"Sun", "Mon", "Tue", "Wed", "Thu", "Fri", "Sat"};
  static const char* kMon[]  = {"Jan", "Feb", "Mar", "Apr", "May", "Jun",
                                "Jul", "Aug", "Sep", "Oct", "Nov", "Dec"};
  if (utc == 0) {
    snprintf(out, len, "Thu Jan 1 00:00:00.000 1970");
    return;
  }
  char tmp[32];
  formatLocalTime(utc, tmp, sizeof(tmp));
  int Y, M, D, h, mi, s;
  if (sscanf(tmp, "%d-%d-%d %d:%d:%d", &Y, &M, &D, &h, &mi, &s) != 6) {
    snprintf(out, len, "Thu Jan 1 00:00:00.000 1970");
    return;
  }
#if RTC_ENABLE
  const uint8_t w = Mcp7940::weekdayFromCivil(static_cast<uint16_t>(Y),
                                              static_cast<uint8_t>(M),
                                              static_cast<uint8_t>(D));
#else
  const uint8_t w = 4;
#endif
  snprintf(out, len, "%s %s %d %02d:%02d:%02d.000 %d",
           kWday[w % 7], kMon[(M - 1) % 12], D, h, mi, s, Y);
}
#endif

// ============================================================
// LED
// ============================================================
static void updateLed() {
  const uint32_t now = millis();

#if UPLOAD_ENABLE
  // 待機中にアップロードしている間は「1秒周期で2回の短点滅」で区別する。
  // 消灯（何もしていない）と見分けがつかないと、現場で
  // 「治具が生きているのか」が判断できないため。
  if (uploaderActive() && (g_state == ST_IDLE || g_state == ST_STOPPED)) {
    const uint32_t t = now % LED_UPLOAD_PERIOD_MS;
    const bool on = (t < LED_UPLOAD_PULSE_MS) ||
                    (t >= LED_UPLOAD_PULSE_MS * 2 && t < LED_UPLOAD_PULSE_MS * 3);
    digitalWrite(LED_GPIO, on ? HIGH : LOW);
    return;
  }
#endif

  switch (g_state) {
    case ST_IDLE:      digitalWrite(LED_GPIO, LOW); break;
    case ST_LOGGING:
    case ST_DRAINING:  digitalWrite(LED_GPIO, ((now / LED_BLINK_LOGGING_MS) & 1) ? HIGH : LOW); break;
    case ST_STOPPED:   digitalWrite(LED_GPIO, HIGH); break;
    case ST_ERROR:     digitalWrite(LED_GPIO, ((now / LED_BLINK_ERROR_MS) & 1) ? HIGH : LOW); break;
  }
}

// ============================================================
// ボタン（GND短絡・内部プルアップ・押下エッジ検出）
// ============================================================
struct Button {
  uint8_t  pin;
  bool     stable;
  bool     last;
  uint32_t lastChange;
};
static Button g_btnStart{BTN_START_GPIO, true, true, 0};
static Button g_btnStop{BTN_STOP_GPIO, true, true, 0};

static bool buttonPressed(Button& b) {
  const bool raw = (digitalRead(b.pin) != LOW);  // HIGH = 離されている
  const uint32_t now = millis();
  if (raw != b.last) {
    b.last = raw;
    b.lastChange = now;
    return false;
  }
  if (now - b.lastChange < BTN_DEBOUNCE_MS) return false;
  if (raw == b.stable) return false;
  b.stable = raw;
  return (raw == false);  // 押された瞬間のみtrue
}

// ============================================================
// CH1 受信タスク（内蔵TWAI / core1）
// ============================================================
static void rxTaskTwai(void*) {
  for (;;) {
    if (g_state != ST_LOGGING || !g_twaiOn) {
      vTaskDelay(pdMS_TO_TICKS(10));
      continue;
    }
    twai_message_t msg;
    if (twai_receive(&msg, pdMS_TO_TICKS(RX_TIMEOUT_MS)) != ESP_OK) continue;

    CanRec rec;
    rec.ts_us    = static_cast<uint64_t>(esp_timer_get_time());
    rec.id       = msg.identifier;
    rec.dlc      = (msg.data_length_code > 8) ? 8 : msg.data_length_code;
    rec.flags    = 0;
    rec.channel  = 1;
    rec.reserved = 0;
    if (msg.extd) rec.flags |= CANREC_FLAG_EXTENDED;
    if (msg.rtr)  rec.flags |= CANREC_FLAG_RTR;
    memcpy(rec.data, msg.data, 8);

    if (g_ring1->push(rec)) g_stats.ch1.frames++;
  }
}

// ============================================================
// CH2 受信タスク（MCP2515 / core1・INT駆動）
// ============================================================
#if CH2_ENABLE
/*
 * MCP2515 の /INT ハンドラ。
 *
 * 重要: vTaskNotifyGiveFromISR() の第2引数に nullptr を渡してはいけない。
 *       渡さないとISRから抜けるときにタスク切り替えが要求されず、
 *       通知したタスクが次のティック（1ms）まで走らない。
 *       250kbpsでは8byteフレームが約444us間隔で来るため、1ms待つと
 *       RXB0/RXB1の2段がちょうど埋まり、3フレーム目で取りこぼす。
 *       （v2.2実測: 2件まとめ読み1311回・3件44回、周期メッセージの1.2%が欠落）
 */
static void IRAM_ATTR mcpIsr() {
  BaseType_t higherPriorityTaskWoken = pdFALSE;
  if (g_mcpTaskHandle) {
    vTaskNotifyGiveFromISR(g_mcpTaskHandle, &higherPriorityTaskWoken);
  }
  if (higherPriorityTaskWoken == pdTRUE) portYIELD_FROM_ISR();
}

static void rxTaskMcp(void*) {
  for (;;) {
    // 記録中でなければ必ず眠る。
    // このタスクは優先度19でコア1に固定されており、ここでブロックしないと
    // 優先度1の loopTask（setup/loop）を飢餓状態にしてしまう。
    // v2.3初版はこの判定が /INT のチェックより後ろにあったため、
    // 「CH2をバスに接続した状態で待機中」だと /INT がLowに張り付き、
    // どこでもブロックせずに回り続けてシリアルもボタンもLEDも止まった。
    if (g_state != ST_LOGGING || !g_mcpReady) {
      vTaskDelay(pdMS_TO_TICKS(10));
      continue;
    }

    // /INT がLowの間は受信バッファに未読フレームが残っている。
    // MCP2515の/INTはレベル出力なので、ドレイン中に届いたフレームでは
    // 新しい立ち下がりエッジが出ない。眠る前にピンの状態を直接見て、
    // まだLowなら通知を待たずにそのまま読み出しを続ける。
    if (digitalRead(MCP_INT_GPIO) == HIGH) {
      // 取りこぼし保険として5msでタイムアウトして必ず1回覗く
      ulTaskNotifyTake(pdTRUE, pdMS_TO_TICKS(5));
    }

    // 受信バッファが空になるまで読み切る
    uint32_t got = 0;
    for (;;) {
      CanRec rec;
      rec.ts_us    = static_cast<uint64_t>(esp_timer_get_time());
      rec.channel  = 2;
      rec.reserved = 0;
      const Mcp2515::Result r = g_mcp.readFrame(rec.id, rec.dlc, rec.flags, rec.data);
      if (r != Mcp2515::OK) break;
      if (g_ring2->push(rec)) g_stats.ch2.frames++;
      got++;
    }

    // /INT がLowのままなのにフレームが読めない異常時に
    // ビジーループへ落ちないようにする保険
    if (got == 0) vTaskDelay(1);
  }
}
#endif

// ============================================================
// SD書き込みタスク（core0）
// ============================================================
static char*    g_wbuf = nullptr;  // WRITE_CHUNK_BYTES + ASC_LINE_MAX（setup()で確保）
static size_t   g_wlen = 0;
static uint32_t g_lastFlushMs = 0;

static void flushWriteBuffer() {
  if (g_wlen == 0) return;

  // SD書き込みが一度失敗している状態では以降の書き込みを試さない。
  if (g_fault == FAULT_SD_WRITE) {
    g_wlen = 0;
    return;
  }

  if (xSemaphoreTake(g_fileMtx, pdMS_TO_TICKS(2000)) != pdTRUE) return;
  if (g_file) {
    const uint32_t t0 = micros();
    const size_t wrote = g_file.write(reinterpret_cast<uint8_t*>(g_wbuf), g_wlen);
    const uint32_t dt = micros() - t0;
    if (dt > g_stats.sd_write_max_us) g_stats.sd_write_max_us = dt;
    g_stats.sd_write_count++;
    g_stats.bytes_written += wrote;

    // 異常はここで確定させず要因だけ立てる。後始末は loop() が行う
    if (wrote != g_wlen) g_fault = FAULT_SD_WRITE;

    if (millis() - g_lastFlushMs >= FLUSH_INTERVAL_MS) {
      g_file.flush();
      g_lastFlushMs = millis();
    }
  }
  xSemaphoreGive(g_fileMtx);
  g_wlen = 0;
}

/*
 * CH1/CH2のリングからタイムスタンプの古い方を取り出す。
 * 片方のリングだけにフレームがある場合、あとから他chの古いフレームが
 * 積まれる可能性があるため MERGE_LAG_US だけ待ってから確定させる。
 * flushAll=true（停止処理中）のときは待たずに全部吐き出す。
 */
static bool popMerged(CanRec& out, bool flushAll) {
  uint64_t t1 = 0;
  const bool h1 = g_ring1->peekTs(t1);

#if CH2_ENABLE
  uint64_t t2 = 0;
  const bool h2 = g_ring2->peekTs(t2);
  if (!h1 && !h2) return false;
  if (h1 && h2) return (t1 <= t2) ? g_ring1->pop(out) : g_ring2->pop(out);

  const uint64_t now = static_cast<uint64_t>(esp_timer_get_time());
  if (h1) {
    if (!flushAll && (now - t1) < MERGE_LAG_US) return false;
    return g_ring1->pop(out);
  }
  if (!flushAll && (now - t2) < MERGE_LAG_US) return false;
  return g_ring2->pop(out);
#else
  (void)flushAll;
  if (!h1) return false;
  return g_ring1->pop(out);
#endif
}

static void writerTask(void*) {
  for (;;) {
    const bool draining = (g_state == ST_DRAINING);
    const bool active   = (g_state == ST_LOGGING || draining);
    if (!active) {
      if (g_flushReq) { flushWriteBuffer(); g_flushReq = false; }
      vTaskDelay(pdMS_TO_TICKS(10));
      continue;
    }

    CanRec rec;
    uint32_t popped = 0;
    while (g_wlen < WRITE_CHUNK_BYTES && popMerged(rec, draining)) {
#if LOG_FORMAT == LOG_FORMAT_ASC
      g_wlen += formatAscLine(&g_wbuf[g_wlen], rec, g_t0_us);
#else
      memcpy(&g_wbuf[g_wlen], &rec, sizeof(CanRec));
      g_wlen += sizeof(CanRec);
#endif
      popped++;
    }

    if (g_wlen >= WRITE_CHUNK_BYTES) {
      flushWriteBuffer();
    } else if (g_flushReq) {
      flushWriteBuffer();
      g_flushReq = false;
    } else if (popped == 0) {
      vTaskDelay(1);  // 到着待ち
    }
  }
}

// ============================================================
// 後始末（異常時・起動時の防御用）
//   どの状態から呼ばれても安全に「何も掴んでいない状態」へ戻す。
// ============================================================
static void hardCleanup() {
#if CH2_ENABLE
  if (g_mcpIsrOn) {
    detachInterrupt(digitalPinToInterrupt(MCP_INT_GPIO));
    g_mcpIsrOn = false;
  }
  g_mcpReady = false;
#endif

  if (g_twaiOn) {
    twai_stop();
    twai_driver_uninstall();
    g_twaiOn = false;
  }

  if (xSemaphoreTake(g_fileMtx, pdMS_TO_TICKS(3000)) == pdTRUE) {
    if (g_file) {
      // 記録が始まる前に失敗した場合、ヘッダだけの空ファイルが残って
      // 番号が欠番になる。中身が無いものは消しておく。
      g_file.flush();
      const size_t written = g_file.size();
      g_file.close();
      if (written <= sizeof(BinHeader) && g_logPath[0] != '\0') {
        SD.remove(g_logPath);
        SD.remove(g_txtPath);
      }
    }
    xSemaphoreGive(g_fileMtx);
  }
  g_wlen = 0;
}

// ============================================================
// ファイル名の採番
// ============================================================
static bool buildNextFileNames() {
#if LOG_FORMAT == LOG_FORMAT_ASC
  const char* ext = "ASC";
#else
  const char* ext = "BIN";
#endif
  for (uint16_t i = 1; i <= 9999; i++) {
    snprintf(g_logPath, sizeof(g_logPath), "/LOG%04u.%s", i, ext);
    snprintf(g_txtPath, sizeof(g_txtPath), "/LOG%04u.TXT", i);
    // 統計ファイルだけ残っているケースを踏まないよう両方を確認する
    if (!SD.exists(g_logPath) && !SD.exists(g_txtPath)) return true;
  }
  return false;
}

// ============================================================
// 記録開始
// ============================================================
static bool startLogging() {
  // バッファ確保に失敗している場合は何もしない（setup()でタスクも起動していない）
  if (!g_ring1 || !g_wbuf
#if CH2_ENABLE
      || !g_ring2
#endif
  ) {
    g_fault = FAULT_NO_MEMORY;
    return false;
  }

#if UPLOAD_ENABLE
  // アップロードが走っているとSDハンドルを掴んだままなので、
  // SD.end() / SD.begin() より前に必ず手放させる。
  // Wi-Fiも落とす。記録中はCPUもSDもCAN受信に使い切る。
  uploaderRequestStop();
  if (!uploaderWaitIdle(3000)) {
    Serial.println("[WARN] uploader did not stop in time. proceeding anyway.");
  }
  uploaderWifiOff();
#endif

  // 直前が異常終了でも確実に開始できるよう、まず掴んでいるものを全て開放する
  hardCleanup();
  g_fault = FAULT_NONE;

  // --- 実時刻の取得（失敗しても記録は続行する） ---
  g_startUnix = 0;
#if RTC_ENABLE
  if (g_rtcOk) {
    g_startUnix = g_rtc.readUnixTimeUtc();
    if (g_startUnix == 0) {
      Serial.println("[WARN] RTC time is not set. use SETTIME command.");
    }
  }
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
void loop() {
  updateLed();
  pollSerial();

  if (g_state == ST_LOGGING) {
    pollControllerStatus();
    // 記録中に異常を検出したら、そこまでのログと統計を残して縮退終了する
    if (g_fault != FAULT_NONE) finalizeLogging(true);
  }

  if (buttonPressed(g_btnStart)) {
    if (g_state == ST_IDLE || g_state == ST_STOPPED || g_state == ST_ERROR) {
      if (!startLogging()) {
        hardCleanup();
        g_state = ST_ERROR;
        Serial.printf("[ERR] start failed: %s\n", faultText(g_fault));
#if UPLOAD_ENABLE
        // 記録が始まらなかったので、アップロードを再開させる。
        // ここで解除しないと中断要求が残ったままになる
        uploaderResume();
#endif
      }
    }
  }
  if (buttonPressed(g_btnStop)) {
    if (g_state == ST_LOGGING) finalizeLogging(false);
  }

  delay(5);
}

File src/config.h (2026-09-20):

/*
 * config.h — CANログ取得治具 設定  v2.5
 *
 * ターゲット: ESP32-WROOM-32E-N16 (arduino-esp32 2.0.17 / PlatformIO)
 *
 *   CH1 : ESP32内蔵TWAI  + ISO1042DWV     … 500 kbps（CANalyzer CAN1相当）
 *   CH2 : MCP2515-I/SO (HSPI) + ISO1042DWV … 250 kbps（CANalyzer CAN2相当）
 *   RTC : MCP7940N-I/SN (I2C) + 32.768kHz水晶
 *
 * 本ファイルの主要な設定値は #ifndef ガードを付けてあるため、
 * platformio.ini の build_flags から -D で上書きできる。
 *   例) build_flags = -DCH2_ENABLE=0 -DCH1_BITRATE=250000UL
 */
#pragma once

#include <stdint.h>

// ============================================================
// 保存形式
// ============================================================
//   LOG_FORMAT_BIN : 24byte固定長バイナリ（既定・推奨）
//                    SD負荷が約1/3。PC側で BIN → BLF を直接生成する
//   LOG_FORMAT_ASC : Vector ASCテキスト（現地でテキスト確認したいときのデバッグ用）
#define LOG_FORMAT_BIN 0
#define LOG_FORMAT_ASC 1
#ifndef LOG_FORMAT
#define LOG_FORMAT LOG_FORMAT_BIN
#endif

// ============================================================
// ビットレート（CANalyzer側のCAN1/CAN2設定に合わせる）
// ============================================================
#ifndef CH1_BITRATE
#define CH1_BITRATE 500000UL // 内蔵TWAI : 500k / 250k / 125k を選択可
#endif
#ifndef CH2_BITRATE
#define CH2_BITRATE 250000UL // MCP2515  : 500k / 250k / 125k を選択可
#endif
#ifndef CH2_ENABLE
#define CH2_ENABLE 1         // 0にするとCH1のみで動作（MCP2515未実装基板の検証用）
#endif

// ============================================================
// CH1: ESP32内蔵TWAI
// ============================================================
#define CAN1_TX_GPIO GPIO_NUM_21 // ISO1042 TXD（Listen-Onlyでは駆動されない）
#define CAN1_RX_GPIO GPIO_NUM_22 // ISO1042 RXD
#define TWAI_RX_QUEUE_LEN 128    // ドライバ側RXキュー段数

// ============================================================
// CH2: MCP2515（HSPI・SDとは別バス）
// ============================================================
#define MCP_SCK_GPIO   14
#define MCP_MOSI_GPIO  13
#define MCP_MISO_GPIO  35 // 入力専用GPIO。GPIO12(ストラップピン)を避けるため
#define MCP_CS_GPIO    4
#define MCP_INT_GPIO   34 // 入力専用GPIO。外部10kΩプルアップ必須
#define MCP_RESET_GPIO 26 // /RESET。10kΩでプルアップした上でGPIOからも駆動する
#define MCP_SPI_HZ     10000000UL
#define MCP_XTAL_HZ    16000000UL // 治具基板の水晶。16MHz固定（mcp2515.hの定数表と対応）

// ============================================================
// SDカード（VSPI）
// ============================================================
#define SD_CS_GPIO   5
#define SD_SCK_GPIO  18
#define SD_MISO_GPIO 19
#define SD_MOSI_GPIO 23
#define SD_SPI_HZ    20000000UL

// ============================================================
// RTC: MCP7940N-I/SN（I2C）
// ============================================================
#ifndef RTC_ENABLE
#define RTC_ENABLE 1         // 0にするとRTCを読まない（未実装基板の検証用）
#endif
#define RTC_SDA_GPIO 16
#define RTC_SCL_GPIO 17
#define RTC_I2C_HZ   400000UL
#define RTC_I2C_ADDR 0x6F    // MCP7940N（DS3231の0x68とは別なので注意）

// RTCが保持する時刻のUTCからのオフセット[秒]。
// 現地作業者が見やすいようRTCには「日本時間」を設定する運用とし、
// BINヘッダには常にUTCのUNIX時刻を格納する（PC側で正しく表示させるため）。
#ifndef RTC_UTC_OFFSET_SEC
#define RTC_UTC_OFFSET_SEC (9 * 3600) // JST = UTC+9
#endif

// ============================================================
// 操作系
// ============================================================
#define BTN_START_GPIO 32 // 押しボタン（GND短絡、内部プルアップ使用）
#define BTN_STOP_GPIO  33
#define LED_GPIO       25 // 状態表示LED（直列抵抗1kΩ程度必須）
#define BTN_DEBOUNCE_MS 30

#define LED_BLINK_LOGGING_MS 200 // 記録中：ゆっくり点滅
#define LED_BLINK_ERROR_MS   80  // 異常  ：高速点滅

// ============================================================
// バッファリング
// ============================================================
// リングバッファ段数（2のべき乗必須）。1段=24byte
//   CH1: 2048段 = 49KB ≒ 4,000 frame/s で約0.5秒分
//   CH2: 1024段 = 25KB ≒ 2,250 frame/s で約0.45秒分
// v2.7以降はヒープ確保なので、DRAMの静的領域(dram0_0_seg)の制約は受けない。
// 増やす場合は setup() の "buffers:" 行と STATUS の freeheap で余裕を確認すること。
#ifndef RING_SIZE_CH1
#define RING_SIZE_CH1 2048
#endif
#ifndef RING_SIZE_CH2
#define RING_SIZE_CH2 1024
#endif

// 2chのタイムスタンプ順序をそろえるための待ち時間[us]。
// 片方のリングだけにフレームがある場合、この時間だけ待ってから書き出す。
#define MERGE_LAG_US 5000

#define WRITE_CHUNK_BYTES 4096   // SDへの1回の書き出しサイズ
#define FLUSH_INTERVAL_MS 2000   // FAT更新周期（電源断時の被害を限定する）

// ============================================================
// アップロード機能（P6: Wi-Fi版）
// ============================================================
// SSID・送信先などの可変パラメータはSDカードの /CONFIG.TXT から読む。
// ここにあるのはコードの構造に関わる固定値のみ。
//
// 注) 0にすると WiFi.h ごとリンクされなくなり、ヒープが約40KB戻る。
//     アップロードを使わない現場向けビルドではこちらを選ぶ。
#ifndef UPLOAD_ENABLE
#define UPLOAD_ENABLE 1
#endif

#define UP_TASK_PRIO       3     // writerTask(5) より低くする
#define UP_TASK_CORE       0     // 受信タスク(core1)と分離する
#define UP_TASK_STACK      8192
#define UP_WIFI_TIMEOUT_MS 20000 // Wi-Fi接続のタイムアウト
#define UP_HTTP_TIMEOUT_MS 15000 // 1パートのHTTP応答待ち

// 待機中にアップロード動作を示すLEDパターン（1秒周期で2回の短点滅）
#define LED_UPLOAD_PERIOD_MS 1000
#define LED_UPLOAD_PULSE_MS  60
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
